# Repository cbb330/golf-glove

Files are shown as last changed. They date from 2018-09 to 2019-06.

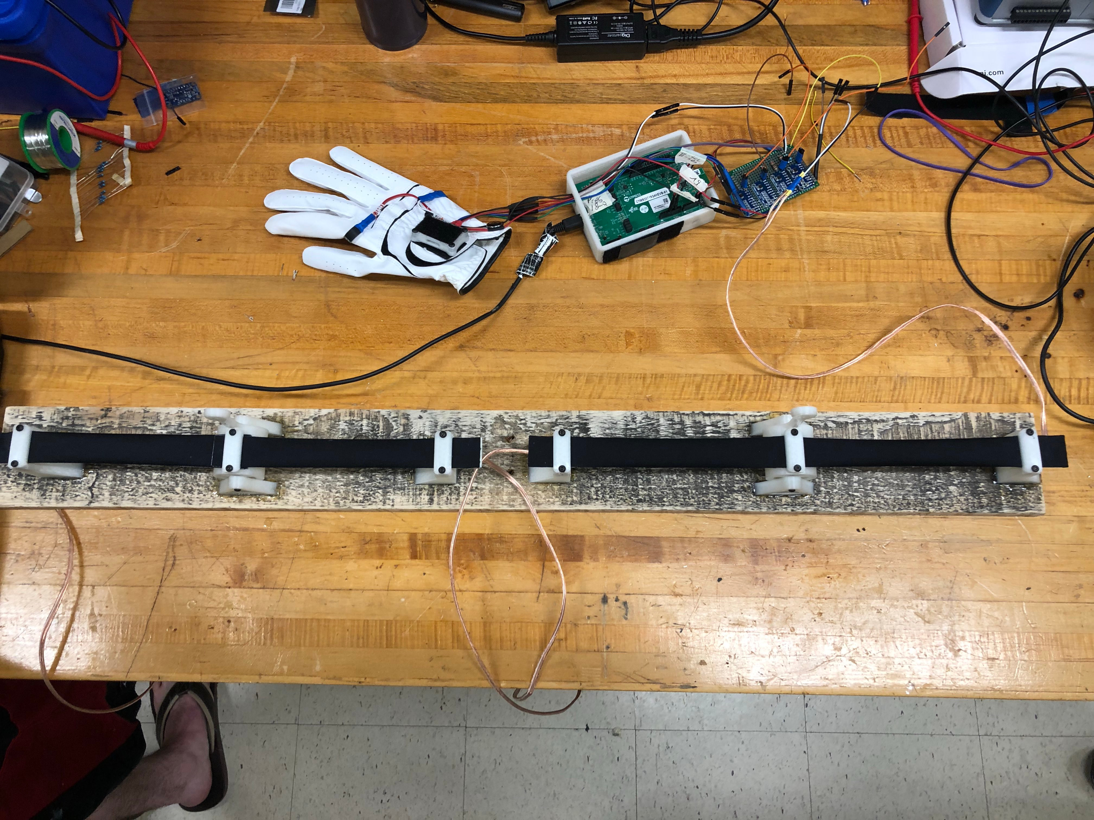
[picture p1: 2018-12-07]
website/images/hardware_demo1.jpg

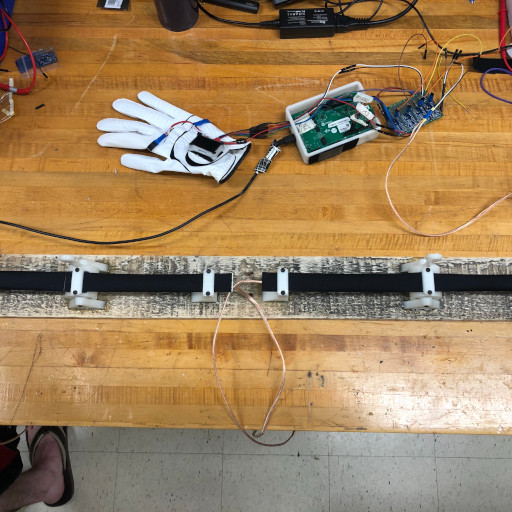
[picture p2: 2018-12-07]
website/images/hardware_demo1_reduced.jpg

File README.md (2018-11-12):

# Golf Glove
Senior Design Repository

## Firmware Quick-Reference
The Golf Glove device uses Bluetooth Low Energy (minimum BT v4.0) using the [Generic ATTribute](https://en.wikipedia.org/wiki/Bluetooth_Low_Energy#GATT_operations) (GATT) profile, an application layer protocol.

* [Golf Glove GATT Service Reference](firmware/GATT.md)

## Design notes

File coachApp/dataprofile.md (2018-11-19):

# Golf Glove Frontend Data Reference

## test route
```javascript
{
  timestamp: number,
  pressure1: number,
  pressure2: number,
  deflection: number,
  extension: number,
  radialDeviation: number,
  ulnarDeviation: number,
  imu1: {
    accelX: number,
    accelY: number,
    accelZ: number,
    magX: number,
    magY: number,
    magZ: number,
    gyroX: number,
    gyroY: number,
    gyroZ: number
  },
  imu2: {
    accelX: number,
    accelY: number,
    accelZ: number,
    magX: number,
    magY: number,
    magZ: number,
    gyroX: number,
    gyroY: number,
    gyroZ: number
  },
  swingSync: ['0', '1', '2'],
  dataAvailable: boolean
}
```

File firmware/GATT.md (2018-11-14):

# Golf Glove GATT Service Reference #

## `golf-glove` Service ###
| Property | Value |
| --- | --- |
| Name | `golf-glove` |
| UUID | `3a c5 98 d6 1b 7e 42 2e b5 f1 34 fe 48 89 83 7c` (MSB -> LSB) |
| Description | Vendor Specific Service: golf_glove |

### `next_frame` Characteristic ###
| Property | Value |
| --- | --- |
| Name | `next_frame` |
| UUID | `5a 41 42 57 d5 13 4c 6f b8 ab 53 43 8a 86 35 6c` (MSB -> LSB) |
| Actions | Read, Notify, Indicate |
| Description | Returns the data frame from the front of the data buffer, if no frame is present, an empty frame will be sent. |

The data returned by reading this characteristic is a **54-byte** value with the following format:

| Bytes | Name | Encoding |
| --- | --- | --- |
| 0-3 | Timestamp | Unsigned 32-bit counter that increments by 1 for each frame. Can be converted to a time offset for frames by multiplying the difference in two frames' timestamps by 1 / Sensor Refresh Rate. |
| 4-5 | Pressure Sensor 1 | Unsigned 16-bit integer indicating the pressure applied to Pressure Sensor 1. |
| 6-7 | Pressure Sensor 2 | [See above] |
| 8-9 | Wrist Deflection | Unsigned 16-bit integer representing the angle of wrist deflection as indicated by the upper soft robotic sensor. |
| 10-11 | Wrist Extension | Unsigned 16-bit integer representing the angle of wrist extension as indicated by the lower soft robotic sensor. |
| 12-13 | Radial Deviation | Unsigned 16-bit integer representing the angle of radial deviation (turning of the right hand to the left, or vice versa) as indicated by the outside soft robotic sensor. |
| 14-15 | Ulnar Deviation | Unsigned 16-bit integer representing the angle of ulnar deviation (turning of the right hand to the right, or vice versa) as indicated by the inside soft robotic sensor. |
| 16-33 | Wrist IMU | Inertial data as indicated by wrist-mounted IMU [See table below for details] |
| 34-51 | Hand IMU | Inertial data as indicated by hand-mounted IMU [See table below for details] |
| 52-53 | Swing Sync | 0 = middle of swing or real-time mode data point, 1 = beginning of swing, 2 = end of swing |
| 54-55 | Data Available | 0 = no more frames to fetch in frame buffer, 1 = more frames to fetch in frame buffer |

IMU Data Format:

| Bytes | Name | Encoding |
| --- | --- | --- |
| 0-1 | Acceleration X | Signed 16-bit integer indicating acceleration on the X axis -32768 to 32767 scales to +/- 2g. |
| 2-3 | Acceleration Y | Signed 16-bit integer indicating acceleration on the Y axis -32768 to 32767 scales to +/- 2g. |
| 4-5 | Acceleration Z | Signed 16-bit integer indicating acceleration on the Z axis -32768 to 32767 scales to +/- 2g. |
| 6-7 | Magnetic Field X | Signed 16-bit integer indicating magnetic field on the X axis -32768 to 32767 scales to +/- 4 gauss. |
| 8-9 | Magnetic Field Y | Signed 16-bit integer indicating magnetic field on the Y axis -32768 to 32767 scales to +/- 4 gauss. |
| 10-11 | Magnetic Field Z | Signed 16-bit integer indicating magnetic field on the Z axis -32768 to 32767 scales to +/- 4 gauss. |
| 12-13 | Rotation X | Signed 16-bit integer indicating rotation on the X axis -32768 to 32767 scales to +/- 2000 dps. |
| 14-15 | Rotation Y | Signed 16-bit integer indicating rotation on the Y axis -32768 to 32767 scales to +/- 2000 dps. |
| 16-17 | Rotation Z | Signed 16-bit integer indicating rotation on the Z axis -32768 to 32767 scales to +/- 2000 dps. |

### `realtime_enabled` Characteristic ###
| Property | Value |
| --- | --- |
| Name | `realtime_enabled` |
| UUID | `59 92 53 7e 1b 6d 41 78 ba 27 22 fa b3 8c e4 72` (MSB -> LSB) |
| Actions | Read, **TODO: WRITE**, Notify, Indicate |
| Description | Sets whether the swing detection algorithm will be used or if data will be continuously streamed to the device. |

### `data_available` Characteristic ###
| Property | Value |
| --- | --- |
| Name | `data_available` |
| UUID | `90 93 34 aa c6 ce 4b d0 95 ab 73 98 33 ae f7 bd` (MSB -> LSB) |
| Actions | Read, Notify, Indicate |
| Description | Returns a boolean value indicating whether data is available to be read from the frame buffer. |

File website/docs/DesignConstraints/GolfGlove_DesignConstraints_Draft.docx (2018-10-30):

# 2. Design Requirements/Constraints

The golf glove will use an unobtrusive design consisting of stretch and orientation sensors to accurately measure the movement of the hand and display this information to the golfer. The glove will consist of two systems: the garment with integrated peripherals, and a wrist-mounted controller. The controller will gather the information gained from the integrated sensors, and broadcast it to a desktop application that will receive and process this information. This data will then be displayed to the user and allow the user to gain valuable insight into his/her swing. In order to make this product functional, as well as acceptable to the consumer, there are technical and practical design constraints.

## 2.1. Technical Design Constraints

Table 2.1. Technical Design Constraints

Name | Description
Hand Orientation and Position | The glove must accurately determine wrist flexion and extension, wrist deviation, wrist acceleration, hand orientation, and hand acceleration.
Wireless Communication | The wrist-mounted controller must communicate wirelessly with a minimum range of 20 feet.
Data Display | The system will communicate its measurements to a desktop in real-time where an application will display them through a simple interface in a web browser.
Comfortable | The user must not feel obstructed while gripping the club with the glove on.
Portability | The wrist-mounted microcontroller must be battery powered and not require recalibration on startup.

### 2.1.1 Hand Orientation

The golf glove must measure forearm, wrist, and hand orientation to within a 5° margin of error and the hand position within a 5cm margin of error. The position measurement will be used to calculate velocity and acceleration of the hands. These margins of error will allow the glove to fulfill its purpose of tracking the wrist’s biomechanics to such a degree that meaningful feedback can be given to the user.

### 2.1.2 Wireless Communication

The golf glove must be able to reliably maintain a connection with the data display over a maximum distance of 20 feet. This enables the user to use the product without keeping the mobile device on their person. Users must be able to store mobile devices nearby, as in a golf cart or bag, while still connected so that recorded golf swings can be easily viewed after performing one or more hits. In the event of a lost wireless connection, the golf glove must be able to store several golf swings on-board until the connection is reestablished.

### 2.1.3 Data Display

The golf glove will transmit data to a computer where an application will display the measured data. A display is necessary to show the gathered data to the user in addition to providing feedback, an essential component of the system. The application will be web-based to allow similar interaction on a mobile device in the future.

### 2.1.4 Comfortable

The target audience for this product is a golfer that is trying to improve. Therefore, the golf glove will aim to be as unobtrusive to the golfer’s performance as possible. The hand will be covered with intricately placed sensors that will not require a readjustment in grip and will not induce friction to the user. Also, the wrist housing will not prevent proper flexion and extension throughout the swing.

### 2.1.5 Portability

The device must be small enough to fit comfortably on the user’s wrist without hindering or hampering their normal golf technique. A system that negatively affects the user’s swing defeats the device’s purpose given the device must accurately be able to track the user’s swing. The device must also utilize a battery system to avoid any lengthy wires that may hinder user performance. The device must not require any additional calibration steps from the user. By removing the need to calibrate before every use, the user is required to complete less work to get the device up and running, allowing for quick and easy use of the device. The entire system must be able to fit in a pocket of the user’s golf bag either , allowing the user to easily bring the device onto the golf course without any separate carrying case or bag.

## 2.2. Practical Design Constraints

The table below details the practical design constraints to be considered while designing the glove.

Table 2.2 Practical Design Constraints

Type | Name | Description
Economic | Cost | The golf glove must cost less than $200.
Environmental | Weather-Resistant | The glove must be IP54 water and dust resistant.
Health and Safety | Swing Form | The glove encourages proper swing form which helps prevent unnecessary stress and injury.
Manufacturability | Modular/Replaceable Parts | The glove unit will need to be modular to accommodate different glove sizes and handedness.
Sustainability | Battery Life, Safety, and Rechargeability | The glove must have a battery life of at least 5 hours for an 18-hole round of golf.

### 2.2.1 Economic

The total cost of the sensor glove and controller must be under $200 in order to make the golf glove competitive to other products on the market. Though some other golf tracking products are in this price range, the additional functionality available with the golf glove through flexion and extension sensors justifies the price. The golf glove must be replaceable separately from the controller in order to further improve affordability for the user.

### 2.2.2 Environmental

Due to sustained use in potentially wet and/or dusty environments, the product design must conform to the Ingress Protection (IP) standard. Specifically, our product needs to pass the IP54 standard described in the EN 60529 standard document [1]. The product’s main enclosure and sensors will be shielded from dust accumulation and water sprays.

### 2.2.3 Health and Safety

Since the product is designed to be used as a training aid it must not harm the user during normal operation. One of the objectives to the golf glove is to promote good swing technique and indicate to the user about behavior that is hazardous to health, such as gripping too hard in the top half of the hand during swinging. The glove will be made out of materials appropriate to remain comfortable for the product’s sustained use. Also, the golf glove must remain operational

### 2.2.4 Manufacturability

The design much make efficient use of current off-the-shelf systems wherever possible. Creating a “System of Systems” removes potential issues caused by working with new or unfamiliar technologies. Therefore, it will be important to utilize systems that have large amounts of community and/or manufacturer support. The system must be swappable between different glove sizes and shapes, allowing users of different hand sizes to use the system effectively. In the event of a depleted battery, the system must account for user/technician replacement to reduce waste and allow for prolonged system use. Components and housing must be designed to decrease the complexity of manufacturing allowing for an efficient creation on a production line.

### 2.2.5 Sustainability

The design must contain a battery/power-system that is sufficient to power the device for a minimum of 5 hours. This will allow the user to effectively use the device throughout an average 18-hole round of golf. The power-system must contain a protection circuit to prevent over-discharge, overcharge, and short circuit situations. Over-discharge can occur when the user forgets to turn the device off, and will permanently damage the battery. Overcharge can occur in the event of a charger malfunction and can cause rapid discharge of the battery. Lastly, short circuits can occur in events of corrosion, and internal shorts in the circuit. A protection circuit is necessary to protect the user from these potential, scenarios. The glove must be able to charge in under 2.5 hours using either an on-board charging circuit or an external charger. By keeping the charge time below 2.5 hours, the user can theoretically charge between holes or “hot swap” between multiple wrist units. Ideally the charging time should be less than or equal to half of the operating time of the device.

# References

[1] Secure Systems and Technologies. (2018). Ingress Protection. [online] Available at: http://sst.ws/downloads/Ingress-Protection-iss-4.pdf [Accessed 19 Sep. 2018].

Golf Glove 2018

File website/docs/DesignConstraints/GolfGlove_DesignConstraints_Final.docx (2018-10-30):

# 2. DESIGN REQUIREMENTS/CONSTRAINTS

The Golf Glove must have an unobtrusive design that incorporates stretch and orientation sensors. These sensors are crucial to the product’s goal of accurately measuring hand movement that will be displayed to the user. The design must consist of three systems: the garment with integrated peripherals, the wrist-mounted controller, and the coaching software. The garment must measure the user’s hand orientation, hand velocity, and wrist motion via its integrated sensors and pass these metrics to the controller. The controller must then broadcast the swing data to a desktop coaching application. This application must display the data giving the user valuable insight into their swing. To achieve the expected functionality and appeal to the user, the design must conform to the following technical and practical design constraints.

## 2.1. Technical Design Constraints

The Golf Glove must collect data, incorporate a real-time display, and be convenient to the user. Table 2.1 identifies five constraints to the technical performance of the system that will be further detailed in their respective subsections. The device must meet these constraints to ensure accurate and reliable function.

Table 2.1. Technical Design Constraints

Name | Description
Hand Orientation | The glove must determine the angles of wrist flexion, extension, and deviation within a 3° margin of error. Also, the glove must measure wrist acceleration, hand orientation, and hand acceleration within a 5% margin of error.
Wireless Communication | The wrist-mounted controller must communicate wirelessly with a range that will span the average width of a tee box: 30 feet.
Data Display | The system must communicate its measurements to a visual application that will display these metrics through a simple interface. The data can be analyzed after recording a swing, or real-time with both modes supporting a data rate of 100 hertz.
Unobtrusive | The user must not be obstructed while gripping the club with the glove on. The wrist-mounted computer must have a footprint smaller than the average sweat-band size of 3 inches. The sensor wires in the glove must not interfere with swing motion.
Portability | The wrist-mounted controller must be battery powered and not require manual calibration on start-up. The minimum battery life of the system must exceed 5 hours of use.

### 2.1.1. Hand Orientation

The Golf Glove must measure forearm, wrist, and hand orientation to within a 3° margin of error and the hand velocity within a 5% margin of error. The standard shaft length for a driver golf club is 1.1 m [1]. Using this measurement, a 3° rotation of the wrist amounts to a 5.8 cm movement of the club head, which allows the club head location to be estimated to within one-half of its length [2]. The average golfer’s swing speed is about 32 m/s, meaning a 5% margin of error in hand velocity will measure the swing speed to within 1.2 m/s [3].

### 2.1.2. Wireless Communication

The Golf Glove must maintain a connection with the data display up to a maximum distance of 30 feet. According to Jeff Brauer, a columnist for Golf Course Industry, tee box dimensions vary due to number of expected players. He states that the white tee box, the most common tee box to start from, is normally the only one that may exceed 30 feet in width [4]. Conforming to this constraint enables the product to be fully operational without making the user keep a computer device on their person. Users can store mobile devices nearby, as in the user’s pocket or in a golf cart, while still connected. In the event of a dropped wireless connection, the Golf Glove must be able to store several golf swings in memory until the connection is reestablished.

### 2.1.3. Data Display

The Golf Glove must transmit data to a computer application that will display the measured data. A display application is necessary to show the gathered data to the user in addition to providing feedback, an essential component of the system. The display must incorporate graphs to show hand pressure, hand acceleration, hand rotation, wrist flexion, and wrist extension over time. The device must be capable of collecting data in two modes. In Swing Detection Mode, data must be recorded upon swing detection and sent to the display application upon swing conclusion. The application can then analyze the swing data as one complete motion. A second mode, Real-Time Mode, must collect the sensor data and transmit it to the display application as it is collected. Real-time data display allows the user to practice certain key postures during the swing and ensure that their wrist angles and positions are correct.

### 2.1.4. Unobtrusive

Since the target audience for this product is a golfer who is trying to improve, the Golf Glove must be as unobtrusive to the golfer’s swing performance as possible. On average, male’s hands are larger than female hands. In order to fit most of our users, we need a circuit board footprint that can be small enough to fit on both genders. The average width of a female’s hand is 7.52 cm [5]. Therefore, the device’s footprint must be less than 4 cm in length and width to fit comfortably on the back of the hand.

Also, the wrist housing must not impede proper flexion and extension so the user can maintain a full range of motion. The two main factors for the size of the wrist controller are band width and circumference. The band’s width must be larger than 3 in, the width of a common sweat band. The circumference must be adjustable from 5.5 in to 9 in to accommodate a normal range of wrist sizes [6].

### 2.1.5. Portability

To avoid lengthy wires that may hinder user performance, the device must incorporate a battery system. Additionally, the Golf Glove must not require any additional calibration steps from the user. By removing the need to calibrate, the user avoids an unnecessarily delay in their swing preparation. The garment and controller system must fit in a user’s golf bag pocket, allowing the user to easily bring the device onto the golf course without a separate carrying case or bag.

## 2.2. Practical Design Constraints

Table 2.2 details the practical design constraints for the glove design. Five practical design constraints were selected: economic, environmental, health and safety, manufacturability, and sustainability. Adhering to these constraints will create a low-cost solution that is suited to a golf environment and ultimately values user ease-of-use.

Table 2.2. Practical Design Constraints

Type | Name | Description
Economic | Cost | The Golf Glove must cost less than $200.
Environmental | Weather-Resistant | The glove must be IP54 water and dust resistant.
Health and Safety | Swing Form | The glove must encourage proper swing form which helps prevent unnecessary stress and injury.
Manufacturability | Modular/Replaceable Parts | The garment and controller must be modular and allow swapping if a subsystem fails.
Sustainability | Battery Life, Safety, and Rechargeability | The glove must have adequate battery life of at least 5 hours.

### 2.2.1. Economic

The total cost of the sensor glove and controller must be under $200 to make the Golf Glove competitive to other products on the market. Although other golf tracking products are around this price, the Golf Glove’s additional functionality that specifically tracks and analyzes wrist movement through flexion and extension sensors justifies the price. Additionally, the glove component must be separate from the controller to make either part replaceable for a lower cost than replacing the entire device.

### 2.2.2. Environmental

Due to the need for sustained use in potentially wet or dusty environments, the Golf Glove’s design must conform to the Ingress Protection (IP) standard. The product’s main enclosure and sensors must be unaffected by dust accumulation and water sprays.

### 2.2.3. Health and Safety

Since the Golf Glove is designed to be a consumer training aid, it must not harm the user during normal operation. The main objective for the device is to promote proper swing technique; this includes indicating and correcting improper and harmful form. For example, gripping the golf club too hard in the top half of the hand during a swing can result in elbow injuries [7]. The glove will measure pressure on the top and bottom halves of the palm so that the user can be notified when they are putting too much pressure on the club with the wrong fingers. The coaching application must compare the users swing to one with proper form to identify deviations from proper technique. Promoting proper technique will result in fewer unnecessary injuries. Following, the device must inherently promote the user’s health.

### 2.2.4. Manufacturability

The design must efficiently use of modern, easily-sourced components wherever possible. Therefore, Golf Glove must use components that have large amounts of community and manufacturer support. The garment and wrist controller must be modular to allow the user to replace either piece without having to replace the other. In the event of a depleted battery, the system must account for replacement to reduce waste and allow for prolonged system use. The components and housing must allow for efficient creation on a production line.

### 2.2.5. Sustainability

The design must contain a battery system of sufficient capacity to power the device for a minimum of 5 hours. This time constraint will ensure the device is operation throughout an average 18-hole round of golf [8]. The power system must contain a protection circuit to prevent overcharge, overdischarge, and short circuit situations. Overdischarge occurs when the user forgets to turn the device off and results in a permanently damaged battery. Overcharge occurs in the event of a charger malfunction and can cause rapid discharge of the battery into unwanted places. Overcharge and overdischarge are characterized by the battery reaching a voltage over 4.2 V or under 3.0 V respectively [9]. Lastly, short circuits occur in events of corrosion and cause may damage to the circuit itself. The battery must charge in under 2.5 hours so that the user could theoretically charge it between their free time between golf holes.

## 2.3. Appropriate Engineering Standards

The engineering standards identified in Table 2.3 target the environmental and health and safety constraints for the device.

Table 2.3. Appropriate Engineering Standards

Specific Standard | Standard Document | Specification/Application
IP54 | EN 60529 | Rule 5 for dust protection states that the dust quantity allowed to enter or deposit on the system does not impact the system’s functionality. Rule 4 for water protection states that water sprayed from any direction against the machine must not cause damage [10].
Restriction of Hazardous Substances Compliance | RoHS-1 | The device must not contain substances banned under RoHS [11].
ICNIRP High Frequency EMR Guidelines | ICNIRP | Whole body and local body Specific Absorption Rate due to human exposure to RF fields from wireless devices must not exceed certain levels [12].

### 2.3.1. Environmental

The device must adhere to the IP54 standard. Defined in Table 2.3, the IP54 standard qualifies the dust and water ingress to the device. IP54 provides a sufficient level of protection from both dust and water, which are two environmental factors that golfers often face. The standard states that while water and dust may interact with the device, the device operation must not be harmed [10].

### 2.3.2. Environmental Materials

The device must be RoHS compliant. RoHS details several hazardous materials that should not be used in consumer products. To achieve compliance, the design must not contain any of the materials listed so that the device will not result in excess pollution when discarded or cause harm to the user. RoHS is defined in depth throughout Directive 2002/95/EC of The European Parliament [13].

### 2.3.3. Health and Safety

The device must conform to the International Commission on Non-Ionizing Radiation Protection (ICNIRP) standards for limiting exposure to electromagnetic radiation (EMR) fields. To achieve this, the device radiation will be measured with International Electrotechnical Commission (IEC) 62209 which defines standards surrounding the Specific Absorption Rate (SAR) due to human interaction with Radiofrequency (RF) EMR [14]. Following the ICNIRP threshold of General Public Exposure for mobile devices, the device’s whole-body SAR rating must not exceed 0.8 Watts per Kilogram (W/kg) and local-body SAR rating must not be above 4 W/kg [14].

# References

[1] “Standard Lengths,” GolfWorks. [Online]. Available: https://www.golfworks.com/images/art/StdLengths.pdf. [Accessed: 23-Sep-2018].

[2] “Driver-Head-Shapes and dimensions,” Cast irons and Forged Irons, Manufacturing and Materials. [Online]. Available: http://www.golfclub-technology.com/driver-head-shapes.html. [Accessed: 23-Sep-2018].

[3] “Average Golf Swing Speed Chart,” Swing Man Golf – Blog, 22-May-2018. [Online]. Available: http://www.swingmangolf.com/average-golf-swing-speed-chart-2/. [Accessed: 23-Sep-2018].

[4] J. Brauer, “Practical Tee Design,” Golf Course Industry, 08-Aug-2006. [Online]. Available: http://www.golfcourseindustry.com/article/practical-tee-design--design-column-/. [Accessed: 05-Oct-2018].

[5] C. Wang, “Hand tool handle design based on hand measurements,” MATEC Web Conf. [Online]. Available: https://www.matec-conferences.org/articles/matecconf/pdf/2017/33/matecconf_imeti2017_01044.pdf [Accessed: 24-Sep-2018].

[6] L. Vorvick, “Calculating body frame size: MedlinePlus Medical Encyclopedia Image,” MedlinePlus, 13-Jul-2016. [Online]. Available: https://medlineplus.gov/ency/imagepages/17182.htm. [Accessed: 24-Sep-2018].

[7] Cole, M. H., & Grimshaw, P. N. (2016). The biomechanics of the modern golf swing: implications for lower back injuries. Sports Medicine, 46(3), 339-351.

[8] B. Kelley, “How Long Does It Take to Play a Round of Golf?,” ThoughtCo. [Online]. Available: https://www.thoughtco.com/time-it-takes-to-play-a-round-1560498. [Accessed: 24-Sep-2018].

[9] “Lithium Polymer Charging/Discharging & Safety Information,” MaxAmps.com. [Online]. Available: https://www.maxamps.com/lipo-care.php. [Accessed: 24-Sep-2018].

[10] Secure Systems and Technologies. (2018). Ingress Protection. [Online] Available at: http://sst.ws/downloads/Ingress-Protection-iss-4.pdf [Accessed 19 Sep. 2018].

[11] RoHSguide.com, RoHS Guide. http://www.rohsguide.com/rohs-faq.htm. [Accessed: 27-Sep-2018]

[12] Standard, I. E. C. 62209-2: Human Exposure to Radio Frequency Fields from Hand-Held and Body-Mounted Wireless Communication Devices Human Models. Instrumentation, and Procedures—Part, 1. [Accessed: 25-Sep-2018].

[13] Directive, R. (2003). Directive 2002/95/EC of the European Parliament and of the Council of 27 January 2003 on the restriction of the use of certain hazardous substances in electrical and electronic equipment. Official Journal of the European Union, 13, L37.

[14] Ahlbom, A., Bergqvist, U., Bernhardt, J. H., Cesarini, J. P., Grandolfo, M., Hietanen, M., & Swicord, M. L. (1998). Guidelines for limiting exposure to time-varying electric, magnetic, and electromagnetic fields (up to 300 GHz). Health physics, 74(4), 494-521.

ECE 4532: Design I October 4, 2018

Golf Glove 1

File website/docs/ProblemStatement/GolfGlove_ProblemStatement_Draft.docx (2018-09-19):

1. Problem Statement

1.1 Historical Introduction

The game of golf can be traced back to the middle ages. It began with simple wooden clubs and leather balls in Scotland, and spread internationally through Great Britain’s colonial conquests. The game was traditionally played by royals, but was further popularized by the railroad industry in the 1800’s to allow tourists to participate in the countryside where golf courses were located. The industrial revolution further propelled the game, allowing iron molding of clubs and mass production of equipment.

Throughout the 1900’s, golf became a household sport and created several superstars wielding increasingly advanced equipment. Not only has the sport been around for almost one thousand years, but it is obvious that players will use engineering to gain an advantage in their performance.

Modern data analytics and smartphone technology has revolutionized golf. Today’s golfers can receive personalized on-course training through smartphone apps. Bluetooth sensors measure acceleration and position data during a swing, relaying the position data of a swing wirelessly to the app. The golf glove aims to increase the accuracy of recorded swing data by including additional sensors to measure hand movement, providing an even higher resolution dataset to provide feedback on.

1.2 Market and Competitive Product Analysis

The golf glove is marketed towards tech-savvy golfers that may not always have enough money to afford a coach and is designed to be a cost effective alternative to gathering information on one’s golf technique. On average, golfers spend $2,776 annually on golfing related expenses [2]. The golf glove is specifically marketed at enthusiasts that want to improve their swing. Comparatively, driving ranges such as Top Golf service millions of new members every year and have become of the largest driving range chains in the country. With an average customer spending rate of $35/visit the golf glove could be integrated with a system such as Top Golf’s to give visitors “on-the-fly” tips and techniques on their swing [3]. Patrons could rent the glove for a small fee and use it during their visit.

There exists on the market several other systems that can track a player’s hand and club movement, but none that track wrist movement and grip pressure. The Garmin TruSwing and Skypro both cost $150, clip onto a golfer’s club and track club movement through the use of accelerometers and gyroscopes. Other systems involve screwing in sensors to the top of a golfer’s club, and cost around 16$ per sensor [4]. The golf glove is designed to offer a wider variety of data at or below the price point of these inferior systems on the market. Rather than tracking a golfer’s swing solely on gyroscope and accelerometer data, the golf glove integrates flexible sensors that can track wrist inflection, rotation, and grip pressure. This sensor array will offer a much higher resolution of a golfer’s swing and technique.

1.3 Concise Problem Statement

The golf glove is designed to provide an affordable and lasting alternative to a coach. This product stands out from other products as it provides a system for measuring wrist flexion and extension, a combination of sensors that do not require recalibration by the user, and a physical package that is reusable and can last throughout many training sessions. Golf glove is a wireless system that can be paired to any smart device using a downloaded application. The system utilizes an accelerometer, a gyroscope, a pressure sensor, and resistive stretch fabric to gather real-time information of a player’s swing.

1.4 Implications of Success

The golf glove provides golfers with a training tool to track and analyze their swing at an affordable price. Following, the golf glove unlocks the benefits of data-driven training for a significant population. The data captured and analyzed by the device provides feedback to the user, helping them to understand the flaws in their swing. Correcting these flaws will improve the user’s golf swing and bring consistency to their overall golf game.

Additionally, the golf glove has applications in the professional market where it can assist swing coaches in their craft. Specifically, the golf glove makes benchmarking and tracking player improvement a breeze by attaching raw data to a swing. The precision of the device will also help swing coaches locate small inconsistencies in a player’s swing that otherwise might be overlooked.

The functionality that the golf glove provides has the ability to revolutionize golf swing training. If a golfer is able to consistently strike the ball with proper mechanics, they will also be able to consistently record respectable, and thus enjoyable, rounds of golf. More enjoyable golf rounds results in both more golf being played and a greater chance that the player introduces the sport or our product to a non golfer. As a result, the sport and market will grow.

References

[1] A. Clark, "Millennials are breathing new life into stodgy golf: Here's how the industry is responding", CNBC, 2018. [Online]. Available: https://www.cnbc.com/2017/08/12/millennials-breathing-new-life-into-golf-and-heres-how-the-industry-is-responding.html. [Accessed: 03-Sep-2018].

[2] A. Josephson, "The Economics of Golf", SmartAsset, 2018. [Online]. Available: https://smartasset.com/retirement/the-economics-of-golf [Accessed: 03-Sep-2018].

[3] “Pricing | Topgolf Allen,” Topgolf. [Online]. Available: https://topgolf.com/us/allen/pricing/. [Accessed: 04-Sep-2018].

[4] D. Johnson, “Best golf swing analyzers and shot trackers,” Gadgets & Wearables, 22-Apr-2018. [Online]. Available: https://gadgetsandwearables.com/2018/04/22/golf-swing-analyzer/. [Accessed: 04-Sep-2018]

ECE 4512: Design I September 6, 2018

Golf Glove 2018 2

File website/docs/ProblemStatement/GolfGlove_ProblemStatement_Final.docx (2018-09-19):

1. Problem Statement

1.1 Historical Introduction

The game of golf can be traced back to the middle ages. It began with simple wooden clubs and leather balls in Scotland, and spread internationally through Great Britain’s colonial conquests [5]. Through the 1900s, golf became a household sport and its players began wielding advanced equipment because of the increasing interest and subsequent innovation. In addition, the thirst for improvement was pervasive, evidenced by some of the earliest film showcasing golf experts and their swings. Clearly, players have an innate drive to improve their performance and are even willing to invest money for an advantage on the course.

Analysis of the golf swing has improved dramatically over the past few decades. As early as 1985, kinesiologists were able to analyze their subjects’ swings using a combination of phase-locked cameras and digital algorithms to determine the torque on the golfer’s joints [1]. Much more recently, the explosion of small, inexpensive, solid-state electronics has brought swing analysis technology out of the research lab and into the average user’s hands.

Modern data analytics and smartphone technology continue to revolutionize golf. Today’s golfers can receive personalized on-course training and information through smartphone apps. Bluetooth sensors measure acceleration and position data during a swing, relaying the position data of a swing wirelessly to the app. The golf glove aims to increase the accuracy of recorded swing data by including additional sensors to measure hand movement, providing an even higher resolution dataset to provide feedback on.

1.2 Market and Competitive Product Analysis

The golf glove is marketed towards tech-savvy golfers that may not always have enough money to afford a coach and is designed to be a cost effective alternative to gathering information on one’s golf technique. On average, golfers spend $2,776 annually on golfing related expenses [2]. The golf glove is specifically marketed at enthusiasts that want to improve their swing. Comparatively, driving ranges such as Top Golf service millions of new members every year and have become of the largest driving range chains in the country. With an average customer spending rate of $35 per visit, the golf glove could be integrated with a system such as Top Golf’s to give visitors “on-the-fly” tips and techniques on their swing [3]. Patrons could rent the glove for a small fee and use it during their visit.

There exists on the market several other systems that can track a player’s hand and club movement, but none that track wrist movement and grip pressure. The Garmin TruSwing and Skypro both cost $150, clip onto a golfer’s club and track club movement through the use of accelerometers and gyroscopes. Other systems involve screwing in sensors to the top of a golfer’s club, and cost around $16 per sensor [4]. These systems only focus on a golfer’s club movement using a club-mounted gyroscope and accelerometer; they ignore important biomechanical data. The golf glove is designed to offer more useful data at or below the price point of these inferior systems on the market. Rather than solely tracking the golf club, the golf glove integrates flexible sensors that track biomechanical data of wrist inflection, rotation, and grip pressure. Additionally, the golf glove is designed to reduce the risk of wrist and elbow injuries by encouraging proper swing technique through data feedback.

1.3 Concise Problem Statement

The golf swing training tools that are currently on the market are either prohibitively expensive or only focus on club movement. Meanwhile, a professional coaching session may look at club movement, but these sessions are similarly expensive and also temporary.

The golf glove is designed to be an affordable and lasting solution to these issues. Utilizing an array of sensors including an accelerometer, a gyroscope, a pressure sensor, and resistive stretch fabrics, the glove will track the hand and arm biomechanics that control the golf swing. The data that these sensors collect will be analyzed and used to give training feedback to the user. Essentially, instead of showing the user their symptom that is poor club movement, our product will show the user the root cause of their swing problems: poor biomechanics. The golf glove is a wireless system that can be paired to any smart device or computer using a downloadable application.

1.4 Implications of Success

The golf glove provides golfers with a training tool to track and analyze their swing at an affordable price. It unlocks the benefits of data-driven training for a significant population. The data captured and analyzed by the device provides feedback to the user, helping them to understand the flaws in their swing. Correcting these flaws will improve the user’s golf swing and bring consistency to their overall golf game.

Additionally, the golf glove has applications in the professional market where it can assist swing coaches in their craft. Specifically, the golf glove makes benchmarking and tracking player improvement a breeze by attaching raw data to a swing. The precision of the device will also help swing coaches locate small inconsistencies in a player’s swing that otherwise might be overlooked.

The functionality that the golf glove provides has the ability to revolutionize golf swing training. By collecting swing data and evaluating it for form correctness, the golf glove can suggest improvements to the golfer. Taking this training feedback into account, a golfer is able to take steps to improve their swing mechanics. By consistently strike the ball with proper mechanics, they will also be able to consistently record respectable, and thus enjoyable, rounds of golf. More enjoyable golf rounds results in both more golf being played and a greater chance that the player introduces the sport or our product to a non-golfer. As a result, the sport and market will grow.

References

[1] R. Neal, “3D Kinematics and Kinetics of the Golf Swing,” International Journal of Sport Biomechanics, 1985. [Online]. Available: https://journals.humankinetics.com/doi/abs/10.1123/ijsb.1.3.221. [Accessed: 12-Sep-2018]

[2] A. Josephson, “The Economics of Golf,” SmartAsset, 2018. [Online]. Available: https://smartasset.com/retirement/the-economics-of-golf. [Accessed: 03-Sep-2018].

[3] “Pricing | Topgolf Allen,” Topgolf. [Online]. Available: https://topgolf.com/us/allen/pricing/. [Accessed: 04-Sep-2018].

[4] D. Johnson, “Best golf swing analyzers and shot trackers,” Gadgets & Wearables, 22-Apr-2018. [Online]. Available: https://gadgetsandwearables.com/2018/04/22/golf-swing-analyzer. [Accessed: 04-Sep-2018].

[5] “History of Golf,” International Golf Federation. [Online]. Available: https://www.igfgolf.org/about-golf/history. [Accessed: 13-Sep-2018].

ECE 4512: Design I September 6, 2018

Golf Glove 2018

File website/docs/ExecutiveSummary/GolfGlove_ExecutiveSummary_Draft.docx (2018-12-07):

Executive Summary

When on the golf course, golfers have no accurate way of recording their swing and technique. While golfing innovation has improved over the years, the most common systems are bulky and unappealing to consumers. In order to help the golfer accurately record their swing for personal analysis, the Golf Glove was created. The Golf Glove is a system that consists of multiple inertial, pressure and flex measurement units that can accurately track and record a golfer’s swing in real time. The system is broken down into three subsystems which are the glove garment, the wrist mounted controller, and the coaching application as described in figure 1.

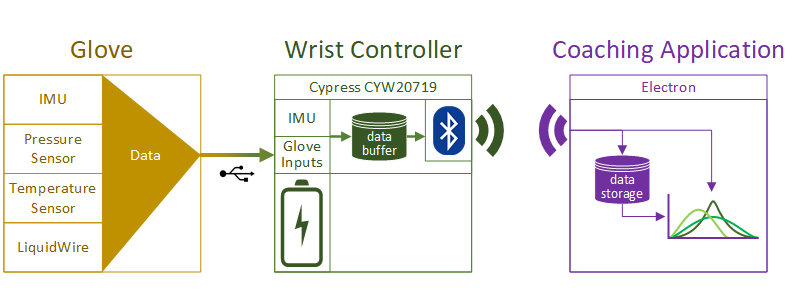
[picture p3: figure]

Figure 1: Golf Glove System Architecture

Some main constraints of the overall Golf Glove design will be the wireless transmission speed and the resolution of the various measurement sensors. The entire system must be able to fit onto a standard golf glove as well as a wrist mounted unit that is no wider than a standard sweatband (3”). The Golf Glove must also be able to be recharged to allow for multiple golfing sessions. Seeing as the Golf Glove will be used outside, the system must be able to handle harsh environments with features such as splash resistance, and resistance to freezing and hot temperatures. Finally, the system talks wirelessly to the application and therefore must be able to transmit across the length of an average golf tee box.

Each Golf Glove system is comprised of a Microcontroller, two IMU’s, two pressure sensors, 4 LiquidWire stretch sensors, and a battery all located in both a back hand and wrist mounted unit. Two IMU’s were chosen to increase the tracking accuracy of the system. A large battery will be installed to continuously power the unit for 5 hours. The system uses LiquidWire stretch sensors to track the inflection and deviation of the wrist and were chosen due to their ability to be sewn into the glove itself with minimal obstruction to the user. The Golf Glove communicates to the mobile application through use of Bluetooth LE and will send packets containing the user’s golf swing data. Lastly, palm mounted pressure sensors will allow the system to detect the users grip force and were chosen due to their flexible and overall unobtrusive nature.

The Golf Glove improves on existing systems by shrinking the size of the control units, while adding the additional capability of tracking wrist movement through the use of flexible sensors. Possible improvements on the system include a 3D rendering of your golf swing, data tracking and intelligent feedback based on gathered data. Adoption of the Golf Glove system would increase the overall performance of participating customers, while also reducing the number of injuries associated with poor golf swing form.

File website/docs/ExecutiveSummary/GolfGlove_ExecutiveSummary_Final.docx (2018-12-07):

EXECUTIVE SUMMARY

Golf Glove offers golfers a revolutionary way of tracking one’s golf swing. In contrast to other systems, the Golf Glove is low-profile and convenient. When on the course, golfers have no accurate way of recording swing technique on their own. The Golf Glove is a system that consists of multiple inertial, pressure, and flex sensors that can accurately track and record a golfer’s swing in real time. This gathered data is used to provide real time coaching feedback to the golfer. The system, depicted in Figure 1, is comprised of three subsystems: the glove garment, the wrist-mounted controller, and the coaching application.

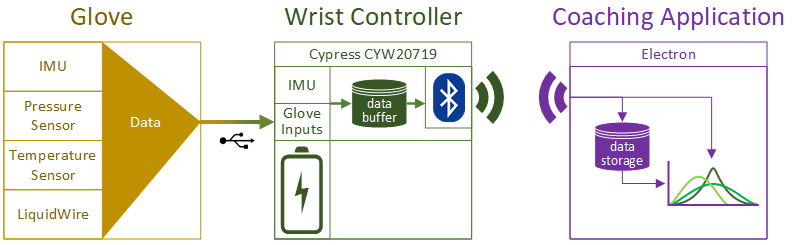
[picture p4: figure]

Figure 1. Golf Glove System Architecture

The main constraints of the Golf Glove design include the wireless transmission speed and the resolution of the various measurement sensors. Additionally, the entire system must be able to fit onto a standard golf glove and connect to a wrist-mounted controller that is no wider than a standard sweatband (3”). The Golf Glove will typically be used in outdoor environments; therefore, the system must be able to handle realistic environments with protections against water and dust ingression as well as moderate temperature conditions. Finally, the wrist-mounted controller must be battery powered and communicate wirelessly to the coaching application across 10 meters, the length of an average golf tee box.

The Golf Glove system contains a controller to record sensor data. Its array of sensors includes two accelerometers to track swing movement, two pressure sensors to read grip pressure, and four LiquidWire stretch sensors to measure wrist angle. Finally, a battery will be integrated to continuously power the device for at least 5 hours. The system uses a novel stretch sensor technology developed by LiquidWire to track the flexion and deviation of the wrist. LiquidWire sensors were chosen due to their ability to be sewn into the glove itself while being able to stretch without inhibiting function. The Golf Glove communicates via Bluetooth Low Energy to send packets containing the user’s swing data to the coaching application.

Golf Glove improves on existing systems by shrinking the system size and by adding the capability to track wrist movement via flexible sensors. Future improvements to the system may include 3D rendering of the user’s swing and generating intelligent feedback based on gathered data. Golf Glove provides an affordable and comprehensive solution by combining stretch sensors with the motion and pressure sensing capabilities of products currently on the market.

ECE 4512: Design I November 28, 2018

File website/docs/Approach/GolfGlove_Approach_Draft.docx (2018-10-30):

# 3. APPROACH

This document details the team’s approach to the design. The design will consist of the golf glove and wrist-mounted microcontroller subsystems. The glove subsystem will include linear stretch sensors and an accelerometer. Another accelerometer will be mounted on the controller. The controller will also contain a rechargeable battery. An electrical connector will pair the two subsystems. A desktop application will receive sensor data from the controller over Bluetooth and provide feedback to the user.

## 3.1. Hardware

The Golf Glove is composed of several subsystems outlined in the Design Constraints section of this document. In this section, critical components of each subsystem are compared and selected.

    3.1.1. Glove

The glove subsystem consists of the garment itself, linear stretch sensors, flexible pressure sensors and electrical connector components. The garment will provide mounting for the sensors. The sensors will receive power and transfer data to the controller through the electrical connector mounted on the glove.

3.1.1.1. Glove Garment

The glove garment is the mounting point for all of the linear stretch sensors, an accelerometer, and pressure sensors. A connector will also be mounted on the glove to connect to the controller, making the glove and controller exchangeable. For the initial prototype, two sizes of gloves will be created to fit different golfer’s hand sizes comfortably. The material used will be standard leather.

3.1.1.2. Linear Stretch Sensors

Crucial to the design of the Golf Glove is the choice of a linear stretch sensor. These sensors vary linearly in resistance or capacitance as the sensor stretches. They typically consist of some elastic material fused with a flexible resistive material or capacitive shape. The conductive material is applied to the elastic material such that the electrical characteristic varies linearly with lateral extension.

Two classes of linear stretch sensors were considered: LiquidWire and StretchSense. The team chose to use the LiquidWire class of sensors because of their resistive variability, low cost, and the existing relationship between the team and the manufacturer. StretchSense sensors vary linearly in capacitance as the sensor is stretched, while LiquidWire sensors vary in resistance, which requires a simpler circuit to measure with a microcontroller.

3.1.1.3. Flexible Pressure Sensors

The force between the user’s hands and the gold glove must be recorded accurately. Therefore, the team has decided the employ the use of flexible sensors to detect the force exerted by the golfer’s hand on the golf club. In Table 3.1 you will see the comparisons between different flexible.

Table 3.1 Flexible Pressure Sensor Comparison

Name | Diameter (mm) | Price (USD) | Resistance Range (Ohms) | Interface/Communication
Interlink 402 | 15 | 7 | Infinite-250 | Analog
Velostat Conductive Sheet | Custom | 3.95 | Variable | Analog

The team decided on selecting the interlink 402 resistive touch sensor because of its ability to be quickly and easily integrated into the system. This flexible sensor can be bent in a multitude of different shapes and is made with tinned probes that allow for easy and seamless connection to the main system. At 15mm in diameter, the sensor can be easily wrapped around the thumb pad of the glove and be measured through a simple resistor divider circuit. In comparison the the velostat conductive sheet, the interlink 402 sensor does not need to be cut or measured for each glove and its resistance value can be programmed into the firmware as a constant. While this sensor may be more expensive than the other option, it requires little work to integrate and is why the team selected it as our sensor.

3.1.1.4. Electrical Connector

The electrical connection between the glove mounted sensors and the wrist mounted unit must be both robust, and a standard that allows for multiple data inputs and outputs. Rather than create a new proprietary connector, the team has decided to use available standards because of their ease of use and overall support. In Table 3.2 you see the comparisons of different possible standards of connectors.

Table 3.2. Standard Connection Comparison

Standard | Number of Connections | Reversible | Max Power (A)
USB-C | 12 | Yes | 5
USB-Micro | 5 | No | 5
Cat-5 | 8 | No | .63

The team has decided to utilize a standard USB-C connection between the glove mounted sensors and the wrist mounted unit. By utilizing USB-C the glove will have more than enough power throughput and enough pins to transfer data into the wrist mounted microcontroller. The reversibility was the deciding factor in the team’s choice because a reversible connector removes possible confusion and frustration that a user may experience with other standards of connectors.

    3.1.2. Wrist-Mounted Controller

The wrist mounted controller contains several components critical to collecting and transmitting data to the user’s mobile device. This section compares options the team considered for each of these components.

3.1.2.1. Inertial Measurement Unit

The Golf Glove requires two inertial measurement units (IMUs)—one in the wrist-mounted controller and one on the back of the hand itself. These IMUs will measure acceleration of the hand and the rotation of the wrist. The LSM9DS1 IMU by STMicroelectronics was chosen by the team. The details that drove this decision are described in Table 3.3 and in the following paragraph below.

Table 3.3. Inertial Measurement Unit Feature Comparison

IMU | Cost (USD) | Power Draw (mA) | Accelerometer/Gyroscope | Magnetometer | Interface
STM LSM9DS1 | $ 6.14 | 4.6 | ±16g linear acceleration, ±2000dps angular rate | ±16 gauss | I²C / SPI
Bosch BMX055 | $ 7.02 | 0.13 mA | ±16g linear acceleration, ±2000dps angular rate | ±2500 uT | I²C / SPI

The team chose to use the LSM9DS1 because of its availability with North American electronic components vendors and its use on the Cypress development board for the CYW20719. This IMU is also sold through the electronics hobby site Adafruit, thus C libraries for the device are already widely tested and available.

3.1.2.2. Microprocessor

This section compares several microprocessors considered for the Golf Glove wrist-mounted controller. The Cypress CYW20719 was selected due to its integrated Bluetooth Low Energy capabilities and mature development community. Table 3.4 overviews the devices considered for use in the Golf Glove.

Table 3.4. Microprocessor Feature Comparison

Microprocessor | Cost (USD) | Wireless Connectivity | Power Draw (mA) | Flash Memory (kB) | ADC
Cypress CYW20719 | $ 9.63 | BR/EDR/BLE Bluetooth 5.0 @ 2 Mbps | 10 mA | 1024 | 1 x28-channel, 10-bit, 3.6 ksps
Microchip IS1871 | $ 2.98 | BLE Bluetooth 5.0 | 8 mA | 256 | 1 x6-channel

The Cypress CYW20719 was chosen for the Golf Glove wrist-mounted controller because it contains a Bluetooth Low Energy-capable radio and an adequate number of ADCs on-chip. The Microchip processor is not available in North America during the time of this project and does not have a readily available development environment. Cypress provides WICED, a featured, free integrated development environment (IDE), for use with the microprocessor. The CYW20719 comes with a complete Bluetooth stack/driver on-board and Cypress has released several development and Bluetooth debugging tools specifically for use with this line of products. The team decided that the ease of use of the Cypress development environment best fit the development timeline of this project.

3.1.2.3. Radio

The Golf Glove will utilize the built-in Bluetooth 5.0 radio from the chosen microcontroller. The reasoning behind the team’s choice is grounded in ease of use. By using the build in radio system, the device will no longer need to interface with another, possibly inefficient, radio system. Another reason behind the choice is the size of the system, utilizing a built in radio decreases the overall device size and makes economic sense removing the need to buy and integrate another external radio system.

It was important to the team that the internal radio system utilized a low power system with moderate to high data output. The integrated 5.0 Bluetooth system includes many benefits over other systems. Bluetooth version 5.0 came alone with updates to data throughput and range. Compared to Bluetooth 4.2, version 5.0 doubled the data transfer from 1 Mbps to 2 Mbps, and quadrupled the maximum range from 200 feet to 800 feet, all while maintaining low energy usage.

3.1.2.4. Temperature Sensor

The Golf Glove will utilize a contact sensor embedded in the fabric of the glove. Table 3.5 shows the comparisons made when choosing a temperature sensor.

Table 3.5. Temperature Sensor Choices

Component | Price (USD) | Communication Interface | Sensor Type | Accuracy best/worst (℃) | Resolution (bits) | Max Voltage (V)
Microchip MCP9700-E | 0.28 | Serial | Contact | ±4/6 | 8 | 5.5
Microchip MCP9808 | 1.16 | I2C/SMBus | Contact | .5/1 | 12 | 5.5
Microchip MCP9805 | 0.88 | I2C/SMBus | Contact | ±1/±3 | 10 | 3.6

The temperature sensor will be used to calibrate the other sensors and adjust any values that are slightly temperature dependent. The Microchip MCP9700-E is our selected temperature sensor for the Golf Glove. The resolution and price of the sensor was one of the main deciding factors. It is unnecessary to select a temperature sensor with high resolution because of the application. The sensor must be able to detect the overall temperature of the glove and the MCP9700-E fits this purpose. The sensor can operate on a voltage as low as 2.3 V and an operating current of 0.006 mA. By running at such a low power level, the device can continue operating at a longer time. The team decided to focus on a low price sensor because the accuracy of the temperature readings is not mission-critical. †

† Temperatures around the glove may vary greatly due to friction, user heat, and other environmental variables. Temperature readings are used to provide a small amount of error correction that may be caused by temperature changes in the multiple sensors. Therefore, an expensive temperature sensor with high accuracy is unnecessary for the Golf Glove.

3.1.2.5. Power Requirements

The Golf Glove is a battery powered system that must remain operational for a minimum of 5 hours. The team calculated max power usages of each high power internal/external device to create an estimated minimum capacity required. The main devices the team considered are the I/O pins, the internal Bluetooth transmitter/receiver, and the dual IMUs that will be used to gather swing data. Each one of these devices’ max power draw must be taken into consideration when selecting battery capacity. The maximum power usage calculations over a 5 hour period are found in Table 3.6. By adding up the power usage of each device and adding another ~150 mAh as a buffer, we determined that a 500 mAh battery would be sufficient to consistently supply the Golf Glove with power for a 5 hour period. The most important considerations of battery selection for the Golf Glove are its ability to recharge and be a slim form factor.

Table 3.6. Power Usage Calculations

Device/Subsystem | Max Power (mAh) | Quantity Needed | Hours of Use | Power Usage (mAh)
I/O Pins | 16 | 4 | 5 | 320
Radio RX/TX | 11.5 | 1 | 5 | 57.5
IMU | 4.6 | 2 | 5 | 46
Temp. Sensor | 0.006 | 1 | 5 | .03

Total Power Usage: (I/O pins) + (Radio) + (IMUs) = 320mAh + 57.5mAh + 46mAh + .03mAh = 423.53mAh

Given the above requirements and allowing some margin for error, the battery should have a minimum capacity of 500 mAh. Table 3.7 compares a few options that meet this minimum capacity.

Table 3.7. Battery Choices

Component (Battery) | Price (USD) | Capacity (mAh) | Output Voltage (V) | Form Factor | Chemical Composition | Rechargeable
LP503035 | 1.00 | 500 | 3.7 | Pouch Cell | Li-Ion Polymer | Yes
UxCell AAA | 1.64 | 500 | 1.2 | AAA Cylinder | Ni-MH | Yes
Duracell AAA | 0.55 | 541 | 1.5 | AAA Cylinder | Alkaline | No
Panasonic CR3032 | 2.45 | 500 | 3.0 | Coin Cell | Lithium | No

The LP503035 was selected as the power source for the Golf Glove. The battery incorporates recharging capabilities and contains a capacity sufficient to run the Golf Glove for an extended period of time. This battery is sufficient to drive the internal circuitry with an average output voltage of 3.7 V at a cost-effective price. Another important feature of the LP503035 is its thin form factor allowing for sleek containment inside the main wrist housing.

## 3.2. Software

The microcontroller will collect each swing’s data from the four stretch sensors on the glove, the two IMUs, and the two pressure sensors. Following, the microcontroller packages this data and sends it over Bluetooth to a coaching application that can display it as either raw data or as a readable data graphic. The coaching application will store recorded swings in a local database, thereby allowing the user to review their previous swings at a later time.

    3.2.1. Microcontroller Firmware

Microcontroller firmware drives the sensor logic for the design, handling swing detection as well as sensor data acquisition. The main components of the firmware are described below. The firmware will poll over I2C for the IMUs and an ADC for linear stretch sensors. As for measurements, the two IMUs will each produce three gyrometer measurements and three accelerometer measurement; the two pairs of stretch sensors will measure two wrist angles; and the microcontroller will measure a single temperature reading. These sensor readings will have a resolution of 16 bits for each value.

The firmware will have two main modes of recording with the first mode detecting a swing using a set of threshold sensor values. The data will be recorded at a rate of 120 Hz to produce a high resolution reading of swing movement. A swing is completed once the accelerometer stops reading velocity changes and the hand pressure releases. While recording, data will be stored in the microcontroller flash memory. Once completed, a pointer to the swing memory will be added to a FIFO queue and then sent to the coaching application on the next event loop.

The second mode is real data transmission mode where sensor data is sent to the application as it is measured in real time. This mode will be useful for the user to see sensor data while practicing swing positioning, without the detection interfering with readings. The coaching software will receive a stream of sensor data as it is measured, and will be rate limited by having the microprocessor sleep for the duration required to achieve a target rate of 120hz.

3.2.1.1. Implementation

Microcontroller firmware will be developed in C. The software will consist of a main event loop that will sleep the microcontroller until the conditions for a swing are met. During mode one Swings will be identified by a sudden change in pressure as well as accompanying change in accelerometer velocity reading. Once a swing is detected, the microcontroller begins reading the sensor data into the device memory. While recording, the microcontroller is also checking for the swing end condition. Once the stop condition is met, the swing data will be sent to the coaching software.

In mode two, the swing detection logic will be disabled and data will be communicated to the coaching software immediately while the controller is in the “Detect a Swing” state. The controller software will poll for received Bluetooth data and check for a flag from the controller software. The flag will either disable or enable real-time reading, which will change the state logic for “Detect a Swing”.

3.2.1.2. Software Flow Diagram

The state flow diagram in Figure 3.1 models the three states of our microcontroller.

Figure 3.1. Firmware Stateflow Diagram

3.2.1.3. Interfacing

The controller will interface with the coaching software over Bluetooth. Once the controller receives power, it will begin broadcasting for a Bluetooth connection. Next, the coaching software will initiate a paired Bluetooth connection to the controller so that data transfer can begin. The connection status will be displayed on the coaching software to the user.

    3.2.2. Coaching Software

This section details the software approach for the visualization and coaching software application. The visualization software is responsible for receiving, storing, and processing the sensor measurements from the wrist-mounted microcontroller for display to the user. The application stores the swing data in a local database and queries the database to display the requested swing. Figure 3.2 provides an overview of this backend system.

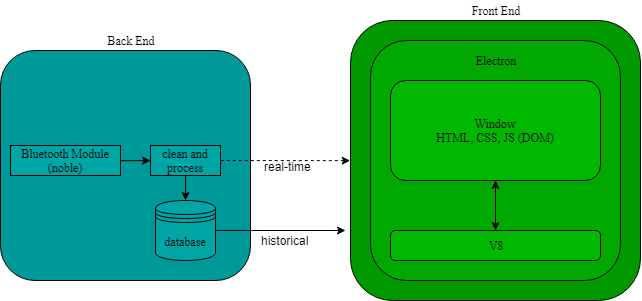
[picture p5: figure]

Figure 3.2. Computer Application Overview

3.2.2.1. Implementation

The coaching software will receive data from the microcontroller over BLE communication. The interfacing will rely on Node.js’s BLE library, noble [1]. Noble will handle all radio transmission overhead such as message length, error checking, and acknowledgements. Data will be received as a stream into a buffer. Once a new timestamp is read from the buffer, the buffer will be saved into a SQLite database as a frame and sent to the display. The display will be powered by Electron, an open-source, cross-platform, desktop application framework [2] that combines the Chromium browser rendering engine and Node.js. Using the React framework [3] inside Electron for front end rendering, the application will respond to both real-time display frames and whole swing display frames. Real-time display frames will be instant measurements containing one data point, while whole swing display frames will be a coagulation of measurements containing a snapshot of the users swing.

#### 3.2.2.2. Software Flow Diagram

Figure 3.3 shows how the desktop application will function.

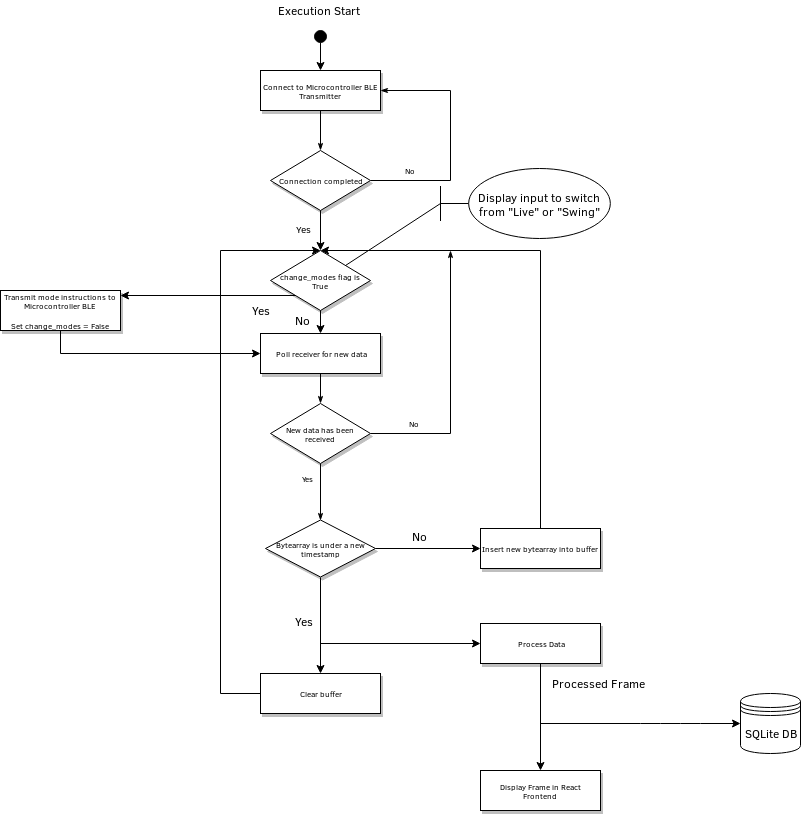
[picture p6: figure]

Figure 3.3. Desktop Application Data Flow

3.2.2.3. Interfacing

Node.js on the desktop will utilize the noble BLE library for interfacing to the microcontroller. It will first pair with the client, then always listen for incoming data. If the display mode is changed from “Live” to “Swing” or vice-versa, the Node.js application will transmit a message to the microcontroller before listening for new messages.

Assuming there are 20 bytes in a Bluetooth payload, the first byte will be the timestamp followed by 19 bytes of sensor data.

### 3.2.3. Use Cases

Figures 3.4 and 3.5 describe the sunny and rainy day use cases for Golf Glove, respectively.

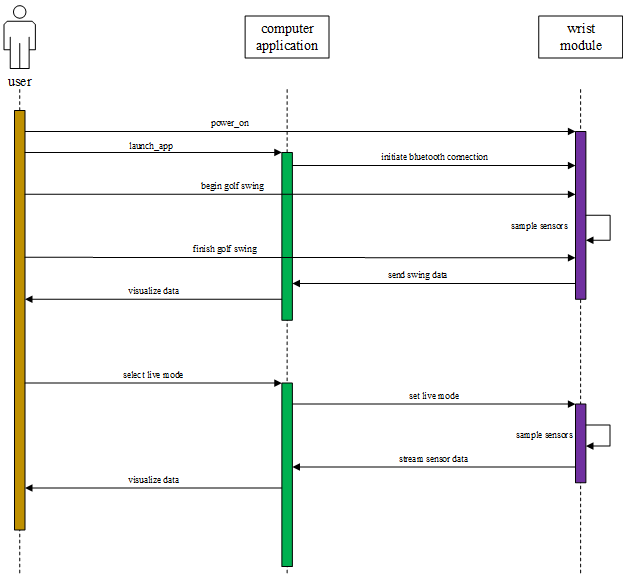
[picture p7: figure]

Figure 3.4. Sunny Day Use Case

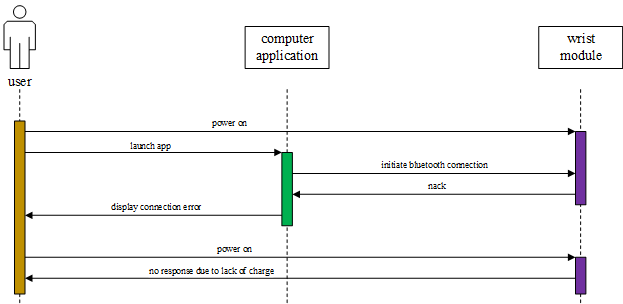
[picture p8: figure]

Figure 3.5. Rainy Day Use Case

## 3.3 References

[1] “noble/noble,” GitHub, 08-Jun-2018. [Online]. Available: https://github.com/noble/noble. [Accessed: 26-Sep-2018].

[2] “Electron,” Electron. [Online]. Available: https://electronjs.org/. [Accessed: 26-Sep-2018].

[3] “React – A JavaScript library for building user interfaces,” React. [Online]. Available: https://reactjs.org/. [Accessed: 26-Sep-2018].

ECE 4532: Design I September 26, 2018

Golf Glove 4

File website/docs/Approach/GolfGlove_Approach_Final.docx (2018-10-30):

# 3. APPROACH

This document details the approach to the technical and practical constraints required for successful implementation. Three distinct subsystems comprise the design: a glove garment, a wrist-mounted microcontroller, and a coaching software application. The glove subsystem will include temperature, stretch, pressure sensors, and inertial measurement units (IMU). This coagulation of inputs will be physically connected to a battery-powered microcontroller that will sample the sensor inputs with high resolution. After data is sampled, it will be broadcast to an application, stored in a persistent database, analyzed, and finally displayed to provide golf swing feedback to the user.

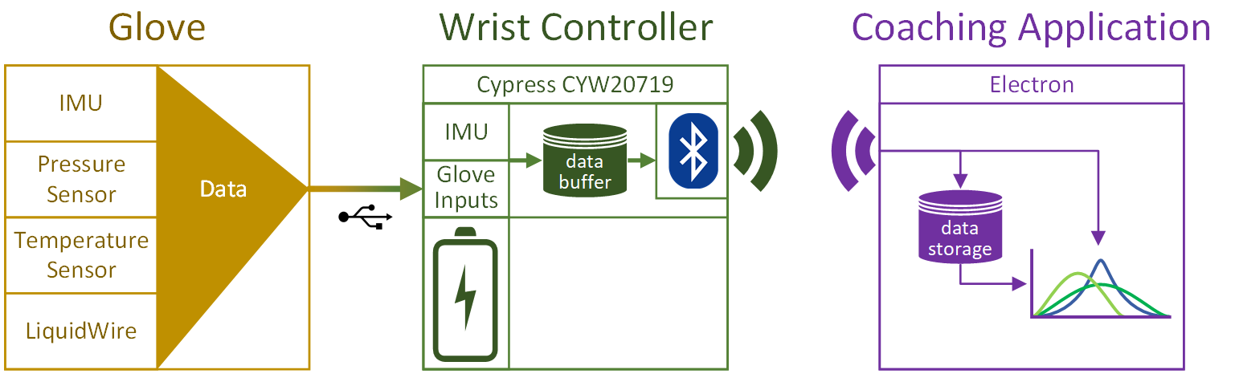
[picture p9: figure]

Figure 3.1. System Overview

## 3.1. Hardware

The Golf Glove is composed of the subsystems outlined in the Design Constraints section of this document. In this section, critical hardware components are compared and optimal candidates are selected.

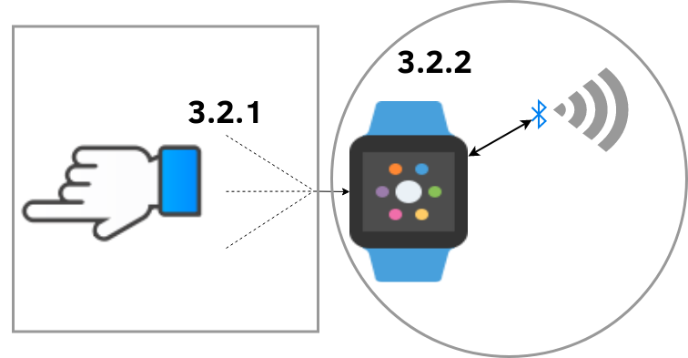
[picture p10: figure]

Figure 3.2. Hardware Subsystems

### 3.1.1. Glove

The glove subsystem consists of the garment itself, linear stretch sensors, flexible pressure sensors, an IMU, and electrical connector components. The garment will provide mounting for the sensors. The sensors will receive power and transfer data to the controller through the electrical connector mounted on the glove.

#### 3.1.1.1. Glove Garment

The glove garment is the mounting point for the linear stretch sensors, an IMU, and pressure sensors. A connector will also be mounted on the glove to connect to the controller, making the glove and controller exchangeable. For the initial prototype, two sizes of gloves will be created to fit different golfer’s hand sizes comfortably. The glove will be constructed out of leather, the standard material for golf gloves.

#### 3.1.1.2. Linear Stretch Sensors

The linear stretch sensors are crucial to the Golf Glove design to measure wrist angles. These sensors vary linearly in either resistance or capacitance as the sensor stretches and typically consists of an elastic material fused with a flexible resistive material or capacitive shape.

Two brands of linear stretch sensors were considered: LiquidWire and StretchSense. LiquidWire was ultimately chosen because of its resistive variability and low cost. Additionally, detecting a change in resistance with a microcontroller requires a simpler circuit than detecting a change in capacitance.

Because LiquidWire sensors are available in custom lengths, the design will use a length of 11.5 cm for development. Upon examining the natural bend of the hand, the maximum required stretch length of a sensor is approximately 2.5 cm. LiquidWire rates their sensors as stretchable up to 125% of their resting length without damaging the sensor; thus, a resting length of 11.5 cm was selected [1]. The resting resistance of each sensor will be approximately 50 Ω; however, due to the manufacturing process of LiquidWire, the resistive value will vary slightly. As a result, a calibration procedure will be required for each sensor. A test of the sensors shows a typical resistive increase of 15 Ω at full stretch.

#### 3.1.1.3. Flexible Pressure Sensors

The Golf Glove must record the force of the user’s hand on the golf club accurately in an unobtrusive manner. Therefore, the design will use two flexible pressure sensors to detect the force in two locations on the palm of the hand. Having two measurement locations allows the device to analyze the user’s distribution of force on the golf club. Per the design constraints, these measurements will be used to discourage improper swing form that increases injuries such as tennis elbow.

A study found that maximum human grip strength reaches a value of around 55 kgf. A reasonable golf club grip will certainly not encroach into this maximum range as it peaks at a high-end value of 10 kgf [2, 3]. Thus, a sensor with a maximum pressure sensing ability of 25 kgf is appropriate. Table 3.1 shows possible pressure sensors that satisfy this 25 kgf requirement.

Table 3.1. Flexible Pressure Sensor Comparison

Name | Diameter (mm) | Price (USD) | Resistance Range (Ω) | Interface/Communication
Interlink 400 Series [4] | <15 | 7.00 | Infinite-250 | Analog
Velostat Conductive Sheet [5] | Custom Sheet | 3.95 | Variable | Analog

The Interlink 400 series of resistive pressure sensors was chosen due to the simplicity of their integration into the garment. These flexible sensors can be reasonably bent without damage and are manufactured with tinned probes that allow for a direct connection to the glove connector. While the Velostat conductive sheet would need to be manually crafted to specification, the Interlink 400 series sensors are manufactured to a specification; meaning, there is no need to cut or measure for each glove and the resistance value can be coded into the device firmware as a constant value. Additionally, while the price of materials per sensor is higher for Interlink sensors, using them drastically improves the manufacturability of the Golf Glove because the sensors to not need to be manually crafted.

#### 3.1.1.4. Electrical Connector

The electrical connection between the glove’s sensors and the wrist-mounted controller should be robust and capable of handling multiple data inputs and outputs. Counting the amount of sensor channels and voltage inputs/outputs, it was determined that a minimum of eight conductors would be needed. These conductors include the outputs of the stretch sensors, pressure sensors, and IMU. Rather than create a new proprietary connector, thereby compromising the manufacturability design constraint, the design will use a standardized connector. In Table 3.2 shows a comparison of potential connector standards.

Table 3.2. Standard Connection Comparison

Standard | Number of Connections | Reversible | Max Power (A)
USB-C | 12 | Yes | 5
USB-Micro | 5 | No | 5
Cat-5 | 8 | No | 0.63

The design will utilize a standard USB-C connection to connect the glove sensors and the wrist-mounted controller. USB-C provides more than enough power throughput to the sensors and an adequate number of pins to transfer data to the wrist-mounted microcontroller. The reversibility is an added bonus; removing the possible confusion and frustration of irreversible connector standards certainly enhances the user’s overall experience.

### 3.1.2. Wrist-Mounted Controller

The wrist-mounted controller contains an IMU, the microcontroller, the radio, and the battery. Other than the IMU, these components are responsible for collecting and transmitting data to the coaching application. This section compares the design options considered for these components.

#### 3.1.2.1. Inertial Measurement Unit

The Golf Glove requires two IMUs—one in the wrist-mounted controller and one on the back of the hand—to accurately measure movement according to design constraint of wrist acceleration, hand orientation, and hand acceleration within a 5% margin of error. These IMUs will measure acceleration of the hand and the rotation of the wrist. A typical golf swing involves linear acceleration of up to 1.5 g and rotational speeds of up to 1000 degrees per second at the wrist [6, 7]. Table 3.3 provides a comparison of the considered IMUs.

Table 3.3. Inertial Measurement Unit Comparison

IMU | Cost (USD) | Power Draw (mA) | Accelerometer (g-force) | Gyroscope (degrees per sec) | Output Resolution/Rate
STM LSM9DS1 [8] | $ 6.14 | 1.9–3.6 | ±2/±4/±8/±16 | ±245/±500/±2000 | 16-bit @ 1 kHz
Bosch BMX055 [9] | $ 7.02 | 2.4–3.6 | ±2/±4/±8/±16 | ±125 to ±2000 | 16-bit @ 1 kHz
mCube MC6470 [10] | $ 3.01 | 0.07–1.0 | ±2/±4/±8/±16 | 500 (Interpolated) | 14-bit @ 0.1 kHz

The design constraints specify a minimum sampling rate for sensor data of 120 Hz; this immediately eliminates the mCube IMU device since it has maximum sampling rate is 100 Hz. The Bosch and STMicro devices have comparable inertial measurement capabilities with selectable 2 g, 4 g, 8 g, or 16 g acceleration scales and similarly selectable ranges of rotational speed scales. The selectable modes define the minimum and maximum range of values expected; a lower acceleration or rotational speed setting allows the device to measure with more precision. The least precise mode supports measurement accuracy to 0.0006 g and 0.004 degrees per second, well within the design constraint of 1.2 m/s. Because both the devices offer nearly identical measurement and output modes, the STM LSM9DS1 was selected due to its lower price and smaller power draw during sleep-mode. Additionally, the LSM9DS1 device is widely used in many hobbyist and professional projects and comes with a well-tested set of open source libraries for interfacing.

#### 3.1.2.2. Microcontroller

The design requires a low-power microcontroller because of its constraints for wireless communication, portability, and sustainability. Table 3.4 compares the microcontrollers considered for the Golf Glove design.

Table 3.4. Microcontroller Comparison

Microcontroller | Cost (USD) | Wireless Connectivity | Power Draw (mA) | Flash Memory (kB) | ADC
Cypress CYW20719 [11] | $ 9.63 | BR/EDR/BLE Bluetooth 5.0 @ 2 Mbps | 10 mA | 1024 | 1 x28-channel, 10-bit, 3.6 ksps
Microchip IS1871 [12] | $ 2.98 | BLE Bluetooth 5.0 | 8 mA | 256 | 1 x6-channel

The Cypress CYW20719 was selected because it contains a BLE-capable radio and an adequate number of built-in ADCs. The Microchip controller is not available in North America during the time of this project and does not have a readily available development environment. Cypress provides WICED: a featured, free, and integrated development environment for use with the microcontroller. The CYW20719 comes with a complete Bluetooth stack on-board and Cypress has released several development and Bluetooth debugging tools specifically for the CYW line of products. Based off these factors, the Cypress chip and development environment best fit the design.

#### 3.1.2.3. Radio

The Golf Glove will use the CYW20719’s built-in Bluetooth 5.0 radio for wireless communication. By using the built-in radio system, the controller will not need to interface with an external communication system. This decision is also driven by the concern for the overall size of the system. By utilizing a built-in radio, the device size and cost are minimized.

The design specifications require an internal radio system with a minimal power draw with moderate to high data throughput. The integrated BLE 5.0 stack offers a host of benefits over other systems such as infrared transmission or WiFi. While infrared systems consume a small amount of power, the connection itself is intermittent. WiFi faces the opposite problem; while transmission distance and reliability are excellent, power draw is comparatively large. The chosen protocols, BLE paired with the Generic Attribute (GATT) application layer, satisfies both the power and data throughput constraints.

#### 3.1.2.4. Power Requirements

The Golf Glove requires a battery powered system that must remain operational for a minimum of five hours according to the design constraints. Calculations below include max power usages of each high power internal/external device to describe an estimated minimum capacity required. The power consuming components the design considered are the I/O pins, the internal Bluetooth module, and the dual IMUs. The battery capacity depends on these devices’ max power draw. The maximum power usage calculations over a five hour period are listed in Table 3.5. By summing the power usage of each device and adding another ~150 mAh as a buffer, it was determined that a 500 mAh battery would be sufficient for the design. Additional considerations for the battery selection are rechargeability and form factor.

Table 3.5. Power Usage Calculations

Device/Subsystem | Max Power (mAh) | Quantity Needed | Hours of Use | Power Usage (mAh)
I/O Pins | 16 | 4 | 5 | 320
Radio RX/TX | 11.5 | 1 | 5 | 57.5
IMU | 4.6 | 2 | 5 | 46

Total Power Usage: (I/O pins) + (Radio) + (IMUs) = 320 mAh + 57.5 mAh + 46 mAh = 423.5 mAh

Note, total power usage does not consider the sleep time. The calculation is a worst-case scenario to determine the minimum battery specifications. Given the above calculation, the battery should contain a minimum capacity of 500 mAh. Table 3.6 compares the battery options for the design.

Table 3.6. Battery Choices

Component (Battery) | Price (USD) | Capacity (mAh) | Output Voltage (V) | Form Factor | Chemical Composition | Rechargeable
LP503035 [13] | 1.00 | 500 | 3.7 | Pouch Cell | Li-Ion Polymer | Yes
UxCell AAA [14] | 1.64 | 500 | 1.2 | AAA Cylinder | Ni-MH | Yes
Duracell AAA [15] | 0.55 | 541 | 1.5 | AAA Cylinder | Alkaline | No
Panasonic CR3032 [16] | 2.45 | 500 | 3.0 | Coin Cell | Lithium | No

The LP503035 was selected as the power source for the Golf Glove. The battery incorporates recharging capabilities and contains a capacity sufficient to run the Golf Glove for 5 hours. This battery is sufficient to drive the internal circuitry with an average output voltage of 3.7 V at a cost-effective price. The LP503035 contains an on-board over voltage protection circuit that will prevent the battery from discharging past 3.0 V, all contained inside of a thin form factor allowing for sleek containment inside the main wrist housing.

## 3.2. Software

The design will require two pieces of software: one for the wrist-mounted controller and one for the coaching application. The wrist-mounted controller will collect data from the glove’s various sensors and will then package and transmit that data via Bluetooth to the coaching application, which will process, store, and display the received data. Because the coaching application will fulfill both backend and frontend roles, the backend and frontend approaches will be discussed in separate sections.

### 3.2.1. Microcontroller Firmware

Microcontroller firmware drives the sensor logic for the design, handling swing detection as well as sensor data acquisition. The main components of the firmware are described below. The firmware will poll over I2C for the IMUs and on-board ADCs for the linear stretch sensors and pressure sensors. As for measurements, the two IMUs will each produce three gyrometer, accelerometer, and magnetometer measurements. The two pairs of stretch sensors will measure two wrist angles and the microcontroller will measure a single temperature reading. One sensor will go slack in each direction while the opposite sensor is reading correct stretch resistance. Sensor readings will have a resolution of 16 bits for each value.

The firmware will have two main modes of recording. The first mode detecting a swing using a set threshold for sensor values. The data will be recorded at a rate of 120 Hz to produce a high-resolution reading of swing movement. A swing is completed once the IMU stops reading acceleration changes and the hand pressure releases. While recording, data will be stored in the microcontroller flash memory. Once completed, a pointer to the swing memory will be added to a FIFO queue and then pushed to the coaching application on the next event loop.

The second mode is real data transmission mode where sensor data is sent to the application as it is measured in real time. This mode will be useful for the user to see sensor data while practicing swing positioning, without the detection interfering with readings. The coaching software will receive a stream of sensor data as it is measured and will be rate limited by having the microcontroller sleep for the duration required to achieve a target rate of 120 Hz.

#### 3.2.1.1. Implementation

Microcontroller firmware will be developed in C. The software will consist of a main event loop that will sleep while not polling the sensors. At a rate determined by testing, the microcontroller will interrupt sleep and read the sensor values to check if swing conditions are met. The rate will be determined by testing for power usage and swing detection accuracy. During mode one, swings will be identified by a sudden change in pressure as well as accompanying change in accelerometer velocity reading. Once a swing is detected, the microcontroller begins reading the sensor data into the device memory. While recording, the microcontroller is also checking for the swing end condition. Once the stop condition is met, the swing data will be sent to the coaching software.

In mode two, the swing detection logic will be disabled and the data will be communicated to the coaching software immediately while the controller is in the “Detect a Swing” state. The controller software will poll for received Bluetooth data and check for a flag from the controller software. The flag will either disable or enable real-time reading, which will change the state logic for the “Detect a Swing” state.

#### 3.2.1.2. Software Flow Diagram

The state flow diagram in Figure 3.3 models the three states of the microcontroller.

Figure 3.3. Firmware Stateflow Diagram

#### 3.2.1.3. Interfacing

The controller will interface with the coaching software over Bluetooth. Once the controller receives power, it will begin broadcasting for a Bluetooth connection. Next the coaching software will initiate a Bluetooth connection to the controller and pair the two so that data transfer can begin. The connection status will be displayed on the coaching software to the end-user.

### 3.2.2. Coaching Software Backend

To facilitate the flow of swing data for analysis, the coaching application will receive the data from the wrist-mounted controller and subsequently process, store, and display it. The application’s logic will be split between a backend, which is responsible for handling the Bluetooth connection as well as data processing and storage (Bluetooth receiver), and a frontend graphical user interface (GUI) that renders the visual components. This section exclusively details the software approach for the backend of the coaching application and Section 3.2.3 explains the frontend approach.

As outlined in the Firmware section, the device will have two operating modes: real-time and full-swing. The coaching application will have a user option to choose the mode of operation and will have different visuals accordingly. Figure 3.4 provides an overview of this subsystem with the chosen technologies.

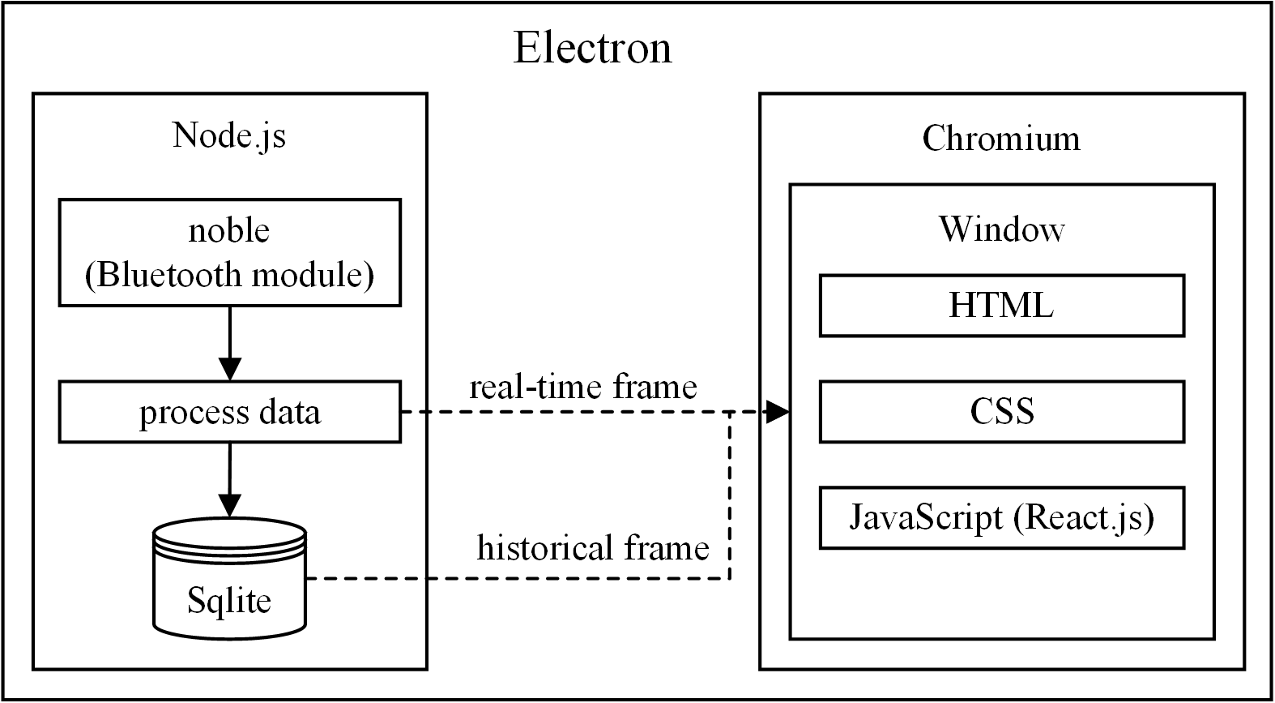
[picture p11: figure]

Figure 3.4. Bluetooth and Display Software Overview

#### 3.2.2.1. Implementation

The coaching software will receive data from the microcontroller via Bluetooth Low Energy (BLE) communication. For quick and efficient Bluetooth receiver development, the application will need to use a programming language with a library that has already implemented the Bluetooth protocol stack across the three major operating systems of Windows, OS X, and Linux. Taking into account the team’s prior experience, three programming languages—C++, Python, and Javascript—were considered, with each having a few different Bluetooth libraries ranging in maturity and support. Although it is the most efficient of the three considerations, C++ was not chosen due to its slow development cycle and a lack of portability to the major operating systems, which would conflict with the design’s manufacturability constraint. Comparatively, Python development is quick and it has frameworks for Windows, OS X, and Linux; however, the frameworks analyzed were neither mature nor supported by a substantial community. Fortunately, Javascript met the search criteria of development speed, had documented Bluetooth platform compatibility, and had a very mature and actively maintained framework.

Node.js, the runtime environment for Javascript, will be used as the basis of the coaching application backend, hosting the backend processes. The Bluetooth interfacing process, which will use the BLE framework noble [17]. Noble will handle all radio transmission overhead such as message length, error checking, and acknowledgements.

For both real-time and full-swing modes, data will be received as a stream into a buffer. A new timestamp in the buffer will delimit a new frame. Once this new frame is identified, it will be processed for storage and display. In full-swing mode, the frame will be deserialized as an array of a single swing’s data points; however, in real-time mode, a frame will be deserialized as a single data point. Deserializing all data members includes parsing the timestamp and the timestamp offset as well as converting the sensor data payload to decimal values. The coaching software will deduce and filter the frames that contain noise by measuring if their payload is outside an expected range. The expected range of values will be tweaked through testing once the prototype is complete.

Following the data frame parsing, the data will be stored in a SQLite database, which will be more than adequate for the application’s storage needs and Javascript has SQLite bindings in its standard library. If the device is operating in real-time mode, the application will also pass the parsed frame’s data directly to the display.

#### 3.2.2.2. Interfacing

Node.js on the desktop will utilize the noble BLE library for interfacing to the microcontroller. It will first pair with the client, then always listen for incoming data. If the device is operating in real-time mode, the backend will receive frames containing single data points; in live-swing operating mode, it will instead receive a frame containing an array of the entire swing’s data points. If the user changes the display mode, the backend application will transmit a message to the microcontroller indicating this change. Once acknowledged, the application will begin listening for new frames. Communication will occur using the GATT application layer protocol, which assigns metadata to each attribute that is used to describe the source of each sensor.

### 3.2.3. Coaching Software Frontend (Display)

According to the constraints, the display must be simple and provide the user with the insight to improve golf swing technique. To accomplish this, each sensor’s signal will be overlaid on a graph over time. The user can toggle these graphs on or off to focus wrist movement, hand orientation, or hand velocity. The user will also have the option to zoom in on specific points in the swing. The display must also show real time and full swing graphing modes. For full-swing mode, the user will be able to choose between their most recent swing, or historical swings that are either show instantly or replayed. The Bluetooth pairing process will be exposed to the user through a settings view. The settings will also allow the user to show and manage memory filled with historical swings. Below in Figure 3.5 is a sketch of display.

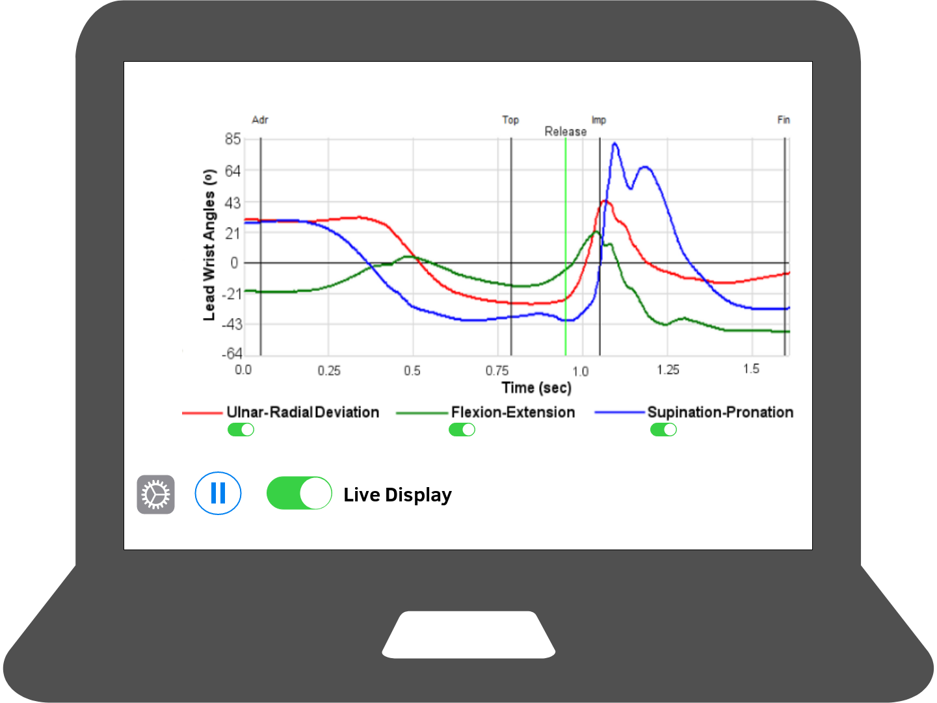
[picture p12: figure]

Figure 3.5. Mockup of Coaching Application Display

#### 3.2.3.1. Implementation

For the GUI, there are three common options: a display in the web browser with AJAX, a display using Electron, or a GUI made in Python using the QT framework. A web browser has the advantage of being portable, as well as powered with Javascript; however, it would require client/server communication overhead and extra development. A GUI in Python would also be portable and powerful, but the QT framework is proprietary and thus does not fulfill the open-source requirement of the manufacturability design constraint. On top of that, it would also require communication overhead between itself and the chosen noble library. The software will use an Electron application as it had all of the perks of the web page but did not require client/server communication overhead and delay.

Electron is an open-source, cross-platform, desktop application framework that combines the Chromium browser rendering engine and Node.js [18]. Using the React framework inside Electron, the application will respond to both real-time display frames and full-swing display frames [19]. Real-time display frames will be instant measurements containing one data point, while full-swing display frames will be a combination of measurements contained in an array that represents a snapshot of the user’s whole swing. To accomplish the design constraint for display, these measurements will be displayed in graphs to the user to show hand pressure, hand acceleration, hand rotation, wrist flexion, and wrist extension over time. Figure 3.6 is a sketch of the display.

#### 3.2.3.2. Interfacing

The display will receive sensor frames from the backend application using inter-process communication and the SQLite database. The display can query the database for historical swing values as well as receive updates from the backend server. Having both persistent storage and event-driven updates allows the user to examine swing data live or at a later time.

### 3.2.4. Software State Diagram

Figure 3.6 shows how the software application will function and conditions relevant to state changes.

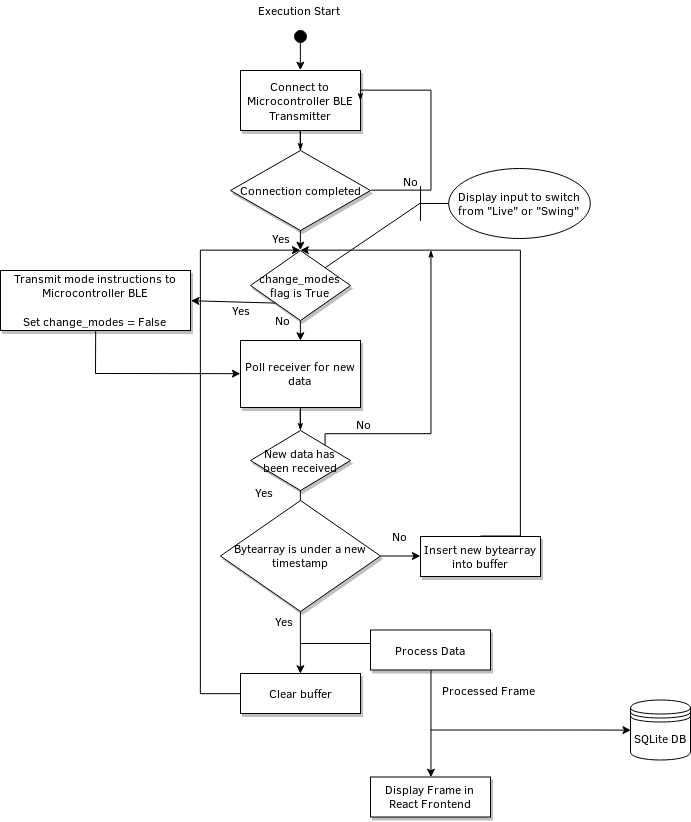
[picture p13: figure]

Figure 3.6. Software State Diagram

### 3.2.5. Use Cases

Figures 3.7 and 3.8 describe the sunny and rainy day use cases for Golf Glove, respectively. Sunny day operation occurs when the wrist-mounted controller and the computer application connect properly.


Figure 3.7. Sunny Day Use Case

Rainy day operation occurs when the wrist-mounted controller does not have adequate charge to power on or the Bluetooth connection between the wrist-mounted controller and coaching application cannot be established.


Figure 3.8 Rainy Day Use Case

## 3.3. References

[1] “Liquid Wire Technology,” Liquid Wire. [Online]. Available: https://liquidwire.io/technology. [Accessed: 26-Oct-2018].

[2] “Hand Grip Strength: age and gender stratified normative data in a population-based study,” BMC Res Notes, Apr. 2011.

[3] E. Komi, J. Roberts, and S. Rothberg, “Measurement and analysis of grip force during a golf shot,” Proceedings of the Institution of Mechanical Engineers Part P Journal of Sports Engineering and Technology, Jun. 2008.

[4] “FS R ® 400 Series Data Sheet,” 2017. [Online]. Available: https://cdn2.hubspot.net/hubfs/3899023/Interlinkelectronics November2017/Docs/Datasheet_FSR.pdf. [Accessed: 25-Oct-2018].

[5] Adafruit Industries, “Pressure-Sensitive Conductive Sheet (Velostat/Linqstat),” adafruit industries blog RSS. [Online]. Available: https://www.adafruit.com/product/1361. [Accessed: 26-Oct-2018].

[6] “Acceleration,” Quintic Sports. [Online]. Available: https://www.quinticsports.com/wp-content/uploads/2016/06/Case-Study-12-Acceleration.pdf. [Accessed: 25-Oct-2018].

[7] Loopy, “Golf Swing Sequence and Timing – The Downswing,” Golf Loopy - Play Your Golf Like a Champion, 14-Oct-2015. [Online]. Available: http://www.golfloopy.com/golf-swing-sequence-and-timing-downswing/. [Accessed: 25-Oct-2018].

[8] “LSM9DS1 Datasheet.” [Online]. Available: https://www.st.com/resource/en/datasheet/lsm9ds1.pdf. [Accessed: 25-Oct-2018].

[9] “Bosch Sensortec BMX055 Datasheet.” [Online]. Available: https://ae-bst.resource.bosch.com/media/_tech/media/datasheets/BST-BMX055-DS000-02.pdf. [Accessed: 25-Oct-2018].

[10] “mCube MC6479 Preliminary Datasheet.” [Online]. Available: https://www.mouser.com/datasheet/2/693/MC6470-Preliminary-Datasheet-APS-048-0033v1.6--1489118.pdf. [Accessed: 25-Oct-2018].

[11] “Enhanced Low Power, BR/EDR/BLE Bluetooth 5.0 SOC Datasheet,” 12-Jul-2018. [Online]. Available: http://www.cypress.com/file/414181/download. [Accessed: 25-Oct-2018].

[12] “Bluetooth® Low Energy (BLE) SoC.” [Online]. Available: http://ww1.microchip.com/downloads/en/DeviceDoc/IS1870_71-Bluetooth-Low-Energy-BLE-SoC-DS60001371E.pdf. [Accessed: 25-Oct-2018].

[13] “Li-Polymer Battery Technology Specification,” Adafruit Industries. [Online]. Available: https://cdn-shop.adafruit.com/product-files/1578/C1854 PKCell Datasheet Li-Polymer 503035 500mAh 3.7V with PCM.pdf. [Accessed: 25-Oct-2018].

[14] “Robot?,” Newegg- Computer Parts, Laptops, Electronics, HDTVs, Digital Cameras and More![Online]. Available: https://www.newegg.com/Product/Product.aspx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 - Batteries & Accessories - Replacement-_-9SIA4SR6YH7231&gclid=Cj0KCQjw08XeBRC0ARIsAP_gaQBDs4SNdrioxPFeVZ5y1T08FjWVodO-wwc_uowzROIrS8EiuxSbWOAaAlTUEALw_wcB&gclsrc=aw.ds. [Accessed: 26-Oct-2018].

[15] “MX2400 Alkaline-Manganese Dioxide Battery Datasheet.” [Online]. Available: http://professional.duracell.com/downloads/datasheets/product/Ultra Power/Ultra-Power_AAA_MX2400.pdf. [Accessed: 25-Oct-2018].

[16] “Manganese Dioxide Lithium Coin Batteries: Individual Specifications.” [Online]. Available: https://www.alliedelec.com/m/d/6ec5c9a8833414eb34f877f612fc890f.pdf. [Accessed: 25-Oct-2018].

[17] “noble/noble,” GitHub, 08-Jun-2018. [Online]. Available: https://github.com/noble/noble. [Accessed: 26-Sep-2018].

[18] “Electron,” Electron. [Online]. Available: https://electronjs.org/. [Accessed: 26-Sep-2018].

[19] “React – A JavaScript library for building user interfaces,” React. [Online]. Available: https://reactjs.org/. [Accessed: 26-Sep-2018].

ECE 4532: Design I October 25, 2018

Golf Glove 1

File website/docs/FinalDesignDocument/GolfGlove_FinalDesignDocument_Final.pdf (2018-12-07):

Golf Glove Design Document | 1

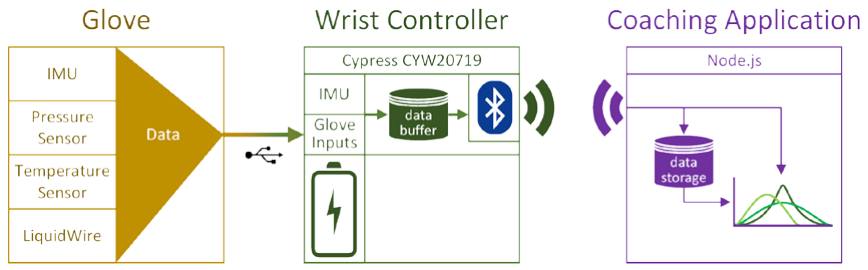
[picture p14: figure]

ECE 4532: Design I | December 5, 2018

design document for

## Golf Glove

submitted to:
Dr. Bryan Jones
ECE 4532: Senior Design I
Department of Electrical and Computer Engineering 413 Hardy Road, Box 9571
Mississippi State University Mississippi State, Mississippi 39762

November 28, 2017
Prepared by:
C. Bush, S. Callicott, W. Carroll, L. Casey, J. Fletcher Faculty Advisor: Professor John Ball Department of Electrical and Computer Engineering Mississippi State University 413 Hardy Road, Box 9571
Mississippi State, Mississippi 39762 email: {cbb330, sc2257, woc17, lec426, jdf469}@msstate.edu

DEPARTMENT OF ELECTRICAL AND COMPUTER ENGINEERING

LIST OF ABBREVIATIONS
ADC - Analog Digital Converter BLE - Bluetooth Low Energy EMR - Electromagnetic Radiation GATT - Generic Attribute
GUI - Graphical User Interface
I2C - Inter-Integrated Circuit
ICNIRP - International Commission on Non-Ionizing Radiation IDE - Integrated Development Environment
IEC - International Electrotechnical Commission
IMU - Inertial Measurement Unit
IP - Ingress Protection
RF - Radio Frequency
RoHS - Reduction of Hazardous Substances RSSI - Received Signal Strength Indication SAR - Specific Absorption Rate

EXECUTIVE SUMMARY
Golf Glove offers golfers a revolutionary way of tracking one’s golf swing. In contrast to other systems, the Golf Glove is low-profile and convenient. When on the course, golfers have no accurate way of recording swing technique on their own. The Golf Glove is a system that consists of multiple inertial, pressure, and flex sensors that can accurately track and record a golfer’s swing in real time. This gathered data is used to provide real time coaching feedback to the golfer. The system, depicted in Figure 1, is comprised of three subsystems: the glove garment, the wrist-mounted controller, and the coaching application.

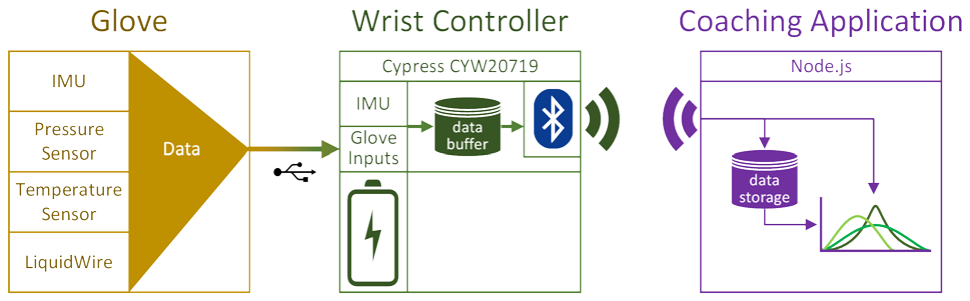
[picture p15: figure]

Figure 1. Golf Glove System Architecture The main constraints of the Golf Glove design include the wireless transmission speed and the resolution of the various measurement sensors. Additionally, the entire system must be able to fit onto a standard golf glove and connect to a wrist-mounted controller that is no wider than a standard sweatband (3”). The Golf Glove will typically be used in outdoor environments; therefore, the system must be able to handle realistic environments with protections against water and dust ingression as well as moderate temperature conditions. Finally, the wrist-mounted controller must be battery powered and communicate wirelessly to the coaching application across 10 meters, the length of an average golf tee box.
The Golf Glove system contains a controller to record sensor data. Its array of sensors includes two accelerometers to track swing movement, two pressure sensors to read grip pressure, and four LiquidWire stretch sensors to measure wrist angle. Finally, a battery will be integrated to continuously power the device for at least 5 hours. The system uses a novel stretch sensor technology developed by LiquidWire to track the flexion and deviation of the wrist. LiquidWire sensors were chosen due to their ability to be sewn into the glove itself while being able to stretch without inhibiting function. The Golf Glove communicates via Bluetooth Low Energy to send packets containing the user’s swing data to the coaching application.
Golf Glove improves on existing systems by shrinking the system size and by adding the capability to track wrist movement via flexible sensors. Future improvements to the system may include 3D rendering of the user’s swing and generating intelligent feedback based on gathered data. Golf Glove provides an affordable and comprehensive solution by combining stretch sensors with the motion and pressure sensing capabilities of products currently on the market.

TABLE OF CONTENTS
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

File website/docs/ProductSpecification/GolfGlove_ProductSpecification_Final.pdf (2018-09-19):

# Golf Glove

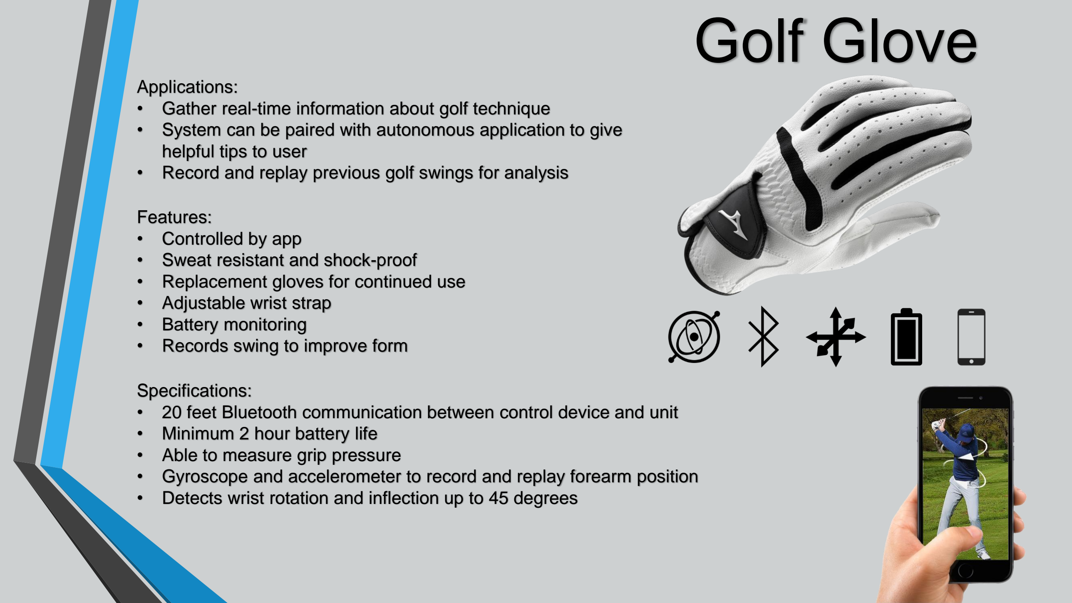
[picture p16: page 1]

Applications:
- Gather real-time information about golf technique
- System can be paired with autonomous application to give helpful tips to user
- Record and replay previous golf swings for analysis

Features:
- Controlled by app
- Sweat resistant and shock-proof
- Replacement gloves for continued use
- Adjustable wrist strap
- Battery monitoring
- Records swing to improve form

Specifications:
- 20 feet Bluetooth communication between control device and unit
- Minimum 2 hour battery life
- Able to measure grip pressure
- Gyroscope and accelerometer to record and replay forearm position
- Detects wrist rotation and inflection up to 45 degrees

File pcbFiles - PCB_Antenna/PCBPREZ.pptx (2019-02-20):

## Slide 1

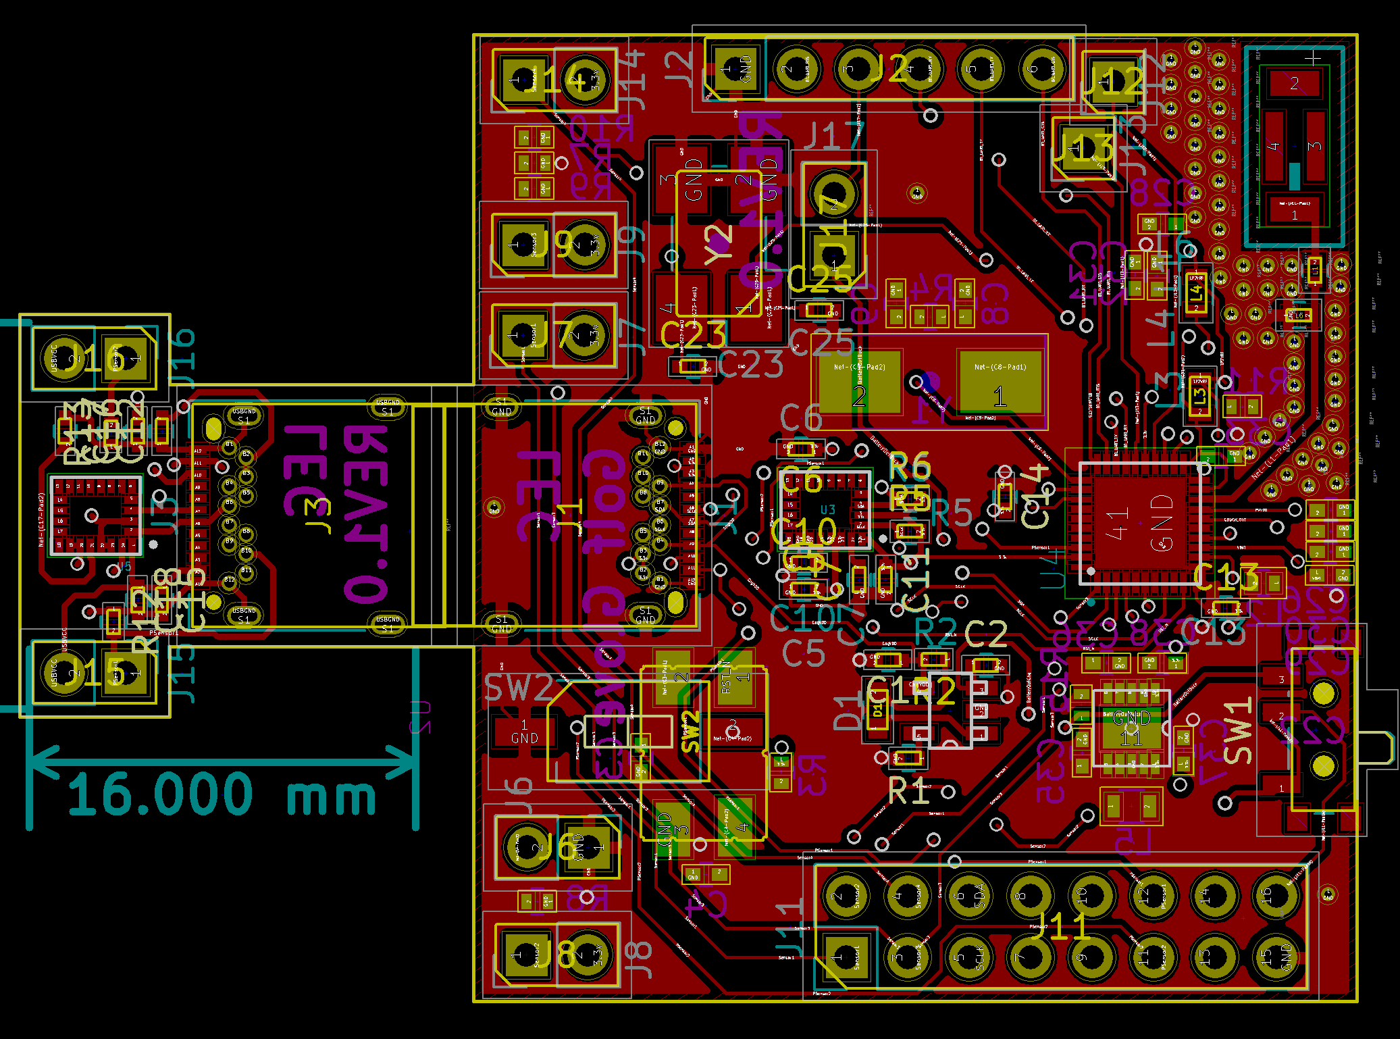
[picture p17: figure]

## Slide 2

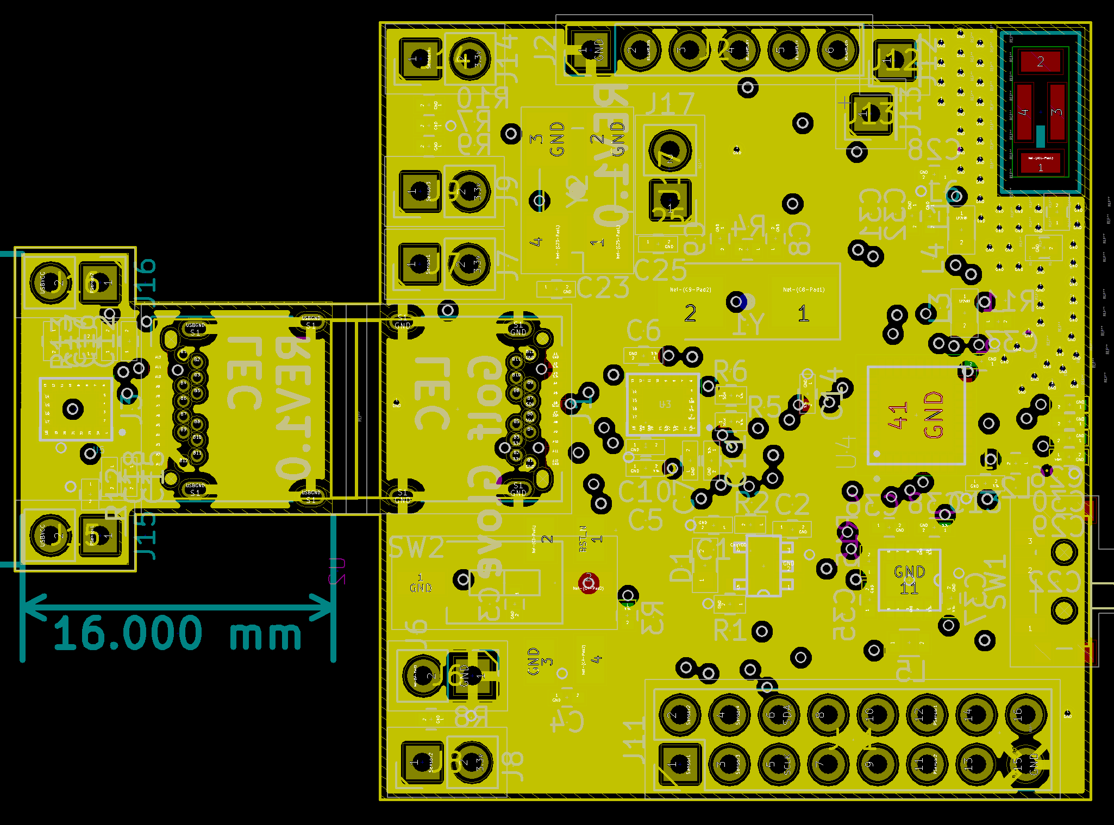
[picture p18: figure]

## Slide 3

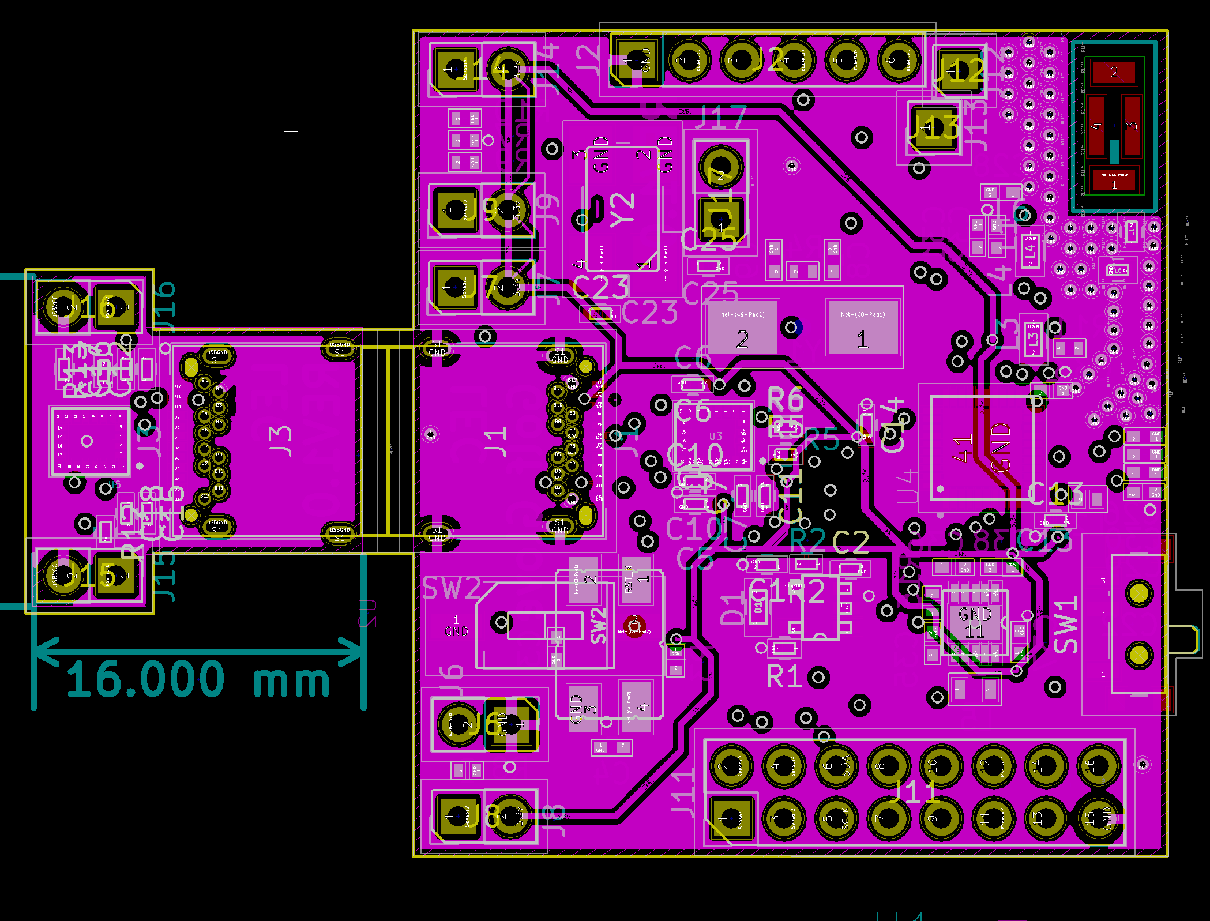
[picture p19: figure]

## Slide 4

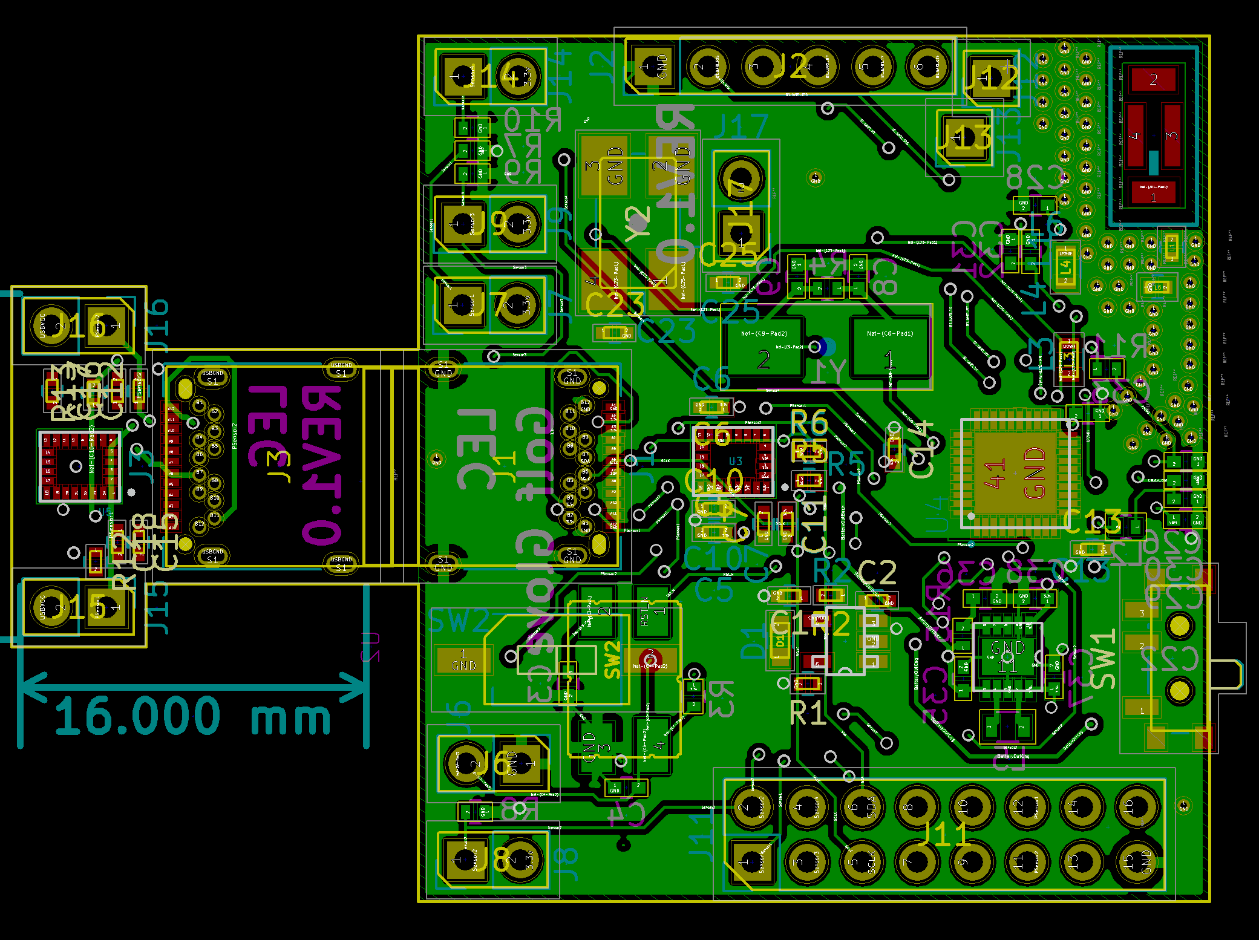
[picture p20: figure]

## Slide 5

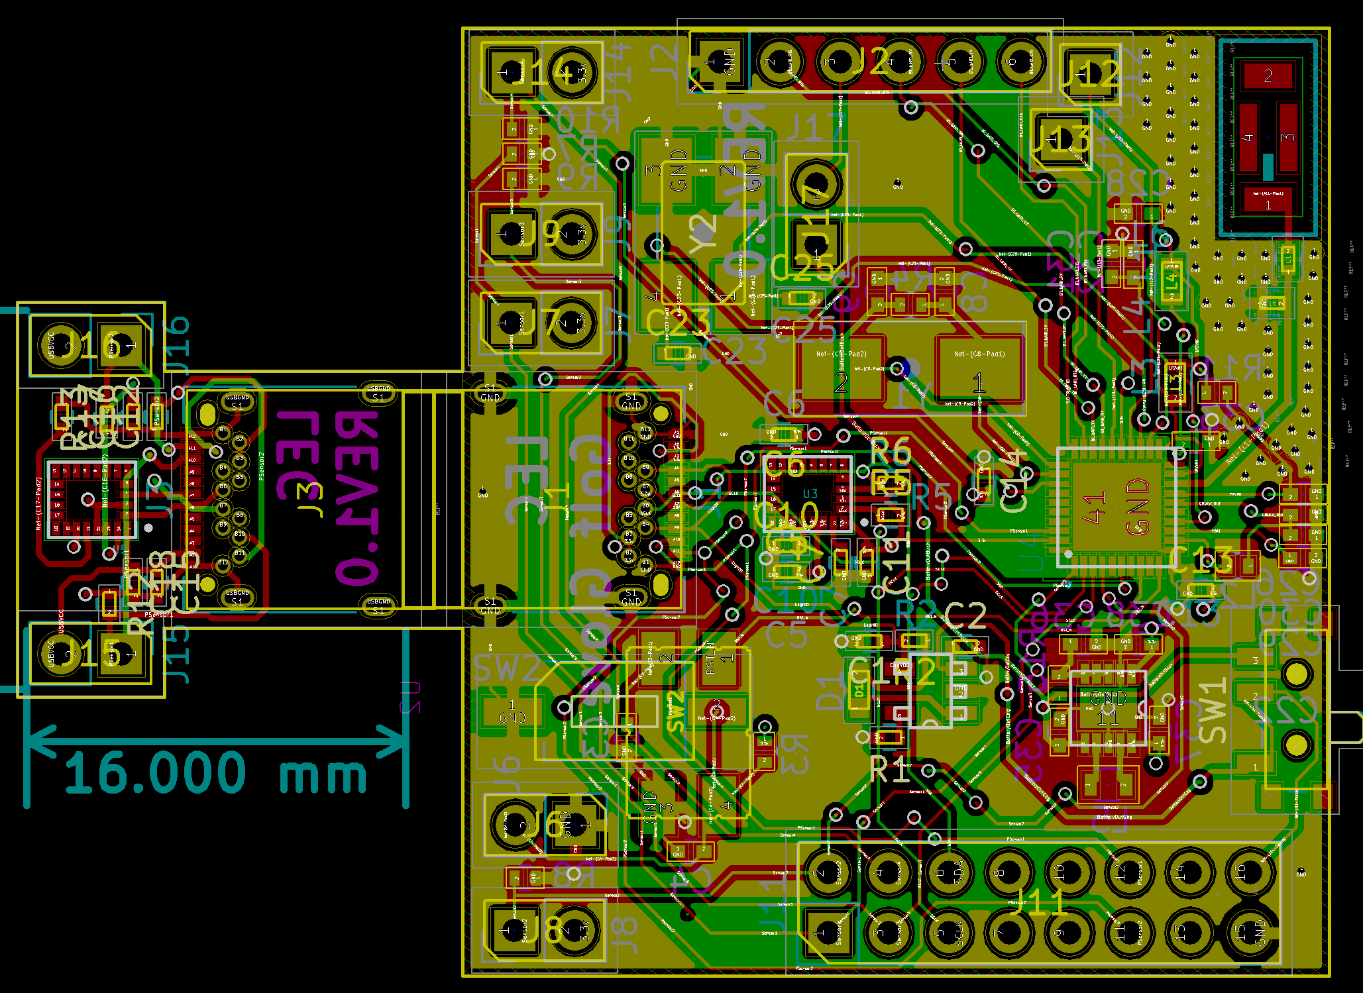
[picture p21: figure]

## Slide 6

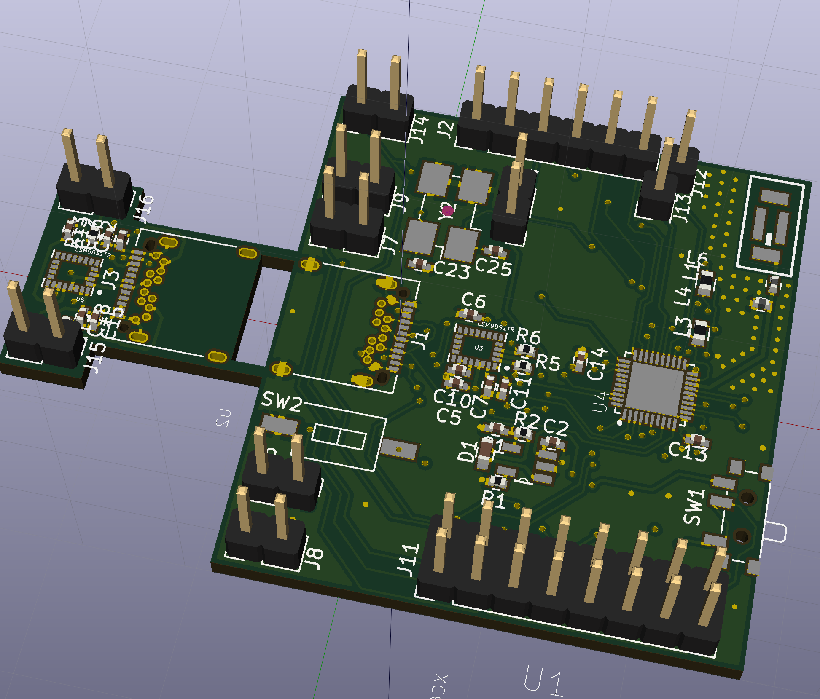
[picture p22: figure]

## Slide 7

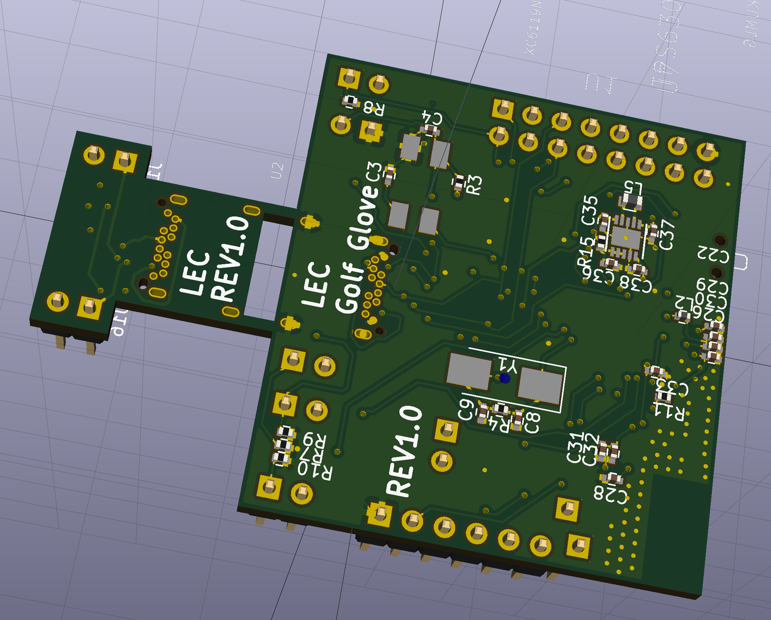
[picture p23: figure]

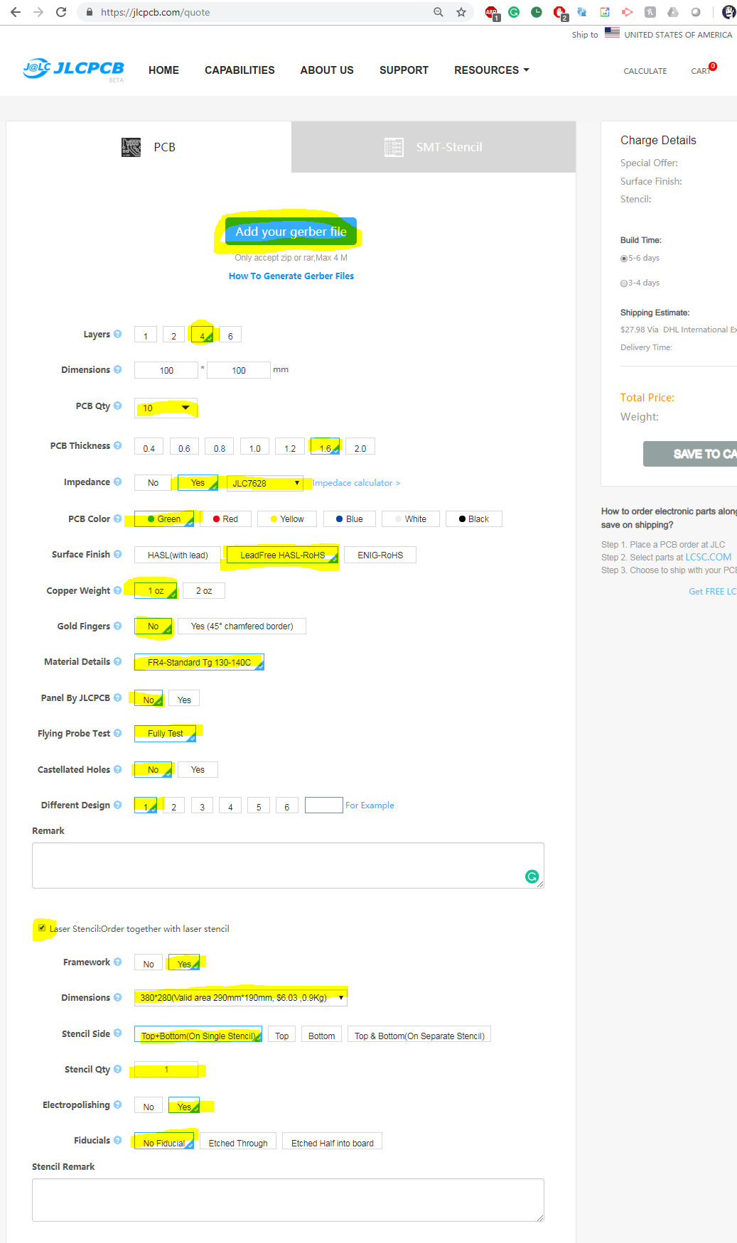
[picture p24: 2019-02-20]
pcbFiles - PCB_Antenna/OrderFolderGolfGlove/JLCPCB_GOLF_GLOVE_SPECS.PNG

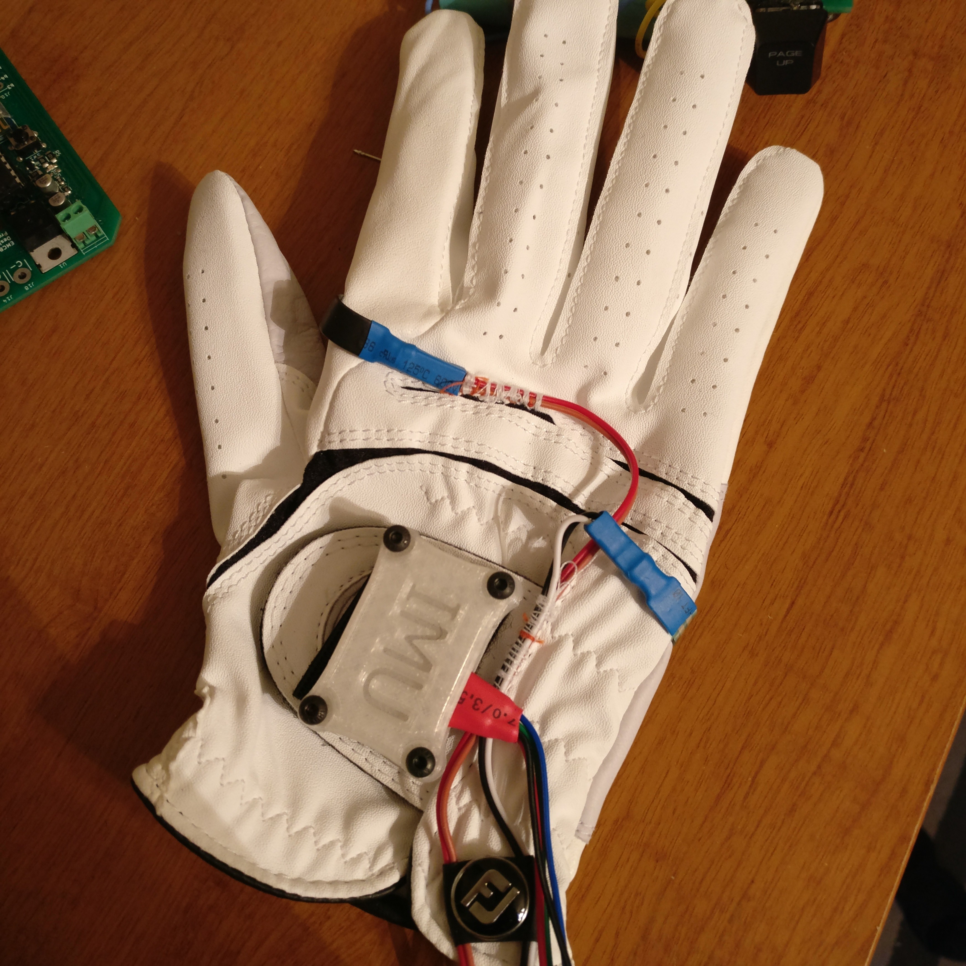
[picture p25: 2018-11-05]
website/images/glove_prototype1.jpg

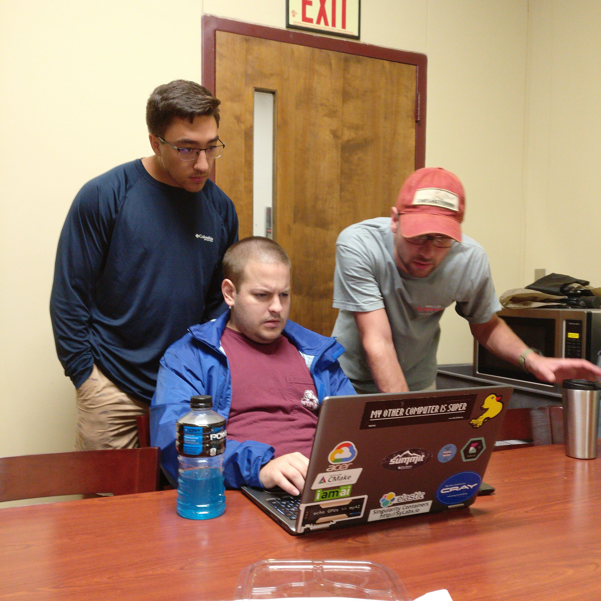
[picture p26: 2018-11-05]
website/images/collaboration1.jpg

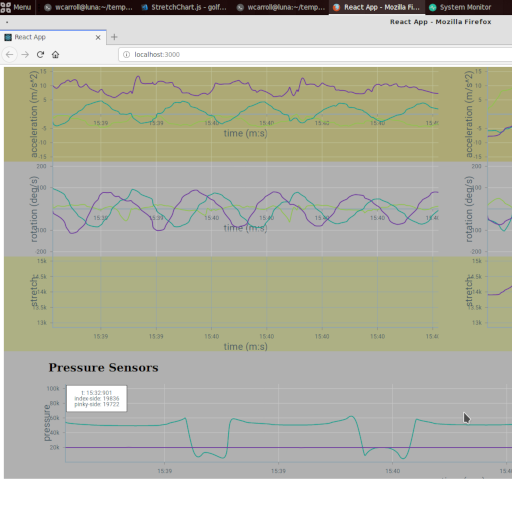
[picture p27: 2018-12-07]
website/images/screenshot_charts1_reduced.png

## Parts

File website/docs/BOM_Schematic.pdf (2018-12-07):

Golf Glove BOM

Circuit Schematic

Name | Part Number | Value | Quantity | Price
Microcontroller | CYW920719Q40EVB1 | N/A | 1 | $45.94
A to D converter | ADS1115 | 12-bit | 4 | $38.60
1s Lipo Battery | 503035 | 500mAh | 1 | $7.99
1s LiPo Charger | TP4056 | 1A Charge Rate | 1 | $1.00
2 Pos Switch | CKN5001-ND | ON-ON | 1 | $3.63
Stretch Sensors | | Resistance | 4 | TBD
Pressure Sensors | FSR 0.5 inch | Resistance | 2 | $14.00
IMU | LSM9DS1 | 9 Axis | 2 | $12.66
Stretch Resistor | CF14JT220R | 220 ohm | 4 | $0.40
Pressure Resistor | CF14JT4K70 | 4.7k ohm | 2 | $0.20
Total:
$124.42

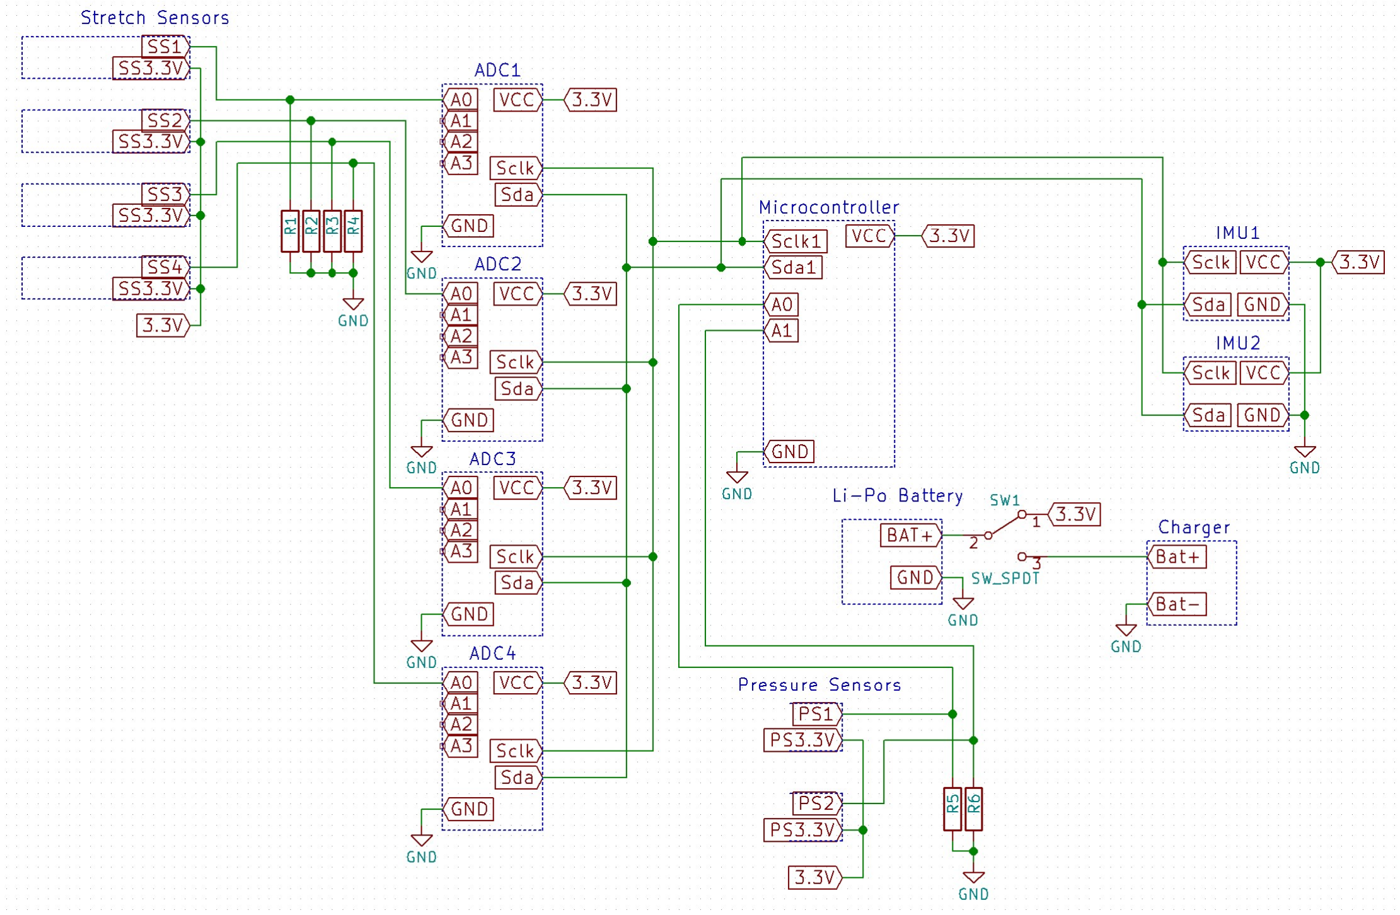
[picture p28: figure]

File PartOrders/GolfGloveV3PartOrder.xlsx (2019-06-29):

GolfGloveUnitV3 Part Order
Links | Quantity | Description
https://www.digikey.com/short/p4095b | 1 | Components
https://www.amazon.com/gp/product/B07BTRKM19/ref=ox_sc_act_title_1?smid=A132D7PL1YID8X&psc=1 | 2 | Battery
https://www.amazon.com/gp/product/B07BTT5VN3/ref=ox_sc_act_title_2?smid=A132D7PL1YID8X&psc=1 | 2 | Battery
https://www.amazon.com/gp/product/B07BTSHFHX/ref=ox_sc_act_title_3?smid=A132D7PL1YID8X&psc=1 | 2 | Battery
https://www.amazon.com/gp/product/B07BTRTR9G/ref=ox_sc_act_title_4?smid=A132D7PL1YID8X&psc=1 | 2 | Battery
https://www.amazon.com/50PCS-Electronic-Component-Laboratory-Storage/dp/B01N2L099B?s=gateway | 1 | Organization Box For Parts
https://www.amazon.com/uxcell-Jumper-1-27mm-Ribbon-Breadboard/dp/B07FMGXFZY?s=gateway | 1 | Ribbon Cable

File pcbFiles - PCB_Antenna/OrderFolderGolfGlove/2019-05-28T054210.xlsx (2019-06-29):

Index | Quantity | Part Number | Manufacturer Part Number | Description | Customer Reference | Available | Backorder | Unit Price | Extended Price USD
1 | 5 | SER4103CT-ND | FC-135 32.7680KA-A5 | CRYSTAL 32.7680 KHZ 12.5PF SMD |  | 5 | 0 | 0.41 | 2.05
2 | 5 | 490-5575-1-ND | XRCGB24M000F0L00R0 | CRYSTAL 24.0000MHZ 6PF SMD |  | 5 | 0 | 0.35 | 1.75
3 | 10 | 587-4150-1-ND | MBKK1608T2R2M | FIXED IND 2.2UH 750MA 345 MOHM |  | 10 | 0 | 0.204 | 2.04
4 | 100 | A129648CT-ND | CRGCQ0402F56K | CRGCQ 0402 56K 1% |  | 100 | 0 | 0.009 | 0.90
5 | 10 | 399-8964-1-ND | C0402C333J4RACTU | CAP CER 0.033UF 16V X7R 0402 |  | 10 | 0 | 0.386 | 3.86
6 | 500 | 1276-1004-1-ND | CL05F104ZO5NNNC | CAP CER 0.1UF 16V Y5V 0402 |  | 500 | 0 | 0.00606 | 3.03
7 | 100 | 490-10693-1-ND | GRM155R60G106ME44D | CAP CER 10UF 4V X5R 0402 |  | 100 | 0 | 0.073 | 7.30
8 | 500 | 490-5921-1-ND | GRM1555C1H100JA01D | CAP CER 10PF 50V C0G/NP0 0402 |  | 500 | 0 | 0.01128 | 5.64
9 | 100 | 1276-1178-1-ND | CL05C120JB5NNNC | CAP CER 12PF 50V C0G/NP0 0402 |  | 100 | 0 | 0.0141 | 1.41
10 | 100 | 1276-1235-1-ND | CL05A105MQ5NNNC | CAP CER 1UF 6.3V X5R 0402 |  | 100 | 0 | 0.0127 | 1.27
11 | 20 | 490-12532-1-ND | GRM155R60J225KE95D | CAP CER 2.2UF 6.3V X5R 0402 |  | 20 | 0 | 0.086 | 1.72
12 | 100 | 311-3723-1-ND | CC0402DRNPO9BN6R0 | CAP CER 6PF 50V NPO 0402 |  | 100 | 0 | 0.0133 | 1.33
13 | 10 | 754-1804-1-ND | APTD1608VBC/D | LED BLUE CLEAR CHIP SMD |  | 10 | 0 | 0.502 | 5.02
14 | 10 | 445-6381-1-ND | MLZ1005M2R2WT000 | FIXED IND 2.2UH 350MA 550 MOHM |  | 10 | 0 | 0.258 | 2.58
15 | 20 | 732-1593-1-ND | 742792651 | FERRITE BEAD 600 OHM 0603 1LN |  | 20 | 0 | 0.17 | 3.40
16 | 250 | RMCF0402ZT0R00CT-ND | RMCF0402ZT0R00 | RES 0 OHM JUMPER 1/16W 0402 |  | 250 | 0 | 0.0038 | 0.95
17 | 10 | P100DECT-ND | ERA-2AED101X | RES SMD 100 OHM 0.5% 1/16W 0402 |  | 10 | 0 | 0.188 | 1.88
18 | 10 | P470DCCT-ND | ERA-2AEB471X | RES SMD 470 OHM 0.1% 1/16W 0402 |  | 10 | 0 | 0.321 | 3.21
19 | 100 | RR05P10.0KDCT-ND | RR0510P-103-D | RES SMD 10K OHM 0.5% 1/16W 0402 |  | 100 | 0 | 0.0285 | 2.85
20 | 100 | A130072CT-ND | CRGCQ0402J10M | CRGCQ 0402 10M 5% |  | 100 | 0 | 0.0068 | 0.68
21 | 20 | 541-4463-1-ND | TNPW040213K5BEED | RES 13.5K OHM 0.1% 1/10W 0402 |  | 20 | 0 | 0.462 | 9.24
22 | 20 | YAG2303CT-ND | RT0402BRD072KL | RES SMD 2K OHM 0.1% 1/16W 0402 |  | 20 | 0 | 0.29 | 5.80
23 | 20 | P5.6KDCCT-ND | ERA-2AEB562X | RES SMD 5.6K OHM 0.1% 1/16W 0402 |  | 20 | 0 | 0.321 | 6.42
24 | 5 | 401-2016-1-ND | PCM12SMTR | SWITCH SLIDE SPDT 300MA 6V |  | 5 | 0 | 0.91 | 4.55
25 | 10 | 497-14946-1-ND | LSM9DS1TR | IMU ACCEL/GYRO/MAG I2C/SPI 24LGA |  | 10 | 0 | 5.716 | 57.16
26 | 5 | 428-4498-ND | CYW20719B1KUMLG | IC RF TXRX+MCU BLUETOOTH 40UFQFN |  | 5 | 0 | 9.24 | 46.20
27 | 10 | 296-32517-1-ND | TPS63001DRCT | IC REG BCK BST 3.3V 1.6A 10VSON |  | 10 | 0 | 2.35 | 23.50
28 | 10 | MCP73831T-2ACI/OTCT-ND | MCP73831T-2ACI/OT | IC CONTROLLR LI-ION 4.2V SOT23-5 |  | 10 | 0 | 0.58 | 5.80
 |  | https://www.digikey.com/short/p4095b

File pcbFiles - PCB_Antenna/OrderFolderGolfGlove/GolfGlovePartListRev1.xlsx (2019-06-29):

PartName | Value | Form Factor | Part Number | Brand | Price | Type | Link
C3 | .033uF | 402 |  |  |  | CAP | https://www.digikey.com/product-detail/en/kemet/C0402C333J4RACTU/399-8964-1-ND/3522481
C13 | .1uF | 402 |  |  |  | CAP | https://www.digikey.com/product-detail/en/samsung-electro-mechanics/CL05F104ZO5NNNC/1276-1004-1-ND/3889090
C14 | .1uF | 402 |  |  |  | CAP | https://www.digikey.com/product-detail/en/samsung-electro-mechanics/CL05F104ZO5NNNC/1276-1004-1-ND/3889090
C31 | .1uF | 402 |  |  |  | CAP | https://www.digikey.com/product-detail/en/samsung-electro-mechanics/CL05F104ZO5NNNC/1276-1004-1-ND/3889090
C32 | .1uF | 402 |  |  |  | CAP | https://www.digikey.com/product-detail/en/samsung-electro-mechanics/CL05F104ZO5NNNC/1276-1004-1-ND/3889090
C4 | .1uF | 402 |  |  |  | CAP | https://www.digikey.com/product-detail/en/samsung-electro-mechanics/CL05F104ZO5NNNC/1276-1004-1-ND/3889090
C36 | .1uF | 402 |  |  |  | CAP | https://www.digikey.com/product-detail/en/samsung-electro-mechanics/CL05F104ZO5NNNC/1276-1004-1-ND/3889090
C12 | 100nF | 402 |  |  |  | CAP | https://www.digikey.com/product-detail/en/samsung-electro-mechanics/CL05F104ZO5NNNC/1276-1004-1-ND/3889090
C15 | 100nF | 402 |  |  |  | CAP | https://www.digikey.com/product-detail/en/samsung-electro-mechanics/CL05F104ZO5NNNC/1276-1004-1-ND/3889090
C16 | 100nF | 402 |  |  |  | CAP | https://www.digikey.com/product-detail/en/samsung-electro-mechanics/CL05F104ZO5NNNC/1276-1004-1-ND/3889090
C5 | 100nF | 402 |  |  |  | CAP | https://www.digikey.com/product-detail/en/samsung-electro-mechanics/CL05F104ZO5NNNC/1276-1004-1-ND/3889090
C6 | 100nF | 402 |  |  |  | CAP | https://www.digikey.com/product-detail/en/samsung-electro-mechanics/CL05F104ZO5NNNC/1276-1004-1-ND/3889090
C7 | 100nF | 402 |  |  |  | CAP | https://www.digikey.com/product-detail/en/samsung-electro-mechanics/CL05F104ZO5NNNC/1276-1004-1-ND/3889090
C10 | 10nF (16V) | 402 |  |  |  | CAP | https://www.digikey.com/product-detail/en/murata-electronics-north-america/GRM155R60G106ME44D/490-10693-1-ND/5251412
C17 | 10nF (16V) | 402 |  |  |  | CAP | https://www.digikey.com/product-detail/en/murata-electronics-north-america/GRM155R60G106ME44D/490-10693-1-ND/5251412
C33 | 10pF | 402 |  |  |  | CAP | https://www.digikey.com/product-detail/en/murata-electronics-north-america/GRM1555C1H100JA01D/490-5921-1-ND/3721278
C1 | 10uF | 402 |  |  |  | CAP | https://www.digikey.com/product-detail/en/murata-electronics-north-america/GRM155R60G106ME44D/490-10693-1-ND/5251412
C11 | 10uF | 402 |  |  |  | CAP | https://www.digikey.com/product-detail/en/murata-electronics-north-america/GRM155R60G106ME44D/490-10693-1-ND/5251412
C18 | 10uF | 402 |  |  |  | CAP | https://www.digikey.com/product-detail/en/murata-electronics-north-america/GRM155R60G106ME44D/490-10693-1-ND/5251412
C2 | 10uF | 402 |  |  |  | CAP | https://www.digikey.com/product-detail/en/murata-electronics-north-america/GRM155R60G106ME44D/490-10693-1-ND/5251412
C22 | 10uF | 402 |  |  |  | CAP | https://www.digikey.com/product-detail/en/murata-electronics-north-america/GRM155R60G106ME44D/490-10693-1-ND/5251412
C35 | 10uF | 402 |  |  |  | CAP | https://www.digikey.com/product-detail/en/murata-electronics-north-america/GRM155R60G106ME44D/490-10693-1-ND/5251412
C37 | 10uF | 402 |  |  |  | CAP | https://www.digikey.com/product-detail/en/murata-electronics-north-america/GRM155R60G106ME44D/490-10693-1-ND/5251412
C38 | 10uF | 402 |  |  |  | CAP | https://www.digikey.com/product-detail/en/murata-electronics-north-america/GRM155R60G106ME44D/490-10693-1-ND/5251412
C23 | 12pF | 402 |  |  |  | CAP | https://www.digikey.com/product-detail/en/samsung-electro-mechanics/CL05C120JB5NNNC/1276-1178-1-ND/3889264
C25 | 12pF | 402 |  |  |  | CAP | https://www.digikey.com/product-detail/en/samsung-electro-mechanics/CL05C120JB5NNNC/1276-1178-1-ND/3889264
C26 | 1uF | 402 |  |  |  | CAP | https://www.digikey.com/product-detail/en/samsung-electro-mechanics/CL05A105MQ5NNNC/1276-1235-1-ND/3889321
C29 | 1uF | 402 |  |  |  | CAP | https://www.digikey.com/product-detail/en/samsung-electro-mechanics/CL05A105MQ5NNNC/1276-1235-1-ND/3889321
C30 | 1uF | 402 |  |  |  | CAP | https://www.digikey.com/product-detail/en/samsung-electro-mechanics/CL05A105MQ5NNNC/1276-1235-1-ND/3889321
C28 | 2.2uF | 402 |  |  |  | CAP | https://www.digikey.com/product-detail/en/murata-electronics-north-america/GRM155R60J225KE95D/490-12532-1-ND/5797522
C8 | 6pF | 402 |  |  |  | CAP | https://www.digikey.com/product-detail/en/yageo/CC0402DRNPO9BN6R0/311-3723-1-ND/8024812
C9 | 6pF | 402 |  |  |  | CAP | https://www.digikey.com/product-detail/en/yageo/CC0402DRNPO9BN6R0/311-3723-1-ND/8024812
D1 | blue LED | 603 |  | Kingbright |  | LED | https://www.digikey.com/product-detail/en/kingbright/APTD1608VBC-D/754-1804-1-ND/4753651
J1 | USB-C | USB-C |  |  |  | CONNECTOR | https://www.ttiinc.com/content/ttiinc/en/apps/part-detail.html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
J11 | N/A |  |  |  |  | HEADER | N/A
J12 | N/A |  |  |  |  | HEADER | N/A
J13 | N/A |  |  |  |  | HEADER | N/A
J14 | N/A |  |  |  |  | HEADER | N/A
J15 | N/A |  |  |  |  | HEADER | N/A
J16 | N/A |  |  |  |  | HEADER | N/A
J17 | N/A |  |  |  |  | HEADER | N/A
J2 | N/A |  |  |  |  | HEADER | N/A
J3 | USB-C | USB-C |  |  |  | CONNECTOR | https://www.ttiinc.com/content/ttiinc/en/apps/part-detail.html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
J6 | N/A |  |  |  |  | HEADER | N/A
J7 | N/A |  |  |  |  | HEADER | N/A
J8 | N/A |  |  |  |  | HEADER | N/A
J9 | N/A |  |  |  |  | HEADER | N/A
L1 |  | 402 |  |  |  | INDUCTOR
L2 | 2.2uH | 402 |  |  |  | INDUCTOR | https://www.digikey.com/product-detail/en/tdk-corporation/MLZ1005M2R2WT000/445-6381-1-ND/2465708
L3 | 600@100MHz | 603 |  |  |  | FERRITE BEAD | https://www.digikey.com/product-detail/en/wurth-electronics-inc/742792651/732-1593-1-ND/1639537
L4 | 600@100MHz | 603 |  |  |  | FERRITE BEAD | https://www.digikey.com/product-detail/en/wurth-electronics-inc/742792651/732-1593-1-ND/1639537
L5 | 2.2uH | 603 |  |  |  | INDUCTOR | https://www.digikey.com/product-detail/en/tdk-corporation/MLZ1005M2R2WT000/445-6381-1-ND/2465708
L6 |  | 402 |  |  |  | INDUCTOR
R11 | 0 | 402 |  |  |  | RESISTOR | https://www.digikey.com/product-detail/en/stackpole-electronics-inc/RMCF0402ZT0R00/RMCF0402ZT0R00CT-ND/1942941
R15 | 100 | 402 |  |  |  | RESISTOR | https://www.digikey.com/product-detail/en/panasonic-electronic-components/ERA-2AED101X/P100DECT-ND/1706256
R2 | 470 | 402 |  |  |  | RESISTOR | https://www.digikey.com/product-detail/en/panasonic-electronic-components/ERA-2AEB471X/P470DCCT-ND/1706175
R5 | 10K | 402 |  |  |  | RESISTOR | https://www.digikey.com/product-detail/en/susumu/RR0510P-103-D/RR05P10.0KDCT-ND/432960
R6 | 10K | 402 |  |  |  | RESISTOR | https://www.digikey.com/product-detail/en/susumu/RR0510P-103-D/RR05P10.0KDCT-ND/432960
R4 | 10M | 402 |  |  |  | RESISTOR | https://www.digikey.com/product-detail/en/te-connectivity-passive-product/CRGCQ0402J10M/A130072CT-ND/8577904
R10 | 13.5K | 402 |  |  |  | RESISTOR | https://www.digikey.com/product-detail/en/vishay-dale/TNPW040213K5BEED/541-4463-1-ND/9448467
R12 | 13.5K | 402 |  |  |  | RESISTOR | https://www.digikey.com/product-detail/en/vishay-dale/TNPW040213K5BEED/541-4463-1-ND/9448467
R13 | 13.5K | 402 |  |  |  | RESISTOR | https://www.digikey.com/product-detail/en/vishay-dale/TNPW040213K5BEED/541-4463-1-ND/9448467
R7 | 13.5K | 402 |  |  |  | RESISTOR | https://www.digikey.com/product-detail/en/vishay-dale/TNPW040213K5BEED/541-4463-1-ND/9448467
R8 | 13.5K | 402 |  |  |  | RESISTOR | https://www.digikey.com/product-detail/en/vishay-dale/TNPW040213K5BEED/541-4463-1-ND/9448467
R9 | 13.5K | 402 |  |  |  | RESISTOR | https://www.digikey.com/product-detail/en/vishay-dale/TNPW040213K5BEED/541-4463-1-ND/9448467
R1 | 2k | 402 |  |  |  | RESISTOR | https://www.digikey.com/product-detail/en/yageo/RT0402BRD072KL/YAG2303CT-ND/5252417
R3 | 5.6k | 402 |  |  |  | RESISTOR | https://www.digikey.com/product-detail/en/panasonic-electronic-components/ERA-2AEB562X/P5.6KDCCT-ND/1706201
SW1 | SPDT PCM12 | N/A |  |  |  | SWITCH | https://www.digikey.com/product-detail/en/c-k/PCM12SMTR/401-2016-1-ND/1640125
SW2 | SW_DIP_x1_W8.61mm_Slide_LowProfile | N/A |  |  |  | SWITCH | https://www.digikey.com/product-detail/en/nidec-copal-electronics/CHS-01TB/563-1004-1-ND/948403
U1 | N/A | N/A | MCP73831T | Microchip |  | CHARGER | https://www.digikey.com/product-detail/en/microchip-technology/MCP73831T-2ACI-OT/MCP73831T-2ACI-OTCT-ND/1979802
U2 | N/A | N/A | XC6119N16A7R-G | Torex |  |  | https://www.digikey.com/product-detail/en/torex-semiconductor-ltd/XC6119N16A7R-G/XC6119N16A7R-G-ND/4369463
U3 | N/A | N/A | LSM9DS1TR | STMicroelectronics |  | ACCELEROMETER | https://www.digikey.com/product-detail/en/stmicroelectronics/LSM9DS1TR/497-14946-1-ND/4988079
U4 | N/A | N/A | CYW20719B1KUMLG | Cypress |  | MICROCONTROLLER | https://www.digikey.com/products/en?keywords=CYW20719B1KUMLG
U5 | N/A | N/A | LSM9DS1TR | STMicroelectronics |  | ACCELEROMETER | https://www.digikey.com/product-detail/en/stmicroelectronics/LSM9DS1TR/497-14946-1-ND/4988079
U7 | N/A | N/A | TPS63001DRCT | TexasInstruments |  | BUCK/BOOST | https://www.digikey.com/product-detail/en/texas-instruments/TPS63001DRCT/296-32517-1-ND/3505619
Y1 | 32.768Khz | 0603 2pin |  |  |  | CRYSTAL | https://www.digikey.com/product-detail/en/epson/FC-135-32.7680KA-A5/SER4103CT-ND/6188447
Y2 | 24.000Mhz | 0603 3pin |  |  |  | CRYSTAL | https://www.digikey.com/product-detail/en/murata-electronics-north-america/XRCGB24M000F0L00R0/490-5575-1-ND/2368389

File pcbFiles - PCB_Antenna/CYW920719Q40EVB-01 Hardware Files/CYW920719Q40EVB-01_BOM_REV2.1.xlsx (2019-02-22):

 | Assembly Number: | CY920719Q40EVB-01
 | Description: | BT KIT CYW9BTWCDEVAL1+CYW920719WCD1
 | Revision: | 2.0
Level | PN | QTY | Ref Des | Description | Critical | Manufacturer | Manufacturer Part Number | Cypress/EMI | Potential FOC
0 | CYW920719Q40EVB-01 |  |  | BT KIT CYW9BTWCDEVAL1+CYW920719WCD1
1 | CYW9BTWCDEVAL1 | 1 |  | ASSY,CYW9BTWCDEVAL1,PRINTED CIRCUIT ASSEMBLY
2 | 600-90523-01 | 1 | * | PCB, CYW9BTWCDEVAL1 |  | * | 600-90523-01 | EMI
2 | 899-90012-01 | 1 |  | IoT Kit Top Assy Label Spec
2 | 899-90220-01 | 1 |  | IoT Kit Top Assy PCA Label and Barcode Spec
2 | 899-90223-01 | 1 |  | GPIO Mapping Label Spec
2 | 610-90523-01 |  |  | DRAWING PCB FABRICATION, CYW9BTWCDEVAL1
2 | 620-90523-01 |  |  | DRAWING, ASSEMBLY, CYW9BTWCDEVAL1
2 | 750-90043-01 | 1 | CBL1 | CBL, USB-A/MICROUSB-B, M/M, 2FT. 4/5P, DATA CABLE |  | Cypress | 750-90043-01
 |  |  |  |  |  | DONG GUAN YILIAN INDUSTRIAL CO.,LTD | 18-94U1NW-001
 |  |  |  |  |  | Monoprice | 4867
 |  |  |  |  |  | Monoprice | 5457
 |  |  |  |  |  | YUHUA | 99-110080-0001
 |  |  |  |  |  | YUHUA | 99-110088-0000
2 | 510-90881-01 | 6 | C1,C2,C3,C7,C11,C48 | CAP,CER,0402,0.1uF,80/20% |  | MURATA | GRM155F51C104ZA01D
 |  |  |  |  |  | Walsin | 0402F104Z160CT
 |  |  |  |  |  | DARFON | C1005Y5V104ZETS
 |  |  |  |  |  | Murata | GRM155F51C104ZA01D
2 | 510-90772-01 | 1 | C4 | CAP,CER,0603,10uF,20% |  | MURATA | GRM188R61A106ME69D
 |  |  |  |  |  | Walsin | 0603X106M100CT
 |  |  |  |  |  | DARFON | C1608X5R106MDTS
 |  |  |  |  |  | Murata | GRM188B31A106ME69D
 |  |  |  |  |  | Murata | GRM188R61A106ME69D
2 | 510-90752-01 | 2 | C5,C39 | CAP,CER,0603,4.7uF,20% |  | Walsin | 0603X475M6R3CT
 |  |  |  |  |  | DARFON | C1608X5R475MCTS
 |  |  |  |  |  | Murata | GRM188R60J475ME84D
2 | 510-90749-01 | 19 | C6,C8,C10,C21,C22,C23,C24,C25,C29,C30,C31,C32,C34,C36,C38,C41,C42,C43,C46 | CAP,CER,0402,0.1uF,10% |  | DARFON | C1005X7R104KETS
 |  |  |  |  |  | Walsin | 0402B104K160CT
 |  |  |  |  |  | DARFON | C1005X7R104KETA
 |  |  |  |  |  | DARFON | C1005X7R104KETS
 |  |  |  |  |  | Murata Electronics North America | GRM155R71C104KA88D
2 | 510-90884-01 | 1 | C9 | CAP,CER,0402,10uF,20% |  | MURATA | GRM155R61A106ME11D
 |  |  |  |  |  | Walsin | 0402X106M100CT
 |  |  |  |  |  | DARFON | C1005X5R106MDTS
 |  |  |  |  |  | Murata Electronics North America | GRM155R61A106ME11D
2 | 510-90736-01 | 1 | C12 | CAP,CER,0402,0.01uF,10% |  | TDK | C1005X7R1C103KT
 |  |  |  |  |  | Walsin | 0402B103K160CT
 |  |  |  |  |  | DARFON | C1005X7R103KETS
 |  |  |  |  |  | TDK Corporation | C1005X7R1C103KT
 |  |  |  |  |  | Samsung | CL05B103KO5NNNC
 |  |  |  |  |  | Taiyo Yuden | EMK105BJ103KV-F
 |  |  |  |  |  | Murata | GRM155R71C103KA01D
 |  |  |  |  |  | Murata Electronics North America | GRM155R71C103KA01E
 |  |  |  |  |  | Murata | GRM155R71E103KA01D
 |  |  |  |  |  | Murata | GRM155R71E103KA01J
 |  |  |  |  |  | Taiyo Yuden | UMK105BJ103KV-F
2 | 510-90893-01 | 1 | C13 | CAP,CER,0603,4.7uF,10% |  | Walsin | 0603X475K6R3CT
 |  |  |  |  |  | DARFON | C1608X5R475KCTS
 |  |  |  |  |  | Murata Electronics North America | GRM188R60J475KE19D
2 | 510-90946-01 | 1 | C15 | CAP,CER,0402,0.33uF,10% |  | TDK | C1005X5R1H331
 |  |  |  |  |  | TDK | C1005X5R1H331K050BA
 |  |  |  |  |  | Murata | GRM15XR11H331KA86D
2 | 510-90716-01 | 2 | C16,C17 | CAP,CER,0603,10uF,20% |  | Walsin | 0603X106M6R3CT
 |  |  |  |  |  | TDK Corporation | C1608X5R0J106M080AB
 |  |  |  |  |  | TDK Corporation | C1608X5R0J106MTJ00N
 |  |  |  |  |  | DARFON | C1608X5R106MCTS
 |  |  |  |  |  | Murata | GRM188R60J106ME47D
 |  |  |  |  |  | Taiyo Yuden | JMK107BJ106MA-T
2 | 510-90732-01 | 1 | C18 | CAP,CER,0402,1uF,10% |  | MURATA | GRM155R61A105KE15D
 |  |  |  |  |  | Walsin | 0402X105K100CT
 |  |  |  |  |  | DARFON | C1005X5R105KDT
 |  |  |  |  |  | Murata | GRM155R61A105KE15D
2 | 510-90884-01 | 2 | C19,C20 | CAP,CER,0402,10uF,20% |  | MURATA | GRM155R61A106M
 |  |  |  |  |  | Walsin | 0402X106M100CT
 |  |  |  |  |  | DARFON | C1005X5R106MDTS
 |  |  |  |  |  | Murata Electronics North America | GRM155R61A106ME11D
2 | 510-90743-01 | 1 | C28 | CAP,CER,0402,0.1uF,10% |  | TDK | C1005X5R1A104KT
 |  |  |  | 510-90743-01 |  | Walsin | 0402X104K100CT
 |  |  |  |  |  | DARFON | C1005X5R104KDTS
 |  |  |  |  |  | Murata | GRM155R61A104KA01D
2 | 510-90894-01 | 3 | C33,C35,C37 | CAP,CER,0402,4.7uF,20% |  | MURATA | GRM155R60J475ME87D
 |  |  |  |  |  | Walsin | 0402X475M6R3CT
 |  |  |  |  |  | DARFON | C1005X5R475MCTS
 |  |  |  |  |  | Murata | GRM155R60J475ME47D
 |  |  |  |  |  | Murata | GRM155R60J475ME87D
2 | 510-90747-01 | 1 | C40 | CAP,CER,0402,3.3uF,20% |  | TDK | C1005X5R0J335M050BC
 |  |  |  |  |  | TDK Corporation | C1005X5R0J335M050BC
2 | 510-90746-01 | 2 | C44,C45 | CAP,CER,0402,9pF,0.25pF |  | MURATA | GRM1555C1H9R0CA01D
 |  |  |  |  |  | Walsin | 0402N9R0C500LT
 |  |  |  |  |  | Murata | GJM1555C1H9R0CB01J
 |  |  |  |  |  | Murata Electronics North America | GRM1555C1H9R0CA01D
2 | 534-90114-01 | 2 | D1,D6 | DIO,LED,SMT,1.9V,5mA |  | KINGBRIGHT | APT1608SGD3
 |  |  |  |  |  | Kingbright | APT1608SGD3
 |  |  |  |  |  | Broadcom | QSMG-C19W
2 | 534-90115-01 | 1 | D2 | DIO,LED,0603,1.8/2.4V,40mA |  | LITEON | LTST-C190CKT
 |  |  |  |  |  | Lite-On Trading USA, Inc. | LTST-C190CKT
 |  |  |  |  |  | Avago Technologies | QSMH-C19H
2 | 530-90181-01 | 2 | D3,D5 | DIO,SHK,SOD128,30V,2A |  | Nexperia USA Inc | PMEG3020BEP
 |  |  |  |  |  | Nexperia USA Inc | PMEG3020BEP
2 | 530-90162-01 | 2 | D7,D11 | DIO,LED,SMT,1.95/2.1V,20mA,1.6x1.5x0.7mm |  | KINGBRIGHT | APTB1615SURKCGKC-F01
 |  |  |  |  |  | Kingbright | APTB1615SURKCGKC-F01
 |  |  |  |  |  | EVERLIGHT | EAST1615RGA0
 |  |  |  |  |  | Broadcom | QSMF-C184
2 | 530-90163-01 | 3 | D8,D9,D10 | VAR,CER,0402,10V,0.5pF |  | AMOTECH | ADUC10S020R5
 |  |  |  |  |  | AMOTECH | ADUC10S020R5
2 | 520-90177-01 | 3 | FB1,FB2,FB3 | IND,FB,0402,600,25% |  | MURATA | BLM15AG601SN1D
 |  |  |  |  |  | Taiyo Yuden | BK1005HW601-T
 |  |  |  |  |  | Murata Electronics North America | BLM15AG601SN1D
2 | 542-90083-01 | 1 | G1 | XTL,OSC,SMT,32.768KHz,5/23PPM |  | EPSON TOYOCOM | SG-3030LC_32.7680K_B0:ROHS
 |  |  |  |  |  | EPSON TOYOCOM | SG-3030LC 32.7680KB3 PURE SN
 |  |  |  |  |  | EPSON TOYOCOM | SG-3030LC 32.7680K B0:ROHS
 |  |  |  |  |  | EPSON TOYOCOM | SG-3030LC 32.7680K B3:ROHS
2 | 720-90460-01 | 2 | J1,J2 | CON,HDR,T/H,M,STR,1X10P |  | SULLINS | PBC10SAAN
 |  |  |  |  |  | Sullins Connector Solutions | PBC10SAAN
2 | 720-90445-01 | 1 | J3 | CON,RCPT,T/H,F,STR,1x10P,25.9x2.54x8.50mm |  | SULLINS | NPPC101LFBN-RC
 |  |  |  |  |  | Centronic Precision Electronic Co | 200-10
 |  |  |  |  |  | Sullins Connector Solutions | NPPC101LFBN-RC
 |  |  |  |  |  | Sullins Connector Solutions | PPPC101LFBN-RC
2 | 720-90453-01 | 2 | J4,J11 | CON,RCPT,T/H,F,STR,1x8P,20.82x2.54x8.50mm |  | SULLINS | NPPC081LFBN-RC
 |  |  |  |  |  | Centronic Precision Electronic Co | 200-08
 |  |  |  |  |  | Sullins Connector Solutions | NPPC081LFBN-RC
 |  |  |  |  |  | Sullins Connector Solutions | PPPC081LFBN-RC
2 | 710-90087-01 | 2 | J5,J10 | CON,HDR,T/H,M,STR,2X4P |  | SULLINS | PBC04DAAN
 |  |  |  |  |  | Sullins Connector Solutions | PBC04DAAN
2 | 720-90480-01 | 1 | J6 | CON,MICROUSB,SMT,F,R/A,5P,7.89x2.89x5.58mm |  | TE Connectivity | 2013499-1
 |  |  |  |  |  | TE Connectivity | 2013499-1
 |  |  |  |  |  | SHENZHEN MUP INDUSTRIAL | MUP-U521
2 | 720-90530-01 | 2 | J7,J8 | CON,HDR,T/H,M,STR,2X3P |  | SULLINS | PBC03DAAN
 |  |  |  |  |  | Sullins Connector Solutions | PBC03DAAN
2 | 720-90446-01 | 1 | J12 | CON,RCPT,T/H,F,STR,1x6P,15.74x2.54x8.50mm |  | SULLINS | NPPC061LFBN-RC
 |  |  |  |  |  | Centronic Precision Electronic Co | 200-06
 |  |  |  |  |  | Sullins Connector Solutions | NPPC061LFBN-RC
 |  |  |  |  |  | Sullins Connector Solutions | PPPC061LFBN-RC
2 | 720-90531-01 | 1 | J13 | CON,HDR,T/H,M,STR,2X5P |  | CNC TECH | 3220-10-0100-00
 |  |  |  |  |  | CNC Tech | 3220-10-0100-00
2 | 720-90456-01 | 2 | J14,J15 | CON,HDR,T/H,M,STR,1x2P |  | SULLINS | PBC02SAAN
 |  |  |  |  |  | Molex | 22-28-4020
 |  |  |  |  |  | TE Connectivity | 4-103327-4
 |  |  |  |  |  | Sullins Connector Solutions | PBC02SAAN
2 | 520-90224-01 | 1 | L4 | IND,FXD,2520,1uH,20% |  | CHILISIN | BDCDBM2520101R0MS1
 |  |  |  |  |  | CHILISIN | BDCDBM2520101R0MS1
2 | 700-90145-01 | 4 | MT1,MT2,MT3,MT4 | BUMPER CYLIN 0.375 DIA BLK |  | 3M | SJ61A4
 |  |  |  |  |  | 3M | SJ61A4
2 | 500-90842-01 | 15 | R4,R5,R6,R12,R13,R15,R17,R19,R20,R28,R29,R100,R101,R102,R103 | RES,THK,0402,0,5% |  | YAGEO | RC0402JR-070RL
 |  |  |  |  |  | VIKING TECH | CR-02JL6----0R
 |  |  |  |  |  | Panasonic-ECG | ERJ-2GE0R00X
 |  |  |  |  |  | CYNTEC | PFR05X-000-XNH
 |  |  |  |  |  | Yageo America | RC0402JR-070RL
 |  |  |  |  |  | KOA Speer Electronics | RK73Z1ETQTP
 |  |  |  |  |  | Walsin | WR04X000PTL
2 | 500-90865-01 | 1 | R10 | RES,THK,0402,100,5% |  | CYNTEC | RR0510-101-JNH
 |  |  |  |  |  | VIKING TECH | CR-02JL6--100R
 |  |  |  |  |  | CYNTEC | RR0510-101-JNH
 |  |  |  |  |  | RALEC | RTT02101JTH
 |  |  |  |  |  | Walsin | WR04X101JTL
2 | 500-90842-01 | 2 | R11,R72 | RES,THK,0402,0,5% |  | YAGEO | RC0402JR-070RL
 |  |  |  |  |  | VIKING TECH | CR-02JL6----0R
 |  |  |  |  |  | Panasonic-ECG | ERJ-2GE0R00X
 |  |  |  |  |  | CYNTEC | PFR05X-000-XNH
 |  |  |  |  |  | Yageo America | RC0402JR-070RL
 |  |  |  |  |  | KOA Speer Electronics | RK73Z1ETQTP
 |  |  |  |  |  | Walsin | WR04X000PTL
2 | 500-90864-01 | 6 | R16,R18,R42,R43,R46,R47 | RES,THK,0402,200,5% |  | KOA | RK73B1ETTP201J
 |  |  |  |  |  | VIKING TECH | CR-02JL6--200R
 |  |  |  |  |  | CYNTEC | PFR05S-201-JNH
 |  |  |  |  |  | Yageo America | RC0402JR-07200RL
 |  |  |  |  |  | KOA Speer Electronics | RK73B1ETTP201J
 |  |  |  |  |  | RALEC | RTT02201JTH
 |  |  |  |  |  | Walsin | WR04X201JTL
2 | 500-90843-01 | 4 | R21,R25,R53,R54 | RES,THK,0402,4.7K,5% |  | CYNTEC | PFR05S-472-JNH
 |  |  |  |  |  | VIKING TECH | CR-02JL6---4K7
 |  |  |  |  |  | Panasonic-ECG | ERJ-2GEJ472X
 |  |  |  |  |  | Panasonic-ECG | ERJ-2RKF4701X
 |  |  |  |  |  | CYNTEC | PFR05S-472-JNH
 |  |  |  |  |  | KOA Speer Electronics | RK73B1ETQTP472J
 |  |  |  |  |  | TA-I/TYEE | RM04JTN472
 |  |  |  |  |  | RALEC | RTT02472JTH
 |  |  |  |  |  | Walsin | WR04X472JTL
2 | 500-90845-01 | 8 | R22,R26,R41,R48,R49,R50,R51,R97 | RES,THK,0402,10K,5% |  | CYNTEC | PFR05S-103-JNH
 |  |  |  |  |  | VIKING TECH | CR-02JL6---10K
 |  |  |  |  |  | Panasonic-ECG | ERJ-2GEJ103X
 |  |  |  |  |  | Panasonic-ECG | ERJ2GEJ103X
 |  |  |  |  |  | CYNTEC | PFR05S-103-JNH
 |  |  |  |  |  | Yageo America | RC0402JR-0710KL
 |  |  |  |  |  | KOA Speer Electronics | RK73B1ETQTP103J
 |  |  |  |  |  | TA-I/TYEE | RM04JTN103
 |  |  |  |  |  | RALEC | RTT02103JTH
 |  |  |  |  |  | Walsin | WR04X103JTL
2 | 500-90854-01 | 2 | R23,R24 | RES,THK,0402,10K,1% |  | KOA | RK73H1ETTP1002F
 |  |  |  |  |  | VIKING TECH | CR-02FL6---10K
 |  |  |  |  |  | Panasonic-ECG | ERJ-2RKF1002X
 |  |  |  |  |  | CYNTEC | PFR05S-1002-FNH
 |  |  |  |  |  | KOA Speer Electronics | RK73H1ETTP1002F
 |  |  |  |  |  | RALEC | RTT021002FTH
 |  |  |  |  |  | Walsin | WR04X1002FTL
2 | 500-90994-01 | 2 | R27,R32 | RES,THK,0402,100K,1% |  | CYNTEC | PFR05S-104-FNH
 |  |  |  |  |  | VIKING TECH | CR-02FL6--100K
 |  |  |  |  |  | Panasonic-ECG | ERJ-2RKF1003X
 |  |  |  |  |  | CYNTEC | PFR05S-104-FNH
 |  |  |  |  |  | Yageo America | RC0402FR-07100KL
 |  |  |  |  |  | Yageo America | RC0402FR-13100KL
 |  |  |  |  |  | KOA Speer Electronics | RK73H1ETQTP1003F
 |  |  |  |  |  | TA-I/TYEE | RM04FTN1003
 |  |  |  |  |  | RALEC | RTT021003FTE
 |  |  |  |  |  | RALEC | RTT021003FTH
 |  |  |  |  |  | RALEC | RTT021003FTP
 |  |  |  |  |  | Walsin | WR04X1003FGL
 |  |  |  |  |  | Walsin | WR04X1003FQL
 |  |  |  |  |  | Walsin | WR04X1003FTL
2 | 500-91060-01 | 1 | R30 | NTC THERMISTOR 100K OHM 1% 0402 | Y | Murata | NCU15WF104F60RC
 |  |  |  |  |  | Murata | NCU15WF104F60RC
2 | 500-90870-01 | 1 | R34 | RES,THK,0402,470K,1% |  | VIKING TECH | CR-02FL6---470K
 |  |  |  |  |  | CYNTEC | PFR05S-4703-FNH
 |  |  |  |  |  | CHILISIN | RTT024703FTH
 |  |  |  |  |  | Walsin | WR04X4703FTL
2 | 500-91002-01 | 1 | R35 | RES,THK,0402,330,5% |  | KOA | RK73B1ETTP331J
 |  |  |  |  |  | VIKING TECH | CR-02JL6--330R
 |  |  |  |  |  | KOA Speer Electronics | RK73B1ETTP331J
2 | 500-90871-01 | 1 | R37 | RES,THK,0402,150K,1% |  | KOA SPEER ELECTRONICS | RK73H1ETQTP1503F
 |  |  |  |  |  | VIKING TECH | CR-02FL6--150K
 |  |  |  |  |  | CYNTEC | PFR05S-1503-FNH
 |  |  |  |  |  | KOA Speer Electronics | RK73H1ETQTP1503F
 |  |  |  |  |  | RALEC | RTT021503FTH
 |  |  |  |  |  | Walsin | WR04X1503FTL
2 | 500-91004-01 | 1 | R44 | RES,THK,0402,12K,1% |  | KOA | RK73H1ETTP1202F
 |  |  |  |  |  | KOA Speer Electronics | RK73H1ETTP1202F
2 | 500-91005-01 | 1 | R45 | RES,THK,0402,1K,1% |  | KOA | RK73H1ETTP1001F
 |  |  |  |  |  | KOA Speer Electronics | RK73H1ETTP1001F
2 | 500-91049-01 | 1 | R52 | RES,THK,0402,2.2K,5% |  | KOA | RK73B1ETTP222J
 |  |  |  |  |  | Panasonic-ECG | ERJ-2GEJ222X
 |  |  |  |  |  | KOA Speer Electronics | RK73B1ETTP222J
2 | 500-90842-01 | 2 | R98,R99 | RES,THK,0402,0,5% |  | YAGEO | RC0402JR-070RL
 |  |  |  |  |  | VIKING TECH | CR-02JL6----0R
 |  |  |  |  |  | Panasonic-ECG | ERJ-2GE0R00X
 |  |  |  |  |  | CYNTEC | PFR05X-000-XNH
 |  |  |  |  |  | Yageo America | RC0402JR-070RL
 |  |  |  |  |  | KOA Speer Electronics | RK73Z1ETQTP
 |  |  |  |  |  | Walsin | WR04X000PTL
2 | 770-90102-01 | 3 | SW1,SW2,SW3 | SWH,PSH,SMT,STR,SPST |  | OMRON | B3SN-3012
 |  |  |  |  |  | Omron | B3SN-3012
2 | 770-90105-01 | 1 | SW4 | SWH,DIP,SMT,STR,SPST,1.5x6.15x3.76mm |  | GRAYHILL | 97C02SRT
 |  |  |  |  |  | Grayhill Inc | 97C02SRT
 |  |  |  |  |  | Grayhill Inc | 97C02ST
 |  |  |  |  |  | DIPTRONICS MANUFACTURING INC. | DHN-02F-V
 |  |  |  |  |  | DIPTRONICS MANUFACTURING INC. | DHN-02F-V-T/R
2 | 760-90028-01 | 1 | TH1 | FUSE,RST,1210,13.2V,0.5A | Y | BOURNS | MF-MSMF050-2
 |  |  |  |  |  | BOURNS | MF-MSMF050-2
2 | 720-90454-01 | 4 | TP6,TP7,TP8,TP18 | CON,PIN,T/H,TEST,STR,1PIN |  | KOBI CONN | 151-103-RC
 |  |  |  |  |  | Kobiconn | 151-103-RC
 |  |  |  |  |  | Keystone Electronics | 5006
 |  |  |  |  |  | PINGOOD ENTERPRISE CO. | JT-1P-CIB
2 | 720-90455-01 | 4 | TP12,TP13,TP14,TP17 | CON,PIN,T/H,TEST,STR,1PIN |  | KOBI CONN | 151-107-RC
 |  |  |  |  |  | Kobiconn | 151-107-RC
 |  |  |  |  |  | Keystone Electronics | 5005
 |  |  |  |  |  | PINGOOD ENTERPRISE CO. | JT-1P-CIR
2 | CYW920719WCD1 | 1 | U1 | CYW20719 Carrier Module |  | Cypress | CYW920719WCD1
 |  |  |  |  |  | Cypress | CYW920719WCD1
2 | 450-90396-01 | 1 | U2 | IC,MEMS,LGA24,3D ACCELEROMETER/3D GYROSCOPE/3D MAGNETOMETER,1.9/3.6V | Y | ST MICRO | LSM9DS1
 |  |  |  |  |  | STMicroelectronics | LSM9DS1
2 | 450-90398-01 | 1 | U4 | IC DC/DC CONV 2.5A SD USP-9B01 | Y | TOREX | XCL212B082DR
 |  |  |  |  |  | Torex Semiconductor Ltd | XCL212B082DR
2 | 450-90397-01 | 1 | U5 | IC,REG,USP6EL,1.8V,1.5A,2.7/6.0VIN,INTEGRATED FET | Y | TOREX | XC9261B18DER-G
 |  |  |  |  |  | Torex Semiconductor Ltd | XC9261B18DER-G
2 | 450-90309-01 | 2 | U7,U9 | IC,XLATOR,TSSOP14,XCVR,8Mbps | Y | MAXIM | MAX3378EEUD+
 |  |  |  |  |  | Maxim Integrated Products | MAX3378EEUD+
 |  |  |  |  |  | Maxim Integrated Products | MAX3378EEUD+T
2 | 455-90025-01 | 1 | U8 | IC,USB,QFN64,UART/FIFO,12/480Mbps | Y | FUTURE TECH DEVICES | FT2232HQ-TRAY
 |  |  |  |  |  | Future Technology Devices International Ltd | FT2232HQ-REEL
 |  |  |  |  |  | Future Technology Devices International Ltd | FT2232HQ-TRAY
2 | 302-90014-01 | 1 | U10 | IC,EEPROM,TSSOP8,64x16(1K) |  | ATMEL | AT93C46D-TH-T
 |  |  |  |  |  | ATMEL | AT93C46D-TH-B
 |  |  |  |  |  | ATMEL | AT93C46D-TH-T
 |  |  |  |  |  | ATMEL | AT93C46E-TH-B
 |  |  |  |  |  | ATMEL | AT93C46E-TH-T
 |  |  |  |  |  | ST Microelectronics | M93C46-WDW6TP
2 | 542-90072-01 | 1 | Y1 | XTL,FXD,SMT,12.0000MHz,10PPM,3.2x2.5x0.7mm |  | EPSON TOYOCOM | FA-238V_12.0000MF10V-AC
 |  |  |  |  |  | TXC CORPORATION | 7M12070014
 |  |  |  |  |  | EPSON | FA-238V 12.0000MF10V-AC
 |  |  |  |  |  | EPSON | FA-238V 12.0000MF10V-AC3
2 | 781-90016-01 | 1 | ZB1 | BAT,HOLDER,SMT,20mmD,30.73x19.86x3.96mm |  | KEYSTONE | 3002TR
 |  |  |  |  |  | Keystone Electronics | 3002TR
2 | 720-90463-01 | 12 | ZJ14,ZJ15,ZJ5-1-2,ZJ5-3-4,ZJ5-5-6,ZJ5-7-8,ZJ7-2-4,ZJ8-2-4,ZJ10-1-2,ZJ10-3-4,ZJ10-5-6,ZJ10-7-8 | CON,SHUNT,PTP,F,STR,1x2P |  | SAMTEC | SNT-100-BK-G
 |  |  |  |  |  | TE Connectivity | 382811-6
 |  |  |  |  |  | 3M | 969102-0000-DA
 |  |  |  |  |  | Samtec | SNT-100-BK-G
 |  |  |  |  |  | Samtec Inc | SNT-100-BK-G-H
2 | 630-90523-01 | 0 |  | Schematic, CYW9BTWCDEVAL1 |  | * | 630-90523-01
2 | CYW920719WCD1 |  | U1 | ASSY,CYW920719WCD1,PRINTED CIRCUIT ASSEMBLY
3 | 610-90527-01 |  |  | DRAWING PCB FABRICATION, CYW920719WCD1
3 | 620-90527-01 |  |  | DRAWING, ASSEMBLY, CYW920719WCD1
3 | 600-90527-01 | 1 |  | PCB, CYW920719WCD1 |  |  | 600-90527-01 | EMI
3 | 510-90722-01 | 5 | C1,C8,C14,C18,C68 | CAP,CER,0201,0.1uF,10% |  | MURATA | GRM033R60J104KE19D
 |  |  |  |  |  | Walsin | 0201X104K6R3CT
 |  |  |  |  |  | TDK Corporation | C0603X5R0J104KB
 |  |  |  |  |  | TDK Corporation | C0603X5R0J104KT
 |  |  |  |  |  | DARFON | C0603X5R104KCTS
 |  |  |  |  |  | Taiyo Yuden | JMK063BJ104KP-F
3 | 510-90732-01 | 1 | C3 | CAP,CER,0402,1uF,10% |  | MURATA | GRM155R61A105KE15D
 |  |  |  |  |  | Walsin | 0402X105K100CT
 |  |  |  |  |  | DARFON | C1005X5R105KDT
 |  |  |  |  |  | TDK Corporation | C1005X5R1A105K
 |  |  |  |  |  | Murata | GRM155R61A105KE15J
 |  |  |  |  |  | Taiyo Yuden | LMK105BJ105KV-F
3 | 510-90758-01 | 1 | C4 | CAP,CER,0402,10uF,10% |  | MURATA | GRM155R60J106ME44D
 |  |  |  |  |  | Walsin | 0402X106M6R3CT
 |  |  |  |  |  | DARFON | C1005X5R106MCTS
3 | 510-90737-01 | 2 | C5,C6 | CAP,CER,0201,1uF,20% |  | MURATA | GRM033R60J105MEA2D
 |  |  |  |  |  | Walsin | 0201X105M6R3CT
 |  |  |  |  |  | DARFON | C0603X5R105MCTS
 |  |  |  |  |  | Murata | GRM033R60J105ME11D
3 | 510-90774-01 | 1 | C7 | CAP,CER,0201,2.2uF,20% |  | MURATA | GRM033R60J225ME15D
 |  |  |  |  |  | Walsin | 0201X225M6R3CT
 |  |  |  |  |  | DARFON | C0603X5R225MCTS
 |  |  |  |  |  | Murata | GRM033R60J225ME47
 |  |  |  |  |  | Murata | GRM033R60J225ME47D
3 | 510-90979-01 | 2 | C10,C11 | CAP,CER,0201,12pF,5% | Y | MURATA | GRM0335C1H120JA01D
3 | 510-90980-01 | 1 | C16 | CAP,CER,0201,10pF,5% |  | MURATA | GRM0335C1H100JA01D
 |  |  |  |  |  | Walsin | 0201N100J500CT
3 | 510-90908-01 | 2 | C19,C20 | CAP,CER,0201,6pF,0.1pF | Y | MURATA | GRM0335C1H6R0BA01D
3 | 510-90734-01 | 1 | C43 | CAP,CER,0201,8.2pF,0.5pF | Y | MURATA | GJM0336C1E8R2DB01D
3 | 510-90909-01 | 1 | C61 | CAP,CER,0201,0.033uF,10% |  | MURATA | GRM033R60J333KE01D
3 | 510-90983-01 | 1 | C67 | CAP,CER,0402,8.2pF,0.25pF | Y | MURATA | GJM1555C1H8R2CB01D
3 | 520-90193-01 | 2 | FB1,FB2 | IND,FB,0201,600,25% |  | MURATA | BLM03AX601SN1D
 |  |  |  |  |  | TDK Corporation | MMZ0603S601C
 |  |  |  |  |  | CHILISIN | SBY060303T-601Y-N
3 | 543-90039-01 | 1 | FL1 | FLT,BP,0603,2.45GHz,0.95/1.25dB | Y | MURATA | LFB182G45CL3D178
 |  |  |  |  |  | TDK Corporation | DEA162450BT-1288B1BR
3 | 720-90475-01 | 1 | J3 | CON,COAX,STR,SMT,MICRO,SNAP |  | AMPHENOL | A-1JB
 |  |  |  |  |  | I-PEX | 20431-001E-01
3 | 510-90984-01 | 1 | LC1 | CAP,CER,0402,5.6pF | Y | Murata | GJM1555C1H5R6CB01D
3 | 510-90985-01 | 1 | LC3 | CAP,CER,0402,1pF | Y | Murata | GJM1555C1H1R0BB01D
3 | 520-90283-01 | 1 | L1 | IND,PWR,0806,2.2uH,20% | Y | CHILISIN | BKPEBM2012102R2MA2
3 | 500-90837-01 | 2 | R1,R15 | RES,THK,0201,0,5% |  | KOA | RK73Z1HTQTB
 |  |  |  |  |  | VIKING TECH | CR-01JL6----0R
 |  |  |  |  |  | Panasonic-ECG | ERJ-1GE0R00C
 |  |  |  |  |  | Panasonic-ECG | ERJ1GE0R00C
 |  |  |  |  |  | Panasonic-ECG | ERJ1GN0R00C
 |  |  |  |  |  | Yageo America | RC0201JR-070RL
 |  |  |  |  |  | KOA Speer Electronics | RK73Z1HTQTC
 |  |  |  |  |  | CYNTEC | RR0306S-000-XNH
 |  |  |  |  |  | CHILISIN | RTT01000JTH
 |  |  |  |  |  | Walsin | WR02X000PAL
3 | 500-90855-01 | 1 | R16 | RES,THK,0201,10M,5% |  | Rohm | MCR006YRTJ106
 |  |  |  |  |  | VIKING TECH | CR-01JL6---10M
 |  |  |  |  |  | Panasonic-ECG | ERJ-1GEJ106C
 |  |  |  |  |  | Panasonic-ECG | ERJ1GEJ106C
 |  |  |  |  |  | KOA Speer Electronics | RK73B1HTTB106J
 |  |  |  |  |  | KOA Speer Electronics | RK73B1HTTC106J
 |  |  |  |  |  | CHILISIN | RTT01106JTP
 |  |  |  |  |  | Walsin | WR01X106JAL
3 | 500-90996-01 | 1 | R83 | RES,THK,0201,5.6K,5% |  | CYNTEC | RR0306S-562-JNH
 |  |  |  |  |  | VIKING TECH | CR-01JL6---5K6
 |  |  |  |  |  | Panasonic-ECG | ERJ-1GEJ562C
3 | CYW20719B1KUMLG | 1 | U1
3 |  | 1 | U4 | IC,SUP,4-USPN,1.6V,0.9uA | Y | TOREX | XC6119N16A7R-G
3 | 542-90097-01 | 1 | Y2 | XTL,FXD,SMT,32.768KHz,20PPM | Y | TXC | 9H03270073
3 | 542-90096-01 | 1 | Y3 | XTL,FXD,SMT,24.000MHz,10/10PPM,2x1.6mm | Y | TXC | 8Y24070015

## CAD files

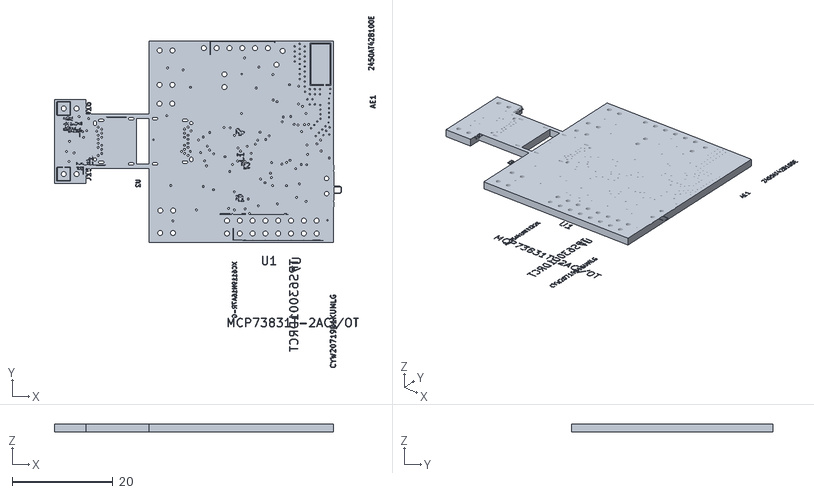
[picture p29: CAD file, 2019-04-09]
pcbFiles - PCB_Antenna/GolfGloveMainBoardV1.0.0.stl
63.6 x 69.7 x 1.70

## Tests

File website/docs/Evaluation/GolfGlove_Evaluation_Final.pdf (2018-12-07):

Golf Glove | 1
ECE 4532: Design I | December 5, 2018

LIST OF ABBREVIATIONS
ADC - Analog Digital Converter
EMR - Electromagnetic Radiation GATT - Generic Attribute
GUI - Graphical User Interface
I2C - Inter-Integrated Circuit
ICNIRP - International Commission on Non-Ionizing Radiation IEC - International Electrotechnical Commission
IMU - Inertial Measurement Unit
IP - Ingress Protection
RF - Radio Frequency
RoHS - Reduction of Hazardous Substances RSSI - Received Signal Strength Indication SAR - Specific Absorption Rate

### 4. EVALUATION

The following section contains the results of the individual subsystem tests as well as a test of the integrated system. Each design constraint was explicitly considered when designing the individual tests. Table 4.1 contains the technical constraints that were tested.
Table 4.1. Technical Design Constraints
Name | Description
Hand Orientation | The glove must determine the angles of wrist flexion, extension, and deviation within a ±3° margin of error. Also, the glove must measure wrist acceleration, hand orientation, and hand acceleration within a ±5% margin of error.
Wireless Communication | The wrist-mounted controller must communicate wirelessly with a range that will span the average width of a tee box: 9.15 m.
Data Display | The data is recorded and displayed at 120 Hz.
Unobtrusive | The user must not be obstructed while gripping the club with the glove on. The wrist-mounted controller must have a footprint smaller than the average sweat-band size of 7.62 cm. The sensor wires in the glove must not interfere with swing motion.
Portability | The minimum battery life of the system must exceed 5 hours of use.

Figure 4.1 displays the system overview.

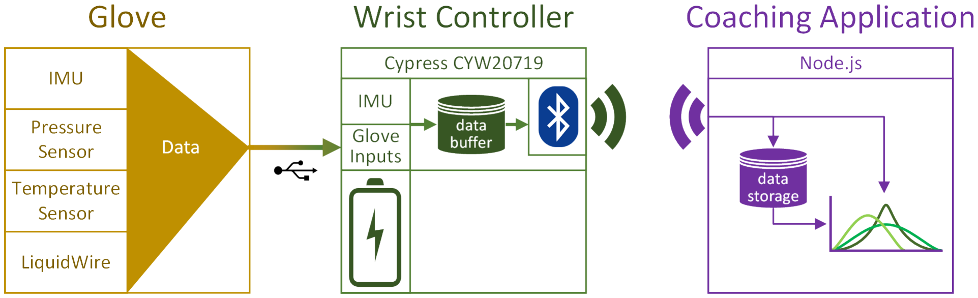
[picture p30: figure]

Figure 4.1. System Overview

### 4.1. Glove Subsystem 4.1.1. Accelerometer

The design is constrained to ±5% margin of error to ensure that the accelerometer records the user’s hand precisely. To test the accelerometer, it was placed on the inside of a 3D printed cube with flat sides on every axis. The cube was placed on each of its three orthogonal sides and the values for X, Y, and Z acceleration were recorded in Table 4.1 below. The percent error for the dimension being tested is listed alongside the measured value. As seen, each sensor reading percent error fell within the required design constraint. Table 4.1 Accelerometer Test
Test Axis | Expected (m/s² ) | Actual (m/s² ) | Error
X | 9.8 | 10.050 | 2.5%
Y | 9.8 | 9.786 | 0.14%
Z | 9.8 | 10.135 | 3.4%

### 4.1.2. Gyroscope

The operation of the gyroscope was tested by rotating the test apparatus on each axis at a rate of 90° per 840 ms. At this rate, the expected degrees per second (dps) is 104.65. Table 4.2 lists this expected value and the value that was measured during the tests for each dimension. Once again, the percent error for each axis satisfied the design constraint of ±5% margin of error.
Table 4.2 Gyroscope Test
Test Axis | Expected (dps) | Actual (dps) | Error
X | 104.65 | 102.417 | 2.13%
Y | 104.65 | 101.726 | 2.79%
Z | 104.65 | 103.129 | 1.45%

### 4.1.3. LiquidWire

The LiquidWire stretch sensors must meet the Hand Orientation technical constraint of measuring the user’s wrist flexion and deviation to within 3° of error. To test the LiquidWire stretch sensors, a sensor was placed on a testing apparatus that emulates the motion of a wrist. This apparatus is seen in Figure 4.2. The lever was moved from its 90° resting position to the final resting position at 0° in 3° increments. The measurements from these increments are graphed in Figure 4.3. This graph shows a linear relationship between angle and resistance while exhibiting a measurable change in resistance between every 3° increment.

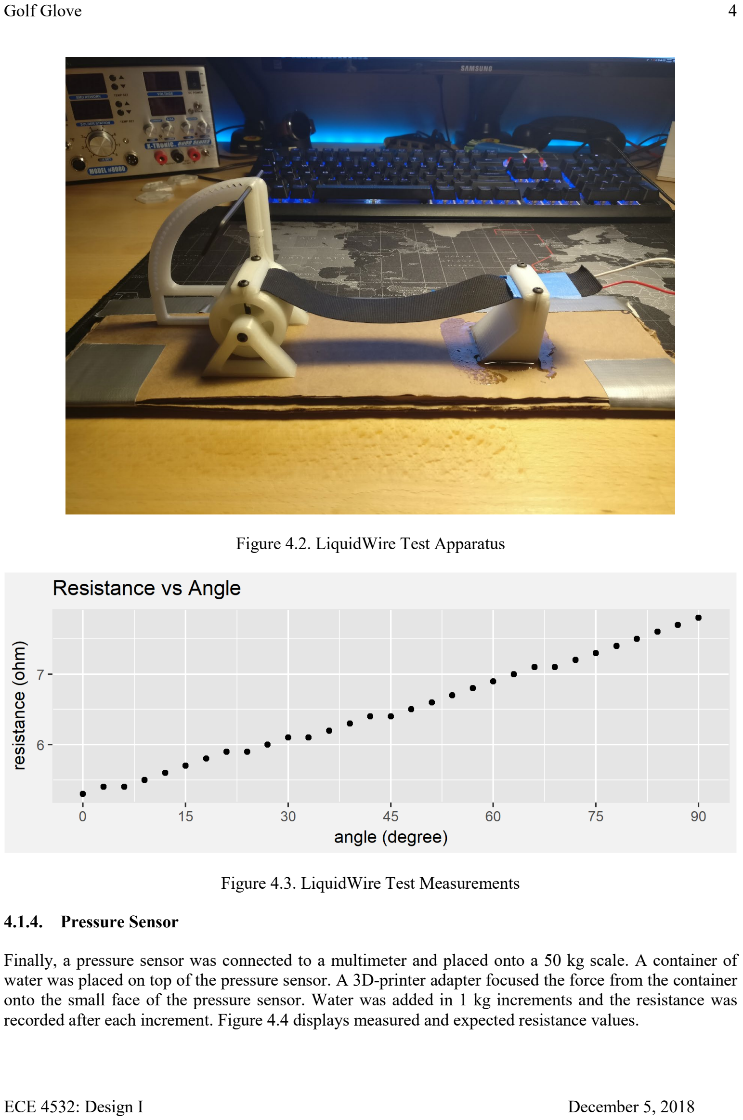
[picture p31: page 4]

Figure 4.2. LiquidWire Test Apparatus

Figure 4.3. LiquidWire Test Measurements

### 4.1.4. Pressure Sensor

Finally, a pressure sensor was connected to a multimeter and placed onto a 50 kg scale. A container of water was placed on top of the pressure sensor. A 3D-printer adapter focused the force from the container onto the small face of the pressure sensor. Water was added in 1 kg increments and the resistance was recorded after each increment. Figure 4.4 displays measured and expected resistance values.

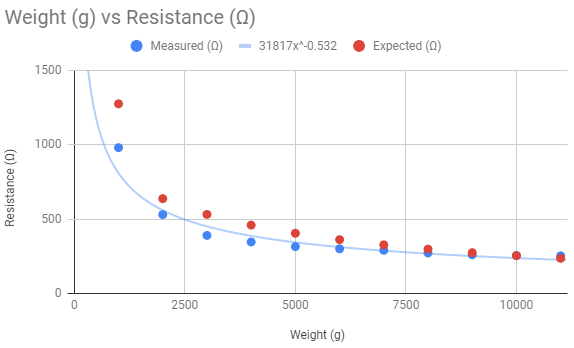
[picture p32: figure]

Figure 4.4. Pressure Sensor Test

### 4.2. Wrist-mounted Microcontroller Subsystem 4.2.1. Battery

The battery was tested using an Arduino, a voltage divider, and a 36 Ω resistor. The battery was fully charged to 4.2 V and connected across the voltage divider. The Arduino was programmed to measure, interpret, and display battery voltage values every 30 seconds. The 36 Ω resistor was attached to the leads of the battery to simulate an average current draw of 0.1 A. Once the battery was depleted, the values were stored and plotted in a Voltage vs. Time graph seen in Figure 4.5.

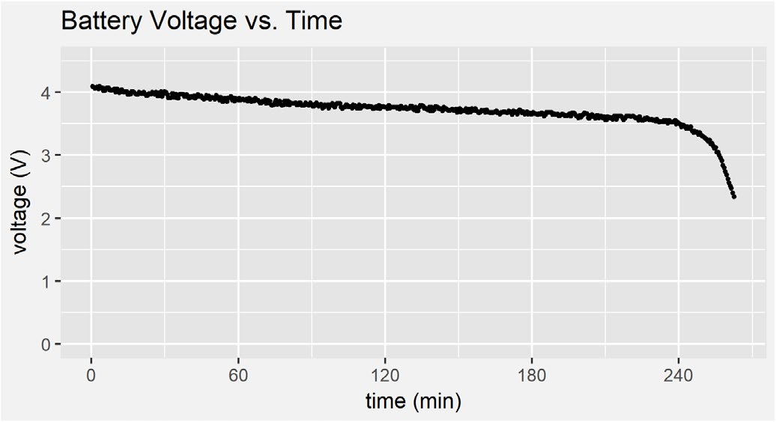
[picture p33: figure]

Figure 4.5. Battery Test
With an elapsed time of 4.375 hours and an average current draw of 0.103 A, the battery discharged 451.5 mAh over the duration of the test. Because the system will draw no more than 90 mA during peak usage, the battery is sufficient to meet the 5-hour runtime constraint.

### 4.2.2. Sensor Polling

To ensure proper operation of the I²
C bus, the first sensor test was to capture digital data transmission. The SDA and SCLK lines from the microcontroller were connected to the D0 and D1 inputs on a National Instruments Mixed Signal Oscilloscope. Next, a trigger was set for the oscilloscope output to trigger on the first data transfer. Figure 4.6 shows the oscilloscope output that depicts a write to the accelerometer with the appropriate read operation and response from the accelerometer.

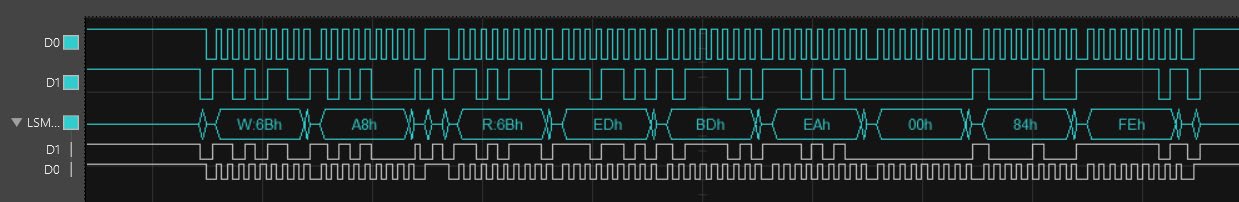
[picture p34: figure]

Figure 4.6. I²
C Sensor Data Transfer
Next, two tests were employed to verify that the Cypress CYW20719 microcontroller and the selected sensor packages were capable of satisfying the Data Display constraint. The first of these tests began reading information from the sensors as fast as the microcontroller would allow and counted the total number of complete sensor frames read during a three second period. The second test, in comparison, measured the period of time required to read a constant number of sensor frames. These two tests yielded similar results and are shown in Table 4.3.
Table 4.3. Sensor Polling Tests
Test | Minimum Required | Actual
Total # of Readings in 3 seconds | >= 360 frames (120 frames/sec) | 4470 frames (1490 frames/sec)
Time to read 10000 sensor frames | <= 83.3 sec (120 frames/sec) | 7 seconds (1428.6 frames/sec)

The slower measured polling rate, 1428.6 frames per second, is over 10 times faster than required by the Data Display constraint.

### 4.2.3. Bluetooth Broadcast

The data throughput capabilities of the Bluetooth communication system were also tested against the Data Display constraints. For this test, the Cypress CYW20719 microcontroller was configured to transmit one 56-byte frame every 8 ms (125 Hz) to the coaching application. Upon reception of the frame by the coaching application, the current time was recorded. The time differences were computed for a few seconds of data. Figure 4.7 shows data frames being received in bursts by the coaching application. These bursts are caused by context switching and Bluetooth buffering of the operating system. However, these bursts do not affect the expected average throughput, which exceeds the design constraint of 120 Hz.

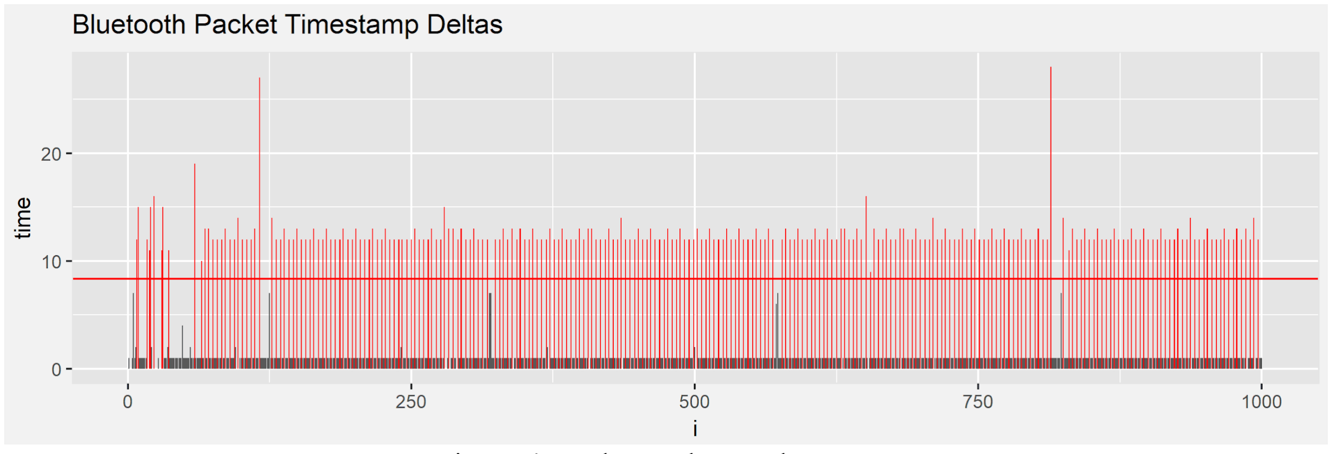
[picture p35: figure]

Figure 4.7. Bluetooth Broadcast Test

### 4.2.4. Hardware Footprint

The Golf Glove system main footprint consists of a Cypress CYW20719 microcontroller and four Analog to Digital Converters (ADC). These two components can be seen in Figure 4.8 and Figure 4.9. In Figure 4.8, the microcontroller and support circuitry are indicated by the red square, approximately 18 mm x 18 mm in size.

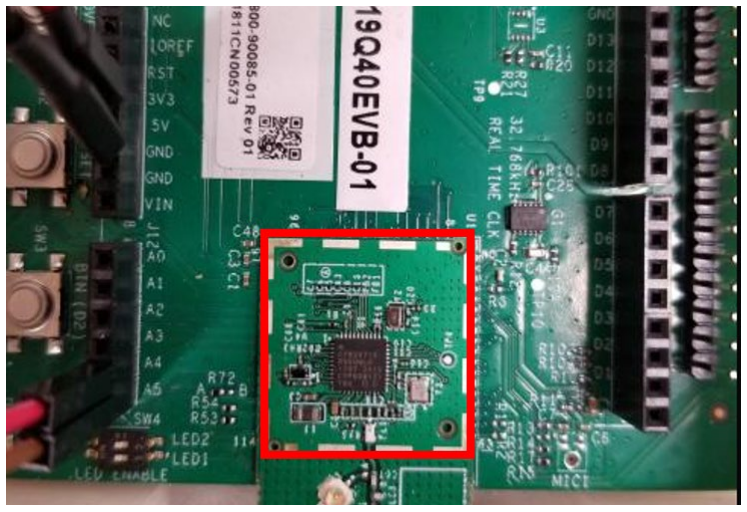
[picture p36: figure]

Figure 4.8. Microcontroller and Support Circuitry In Figure 4.9, the four ADCs are indicated by the red squares. Each ADC is 3 mm x 4 mm.

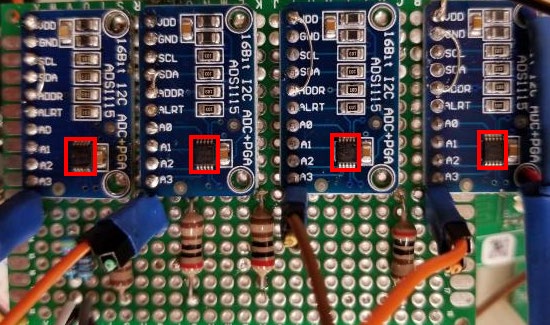
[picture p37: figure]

Figure 4.9
With a combined area of 372 mm²

, the main components are well within our design constraint of 1935.48 mm²

### 4.3. Coaching Application Subsystem 4.3.1. Bluetooth Reception

The Wireless Communication constraint requires that Golf Glove maintains Bluetooth communication at distances up to 9.15 meters. To test that the Golf Glove’s microcontroller satisfies this constraint, firmware that continuously broadcasts data was loaded onto the CYW20719 development board. Using Cypress’ CySmart application on a mobile phone, the RSSI of this broadcast was measured at 1 meter increments up to 15 meters. The graph of RSSI over distance is charted below in Figure 4.10. A signal strength of approximately -67 dBm was measured at 9.15 m.

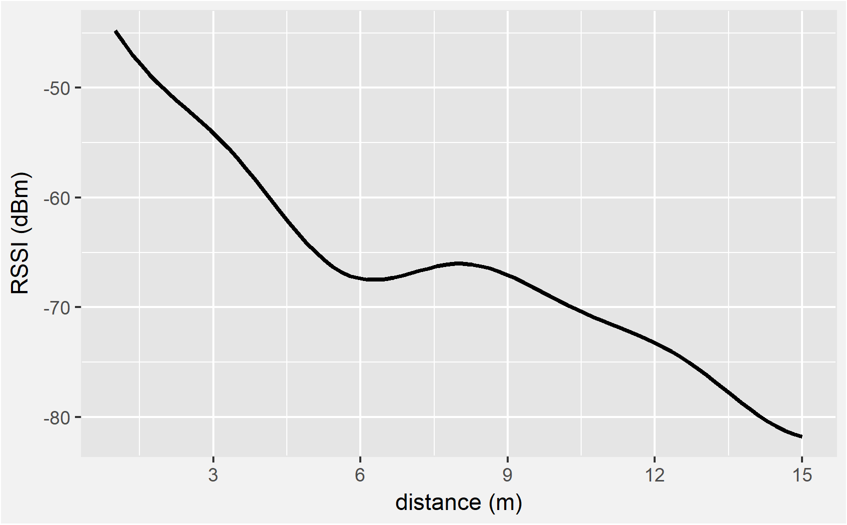
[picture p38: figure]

Figure 4.10. RSSI of Golf Glove Broadcast

### 4.3.2. Database

On the backend of the coaching application, the data must be stored as quickly as it is received to prevent a buffer overflow. Following the Data Display constraint, the write performance of the database must be at least 120 Hz. To test its performance, the coaching application backend wrote 500 data frames to the SQLite database and recorded the timestamp deltas between inserts. All timestamp deltas satisfied the design constraint with an average write performance over 1.3 kHz. Figure 4.11 shows the timestamp deltas for each frame.

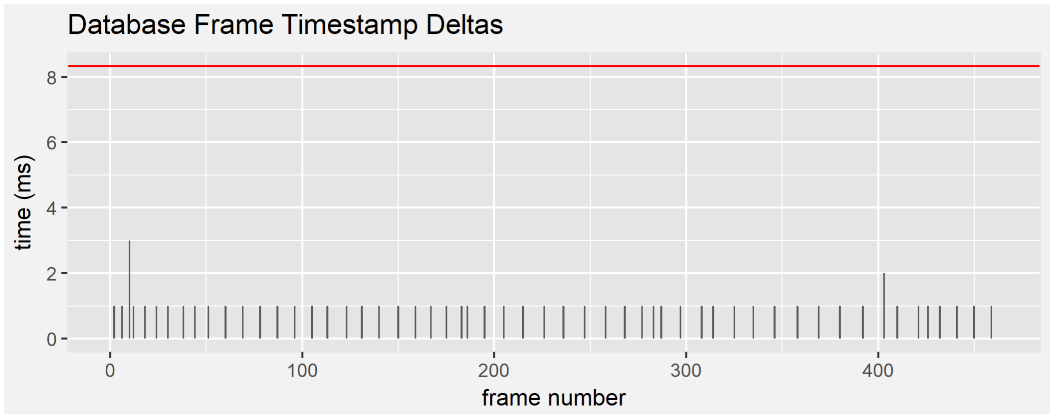
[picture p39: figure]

Figure 4.11. Frame-to-frame delay for 500 frames

### 4.3.3. WebSocket Bandwidth

Meanwhile, the coaching application is also sending sensor frames to the frontend for display. The backendto-frontend communication speed must exceed 120 Hz to support the Data Display constraint. To test the backend-to-frontend throughput, the backend sent 10,000 frames while the frontend recorded the time deltas upon reception of the frame. Figure 4.12 is a graph of the timestamp deltas. The values outlined in red do not meet the constraint delta. Similar to the Bluetooth Throughput test though, this is a consequence of protocol buffering. The application averages 0.6 ms (1.6 kHz) between each data frame, more than 10 times faster than the Data Display constraint.


Figure 4.12. Frame-to-frame delay for 10,000 frames

### 4.4. Integrated System

To complete the integrated system test, the wrist-mounted controller and the coaching application were first powered on. Next, the frontend instructed the backend to connect to the glove. The coaching application successfully connected to the Golf Glove at a distance of 10 m, satisfying the Wireless Communication constraint. Sensor data began streaming to the coaching application and the distance was increased to 48
m. During the test, the wrist-mounted controller remained connected and data was received on the frontend at a rate of at least 120 Hz, satisfying the Data Display constraint. Figure 4.13 and Figure 4.14 show the two components of the integrated system test.


Figure 4.13. The glove and wrist-mounted controller


Figure 4.14. The coaching application display Table 4.4 is a summary of the tests performed in Golf Glove’s evaluation. All tests passed and the system surpassed expectations.

Table 4.4: Summary of Tests
Technical Constraints | Test Results
Hand Orientation | LiquidWire measured to have linear relationship between resistance and stretch, and accuracy measured within 3°. Accelerometer and gyroscope measured to within 5% margin of error.
Wireless Communication | Wireless communication tested greater than 9.15 m.
Data Display | WebSockets tested to achieve greater than 120 Hz.
Unobtrusive | With a combined area of 3.72 cm² , the main components fit within an area of 19.35 cm² .
Portability | Battery was able to successfully supply enough capacity to power the device for a minimum of 5 hours.

### 5. SUMMARY AND FUTURE WORK

Throughout the design process, several problems were encountered. The problems that impacted the overall design are broken down by hardware, microcontroller, and coaching application sections. The current system records inertial, pressure, and stretch sensors. The design is currently limited by a cumbersome development board and by stretch sensor mounting difficulties. Future developments involving the Golf Glove system are discussed below.

### 5.1. Hardware

The design initially used the integrated ADCs on the Cypress CYW20719 chip to poll the LiquidWire and pressure sensors. Due to the low change in resistance between the resting and stretched states of LiquidWire sensors, programmable gain amplifiers are necessary. To mitigate this problem, a Texas Instruments ADS1115 16-bit ADC was selected, predicting that it would allow four LiquidWire sensor readings simultaneously. An issue arose from this solution: the ADS1115 contains only one internal ADC and switches between each analog input to complete conversions. This switching introduced a delay into the system that prevented the glove from reading all sensors simultaneously and was too slow to meet speed constraints. To solve this problem, three additional ADCs were added to the design.
More issues arose when upon mounting the stretch sensors on the wrist-mounted unit. LiquidWire’s stretch sensors must remain taut to output useful data to the glove. Any amount of slack in the sensors results in inaccurate and unusable resistance values. The initial design required attaching a strap on the wrist-mounted controller that could be tightened around the user’s wrist. When the user tightens the wrist unit such that the LiquidWire sensors are held taut, the tightened strap becomes uncomfortable and hinders the movement of the user. The design was modified to use a compression sleeve outfitted with internal rubber to provide adequate friction around the arm and keep the wrist-mounted controller stationary. Unfortunately, the sleeve did not prevent sliding of the wrist-mounted controller, loosened the LiquidWire, and compromised the data gathered from the sensors.

### 5.2. Microcontroller

The Cypress CYW20719 microcontroller also required specific initialization for system data types and functions such as threading, timers, and queues. Initially, the team was unfamiliar with the syntax of using these functions. Cypress BLE chips are a relatively new product for the company and thus the documentation was lacking. After contacting Cypress Customer Support, the team was provided with example code explaining the syntax and functionality of these resources in the Real-Time Operating System.
Also, in order to conserve memory and processing power, the microcontroller doesn’t support floatingpoint arithmetic. Originally, the firmware intended to handle data parsing such as converting I²
C reads from
unsigned 8-bit integers to float objects; however, due to the restriction on the microcontroller, data parsing and formatting code was moved to the backend server of the coaching application.

### 5.3. Coaching Application

During development, the team quickly found there were dependency issues preventing Bluetooth reception. The main issue occurred between noble (the Bluetooth framework chosen in the Approach) and Electron (the desktop environment used for rendering the GUI) were incompatible. To resolve this compatibility issue, the frontend GUI was changed to simply render the data in an internet browser. This change required creating an HTTP server to communicate the sensor frames from the backend to the frontend as this architecture requires two separate processes to run noble and the frontend rendering. WebSockets were chosen as the backend to frontend communication protocol to allow the backend to push data to the frontend without explicit requests for data from the frontend.

### 5.4. Future Features

The Golf Glove firmware currently exposes raw sensor values to the coaching application in real-time mode, allowing for any application that can interface with BLE to connect and read sensor values. One future application could add an RFID sensor to the glove to detect golf club type with special RFID tags embedded in the club handle. Swing detection characteristics could be modified based on the club type to enable detection of different swing types such as chipping or putting.
The Golf Glove could also pair with a golf scoring application to record swings and golf scores in a database. Once many swings across multiple rounds of golf are recorded, a machine learning algorithm could be used to identify common characteristics of successful golf swing technique as well as common swing mistakes.

### 6. ACKNOWLEDGEMENTS

The Golf Glove team would like to thank the following people:
Dr. John Ball, Assistant Professor in the Electrical and Computer Engineering Department at Mississippi State University, for providing initial introductions to the athletic department and his support of our project. Tony Luczak, Graduate Research Assistant in the Recreational Sports Department at Mississippi State University, for providing expert advice in golf technique and business modeling.
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

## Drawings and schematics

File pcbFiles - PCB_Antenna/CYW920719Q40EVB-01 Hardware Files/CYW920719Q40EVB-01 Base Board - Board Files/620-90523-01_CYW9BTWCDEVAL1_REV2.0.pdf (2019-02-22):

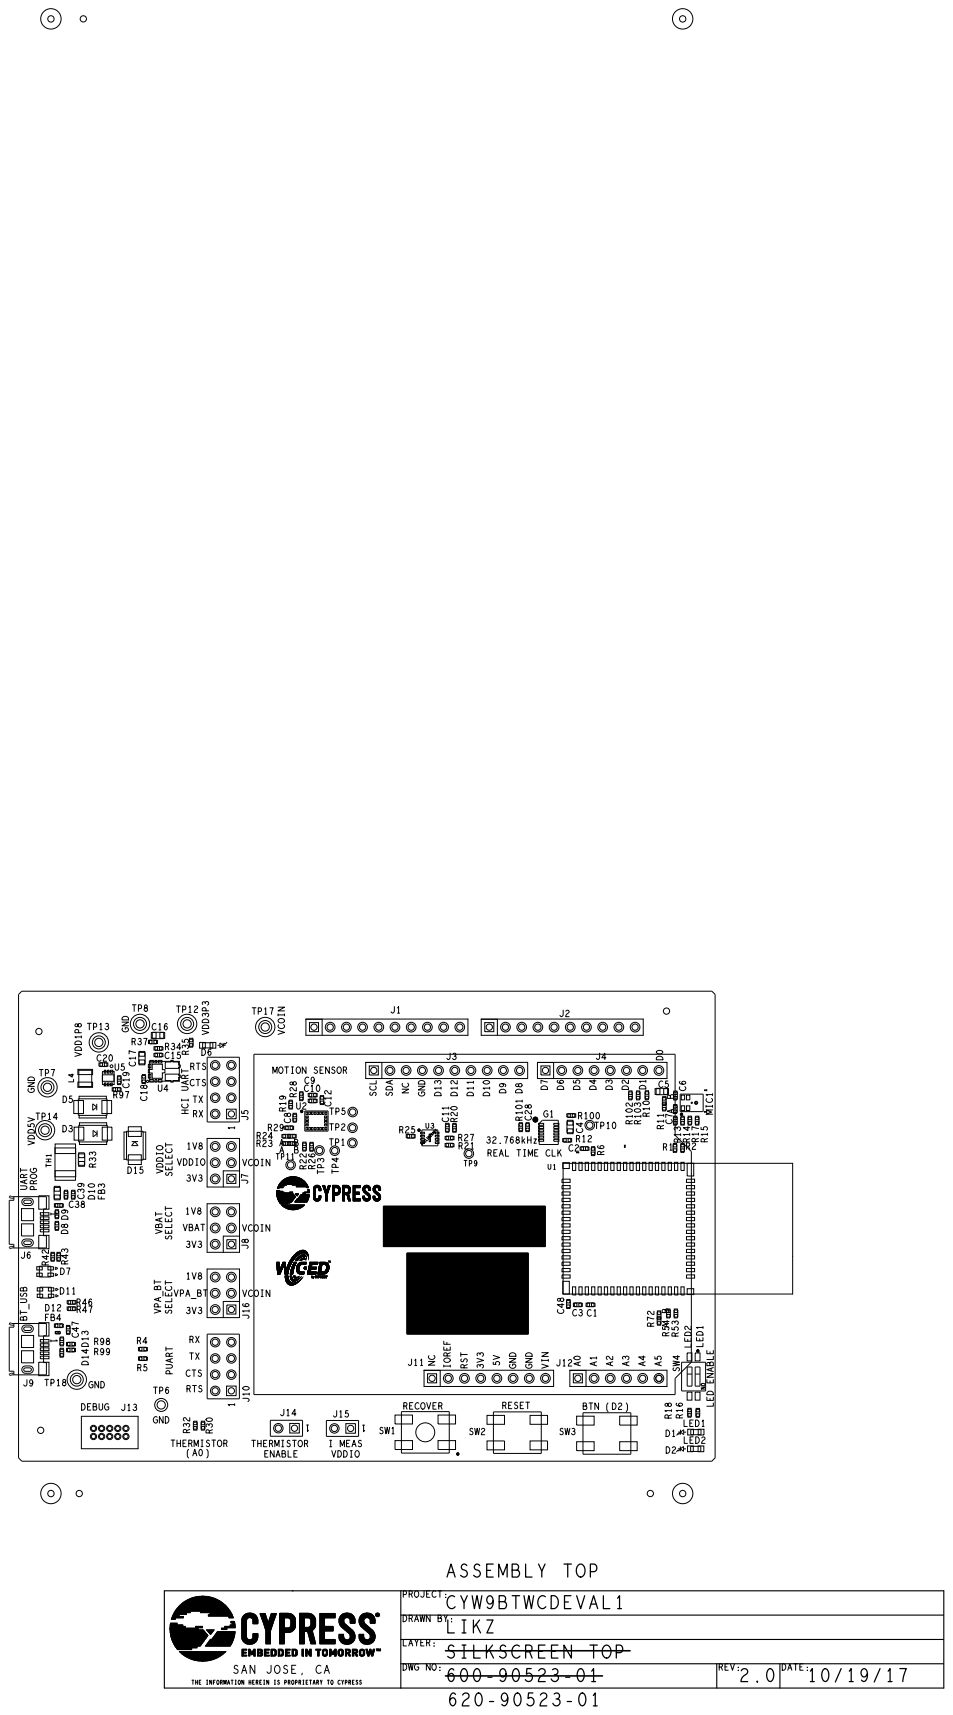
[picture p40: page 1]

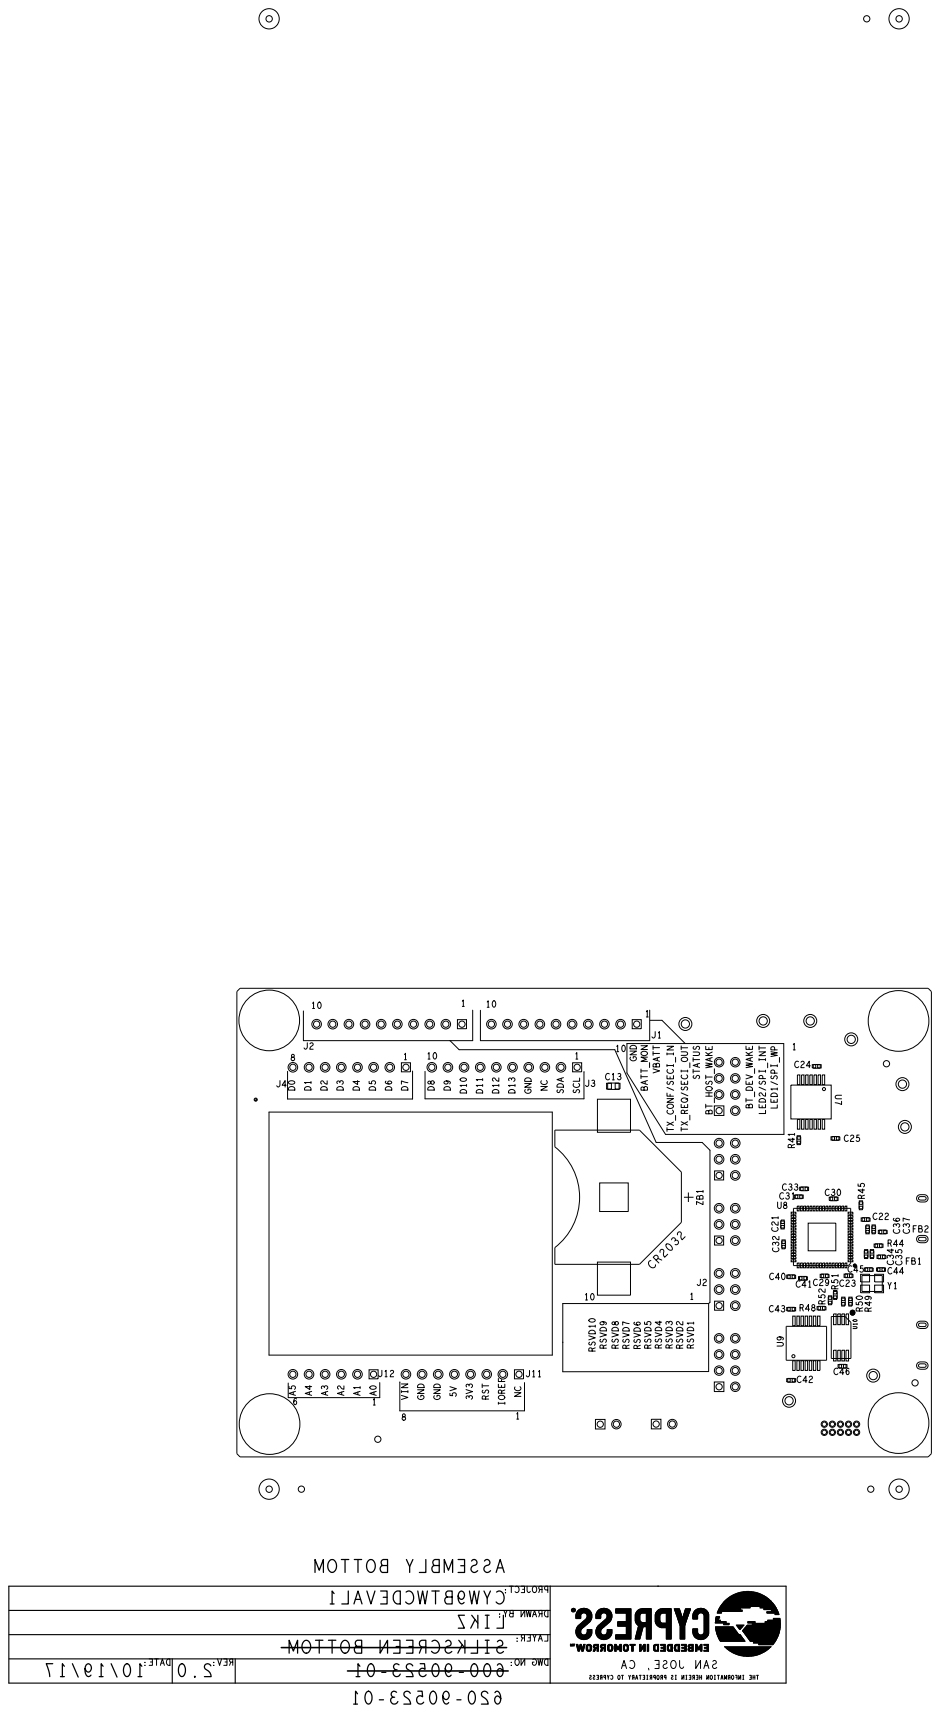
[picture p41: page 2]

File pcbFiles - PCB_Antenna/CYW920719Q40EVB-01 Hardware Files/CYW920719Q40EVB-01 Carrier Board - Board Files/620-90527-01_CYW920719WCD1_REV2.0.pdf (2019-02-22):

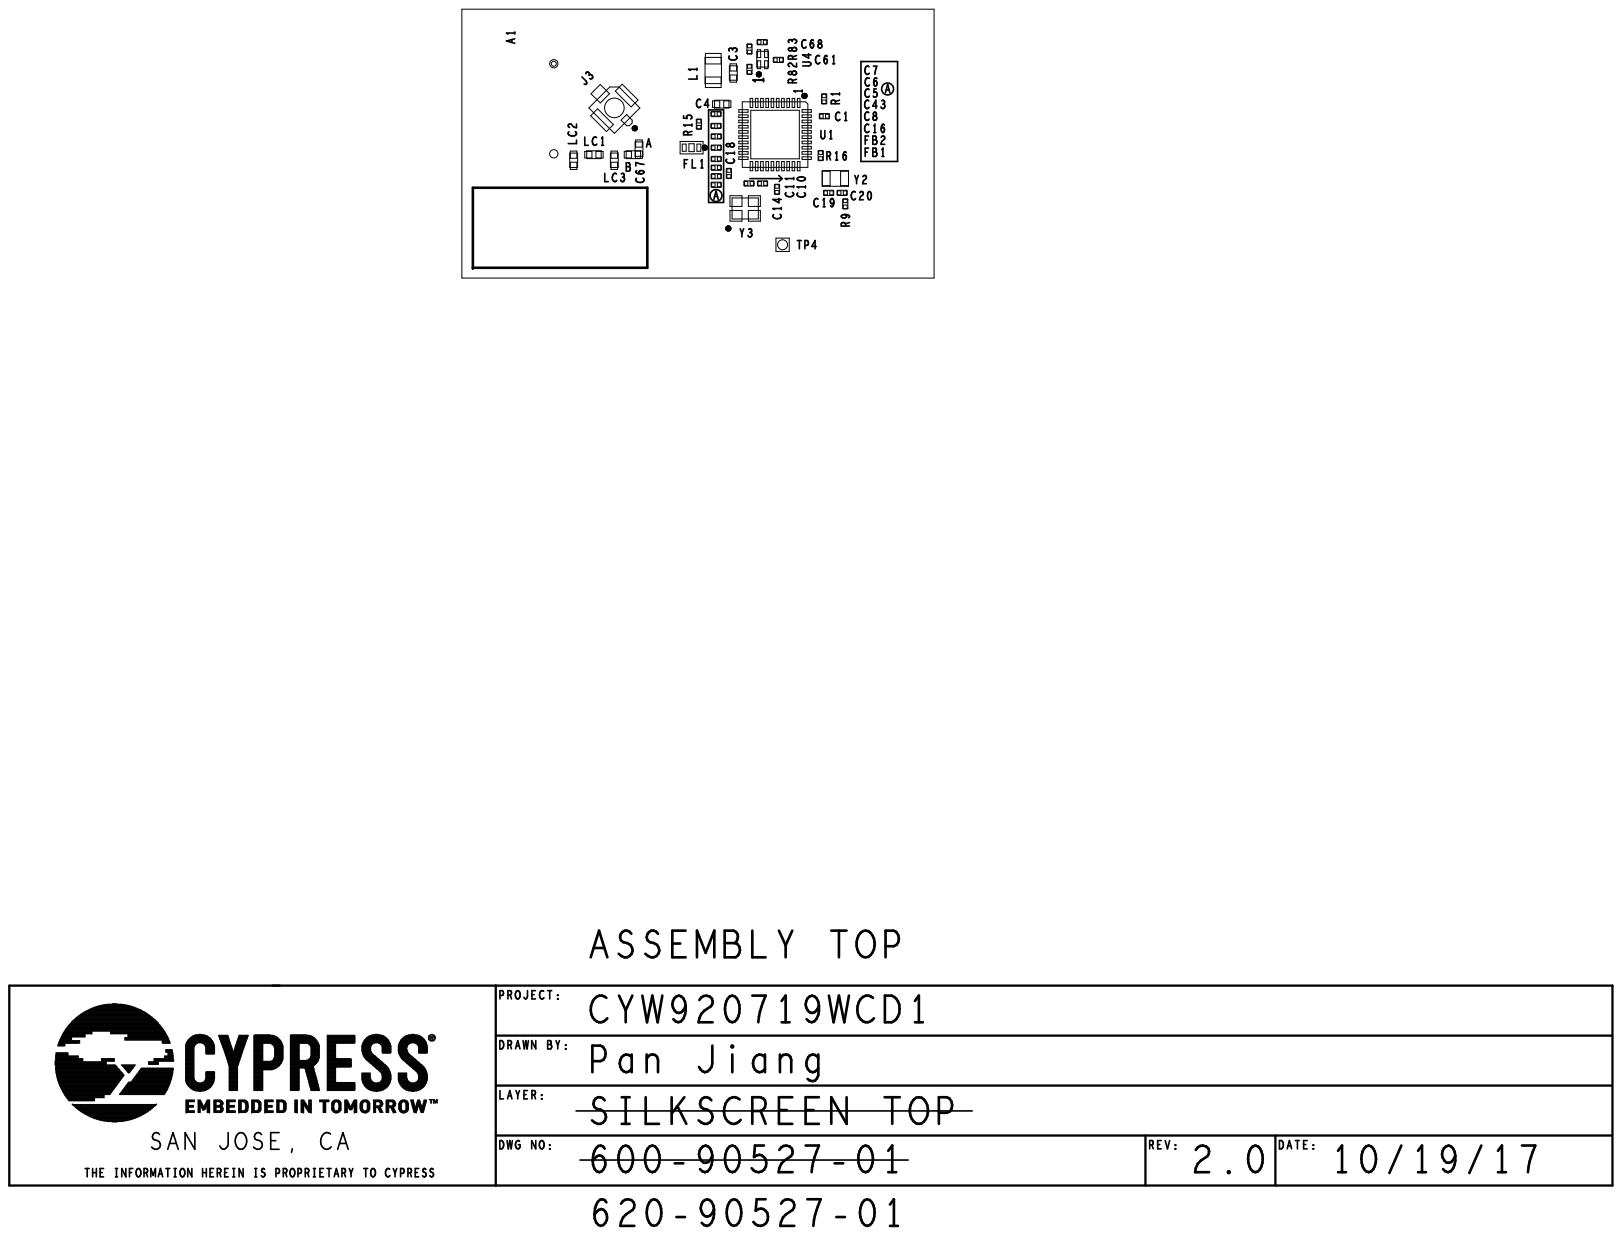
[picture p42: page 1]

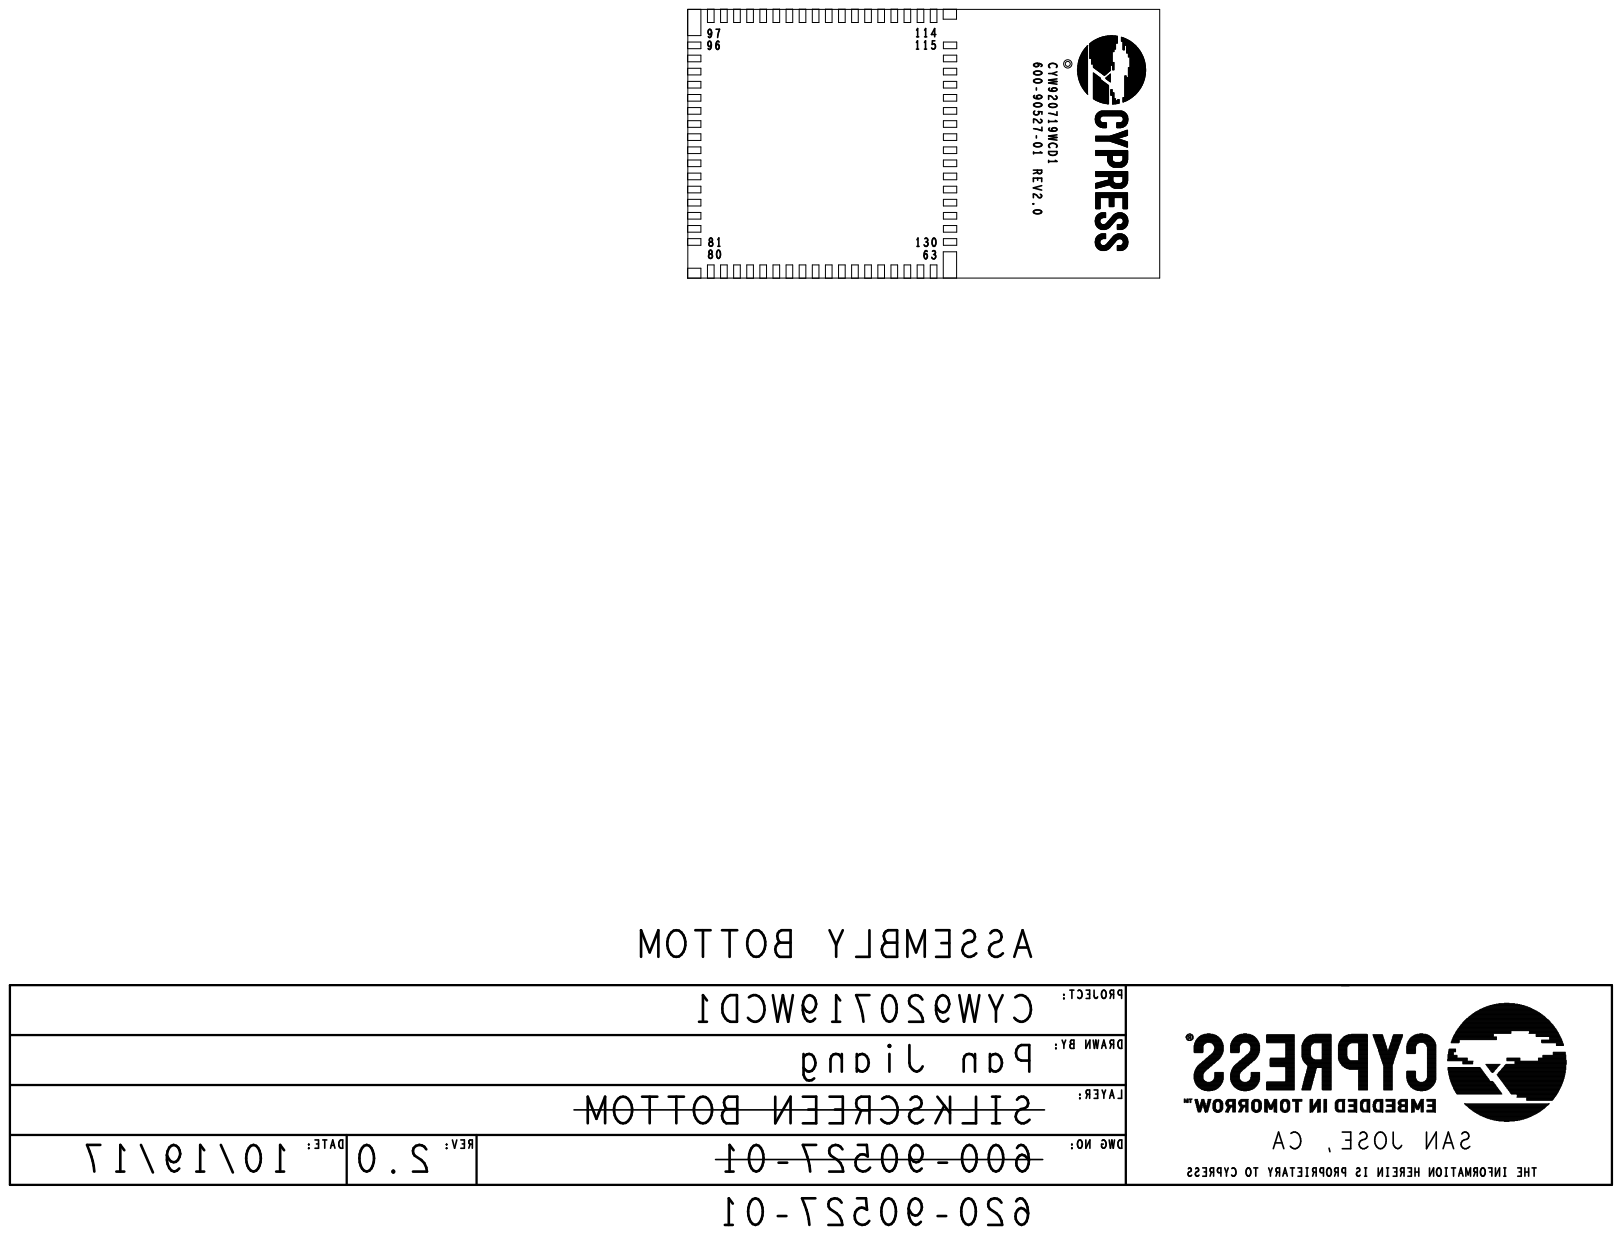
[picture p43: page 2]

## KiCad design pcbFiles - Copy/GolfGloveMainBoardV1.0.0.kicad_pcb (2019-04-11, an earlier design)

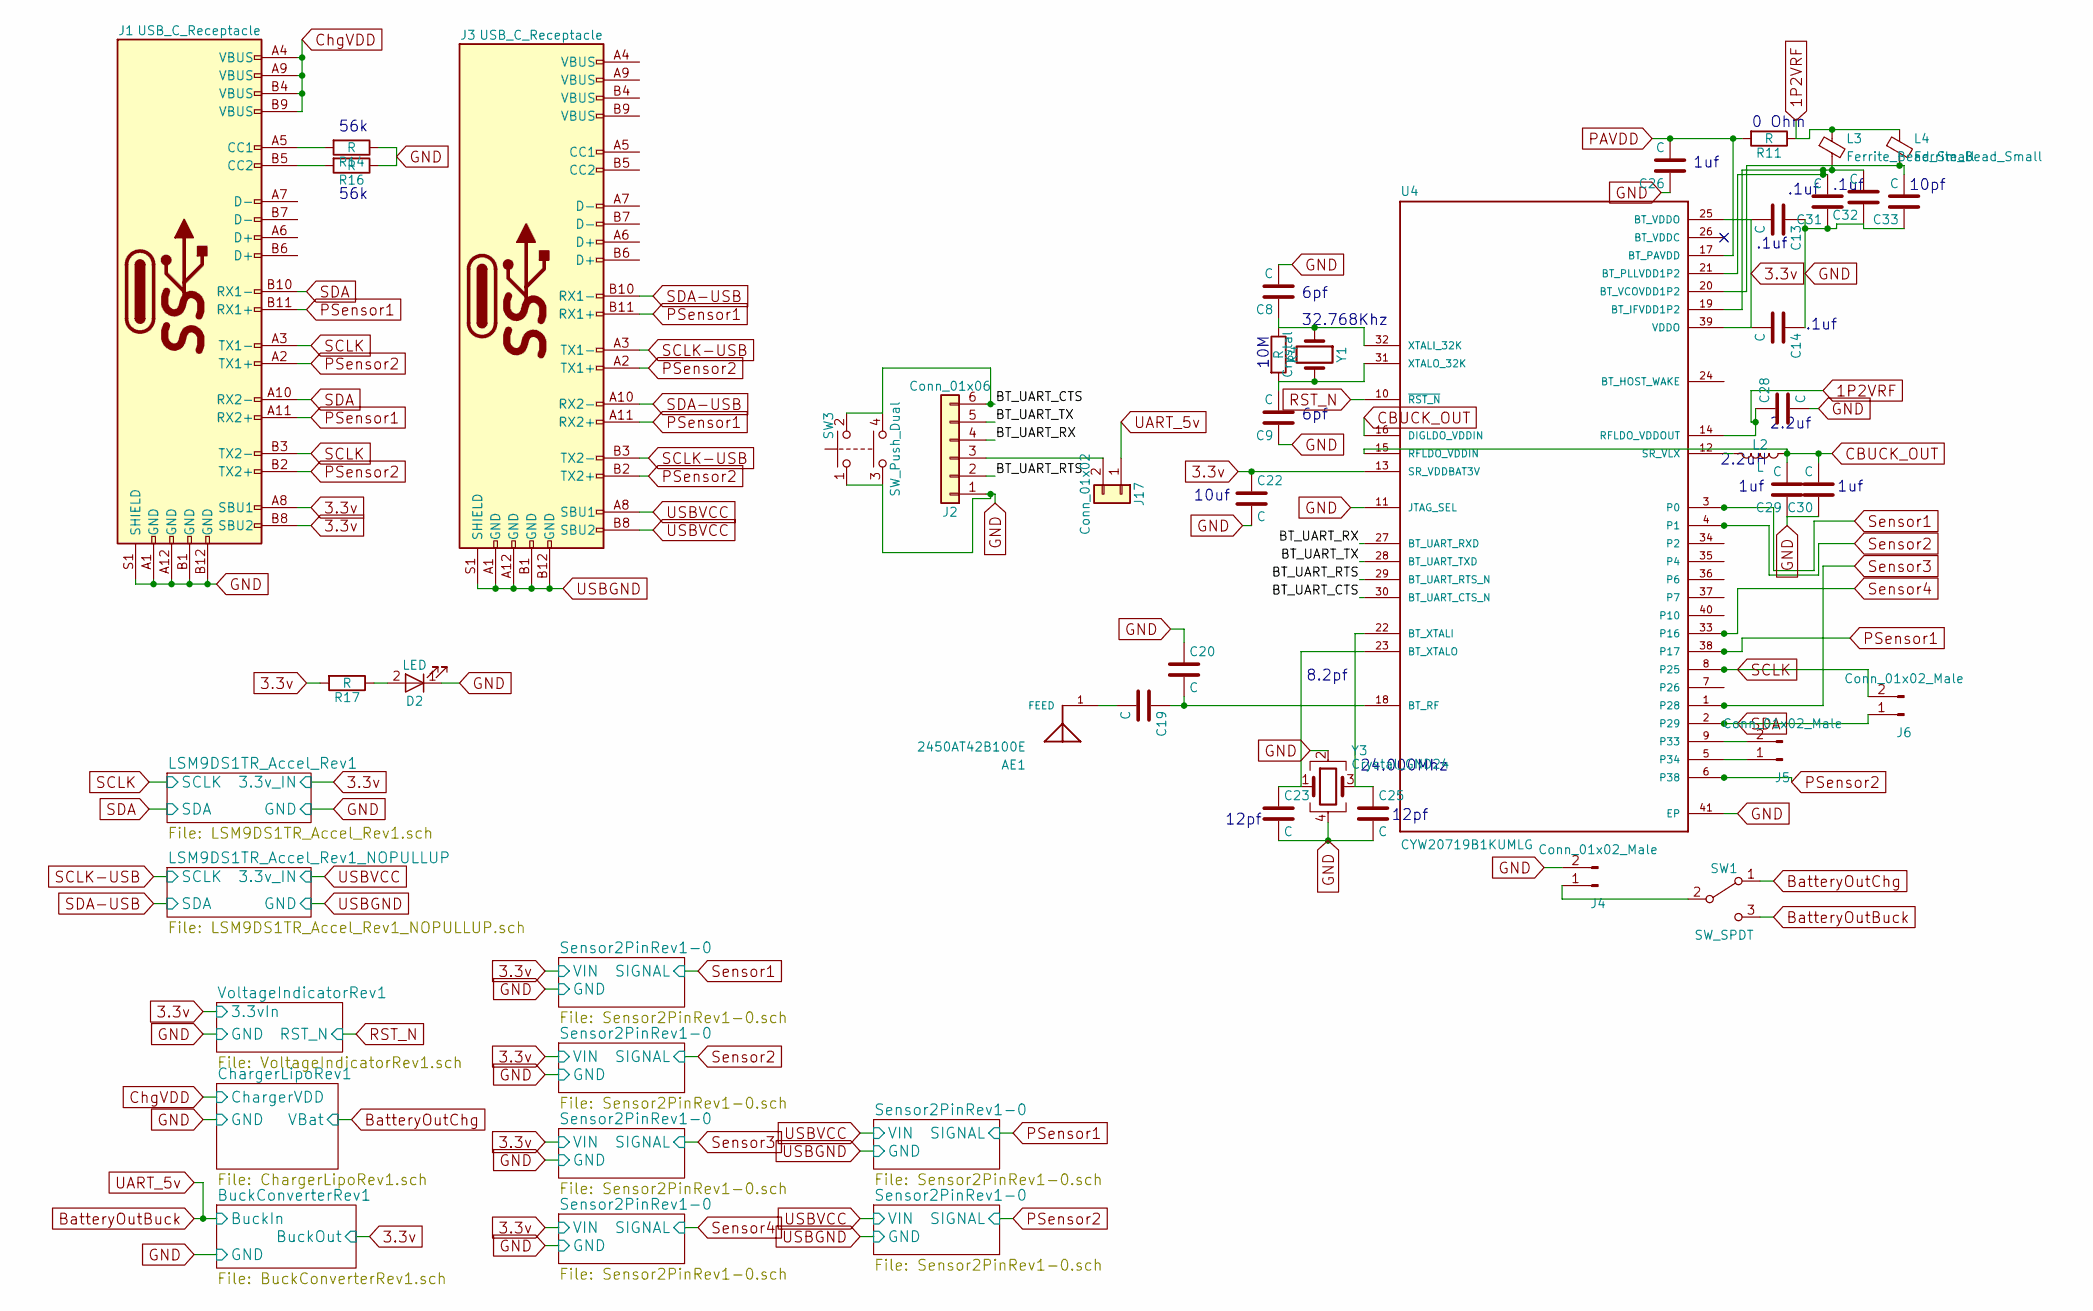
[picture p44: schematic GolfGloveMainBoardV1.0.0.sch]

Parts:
AE1: 2450AT42B100E; XCVR_2450AT42B100E
C8, C9, C13, C14, C19, C20, C22, C23, C25, C26, C28, C29, C30, C31, C32, C33: C; C_0402
D2: LED; C_0603
J1, J3: USB_C_Receptacle; USB_C_Receptacle_Amphenol_12401548E4-2A
J2: Conn_01x06; Pin_Header_Straight_1x06_Pitch2.54mm
J4, J5, J6: Conn_01x02_Male; Pin_Header_Straight_1x02_Pitch2.54mm
J17: Conn_01x02; Pin_Header_Straight_1x02_Pitch2.54mm
L2: L; L_0402
L3, L4: Ferrite_Bead_Small; R_0603
R4, R11, R14, R16, R17: R; R_0402
SW1: SW_SPDT; SW_SPDT_PCM12
SW3: SW_Push_Dual; SW_PUSH_6mm
U4: CYW20719B1KUMLG; QFN40P500X500X60-41N
Y1: Crystal; Crystal_SMD_3215-2pin_3.2x1.5mm
Y3: Crystal_GND24; Crystal_SMD_2016-4pin_2.0x1.6mm

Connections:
1P2VRF: C28.1, L3.1, L4.1, R11.1, U4.14 (RFLDO_VDDOUT)
3.3v: C13.2, C14.2, C22.1, J1.A8 (SBU1), J1.B8 (SBU2), R17.2, U4.13 (SR_VDDBAT3V), U4.25 (BT_VDDO), U4.39 (VDDO); also elsewhere on the board
/BT_UART_CTS: J2.6, SW3.2, SW3.4, U4.30 (BT_UART_CTS_N)
/BT_UART_RTS: J2.2, U4.29 (BT_UART_RTS_N)
/BT_UART_RX: J2.4, U4.27 (BT_UART_RXD)
/BT_UART_TX: J2.5, U4.28 (BT_UART_TXD)
BatteryOutBuck: J17.1, SW1.3 (C); also elsewhere on the board
BatteryOutChg: SW1.1 (A); also elsewhere on the board
CBUCK_OUT: C29.2, C30.2, L2.1, U4.15 (RFLDO_VDDIN), U4.16 (DIGLDO_VDDIN)
ChgVDD: J1.A4 (VBUS), J1.A9 (VBUS), J1.B4 (VBUS), J1.B9 (VBUS); also elsewhere on the board
GND: C8.2, C9.1, C13.1, C14.1, C20.1, C22.2, C23.2, C25.2, C26.1, C28.2, C29.1, C30.1, C31.1, C32.1, C33.1, D2.1 (K), J1.A1 (GND), J1.A12 (GND), J1.B1 (GND), J1.B12 (GND), J1.S1 (SHIELD), J2.1, J4.2, R14.1, R16.1, SW3.1, SW3.3, U4.11 (JTAG_SEL), U4.41 (EP), Y3.2, Y3.4; also elsewhere on the board
unnamed: AE1.1, C19.2
unnamed: C8.1, R4.1, U4.32 (XTALI_32K), Y1.1
unnamed: C9.2, R4.2, U4.31 (XTALO_32K), Y1.2
unnamed: C19.1, C20.2, U4.18 (BT_RF)
unnamed: C23.1, U4.23 (BT_XTALO), Y3.1
unnamed: C25.1, U4.22 (BT_XTALI), Y3.3
unnamed: C31.2, C32.2, L3.2, U4.19 (BT_IFVDD1P2), U4.21 (BT_PLLVDD1P2)
unnamed: C33.2, L4.2, U4.20 (BT_VCOVDD1P2)
unnamed: D2.2 (A), R17.1
unnamed: J1.A5 (CC1), R14.2
unnamed: J1.B5 (CC2), R16.2
unnamed: J4.1, SW1.2 (B)
unnamed: J5.1, U4.5 (P34)
unnamed: J5.2, U4.9 (P33)
unnamed: J2.3, J17.2
unnamed: L2.2, U4.12 (SR_VLX)
PAVDD: C26.2, R11.2, U4.17 (BT_PAVDD)
PSensor1: J1.A11 (RX2+), J1.B11 (RX1+), J3.A11 (RX2+), J3.B11 (RX1+), U4.38 (P17); also elsewhere on the board
PSensor2: J1.A2 (TX1+), J1.B2 (TX2+), J3.A2 (TX1+), J3.B2 (TX2+), U4.6 (P38); also elsewhere on the board
RST_N: U4.10 (~RST_N~); also elsewhere on the board
SCLK: J1.A3 (TX1-), J1.B3 (TX2-), J6.2, U4.8 (P25); also elsewhere on the board
SCLK-USB: J3.A3 (TX1-), J3.B3 (TX2-); also elsewhere on the board
SDA: J1.A10 (RX2-), J1.B10 (RX1-), J6.1, U4.2 (P29); also elsewhere on the board
SDA-USB: J3.A10 (RX2-), J3.B10 (RX1-); also elsewhere on the board
Sensor1: U4.3 (P0); also elsewhere on the board
Sensor2: U4.4 (P1); also elsewhere on the board
Sensor3: U4.1 (P28); also elsewhere on the board
Sensor4: U4.33 (P16); also elsewhere on the board
USBGND: J3.A1 (GND), J3.A12 (GND), J3.B1 (GND), J3.B12 (GND), J3.S1 (SHIELD); also elsewhere on the board
USBVCC: J3.A8 (SBU1), J3.B8 (SBU2); also elsewhere on the board

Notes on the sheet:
8.2pf
12pf
10uf
6pf
1uf
.1uf
10pf
2.2uf
2.2uH
0 Ohm
10M
32.768Khz
24.000Mhz
56k

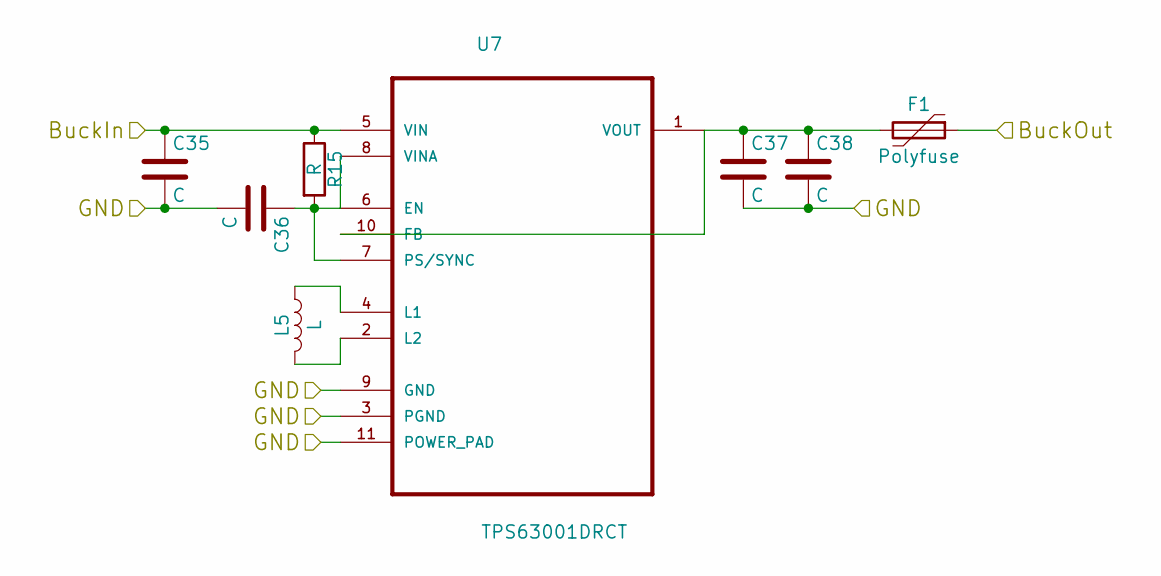
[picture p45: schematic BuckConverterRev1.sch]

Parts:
C35, C36, C37, C38: C; C_0402
F1: Polyfuse; R_0603_HandSoldering
L5: L; L_0603
R15: R; R_0402
U7: TPS63001DRCT; SON50P300X300X100-11N

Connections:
3.3v: F1.1; also elsewhere on the board
BatteryOutBuck: C35.1, R15.1, U7.5 (VIN); also elsewhere on the board
GND: C35.2, C36.2, C37.2, C38.2, U7.3 (PGND), U7.9 (GND), U7.11 (POWER_PAD); also elsewhere on the board
unnamed: C36.1, R15.2, U7.6 (EN), U7.7 (PS/SYNC), U7.8 (VINA)
unnamed: C37.1, C38.1, F1.2, U7.1 (VOUT), U7.10 (FB)
unnamed: L5.1, U7.4 (L1)
unnamed: L5.2, U7.2 (L2)

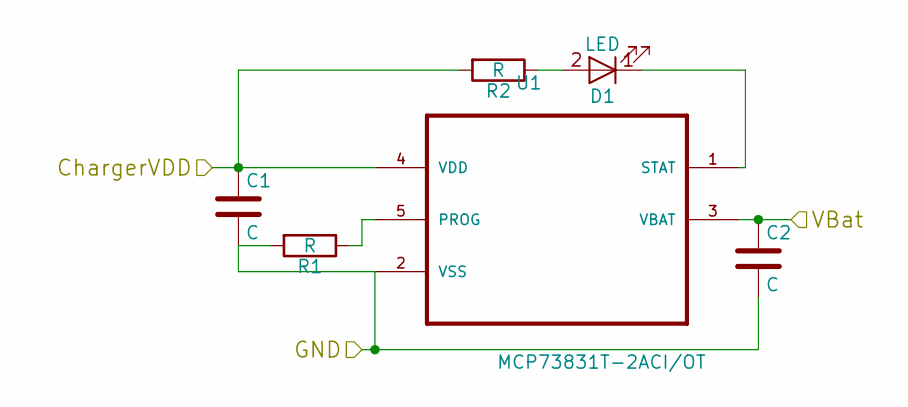
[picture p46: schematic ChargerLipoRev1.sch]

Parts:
C1, C2: C; C_0402
D1: LED; C_0603
R1, R2: R; R_0402
U1: MCP73831T-2ACI/OT; SOT95P280X145-5N

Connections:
BatteryOutChg: C2.1, U1.3 (VBAT); also elsewhere on the board
ChgVDD: C1.1, R2.2, U1.4 (VDD); also elsewhere on the board
GND: C1.2, C2.2, R1.2, U1.2 (VSS); also elsewhere on the board
unnamed: D1.1 (K), U1.1 (STAT)
unnamed: D1.2 (A), R2.1
unnamed: R1.1, U1.5 (PROG)

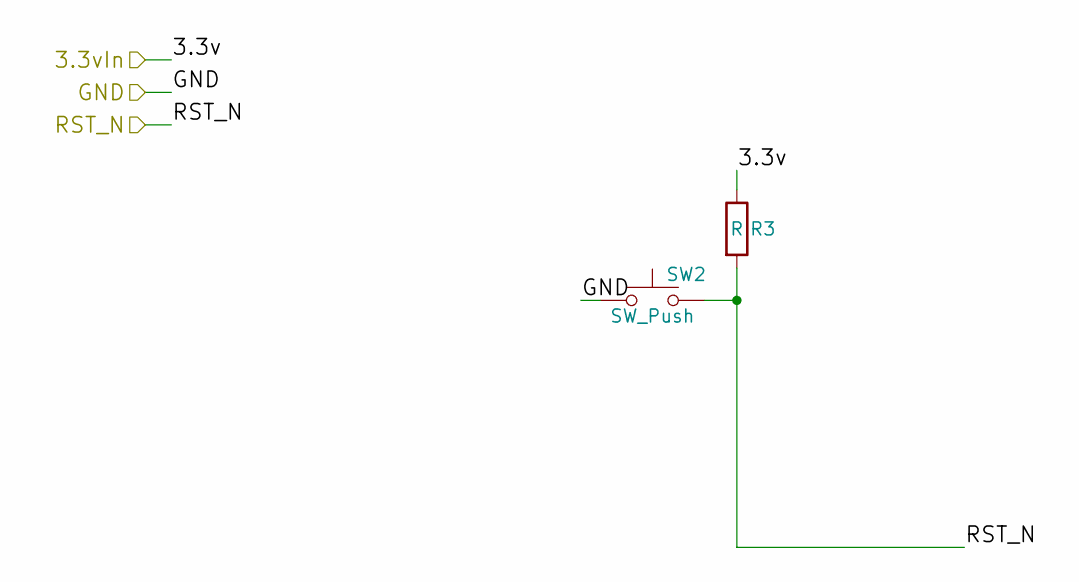
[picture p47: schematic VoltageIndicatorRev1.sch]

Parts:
R3: R; R_0402
SW2: SW_Push; SW_PUSH_6mm

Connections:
3.3v: R3.1; also elsewhere on the board
GND: SW2.1; also elsewhere on the board
RST_N: R3.2, SW2.2; also elsewhere on the board

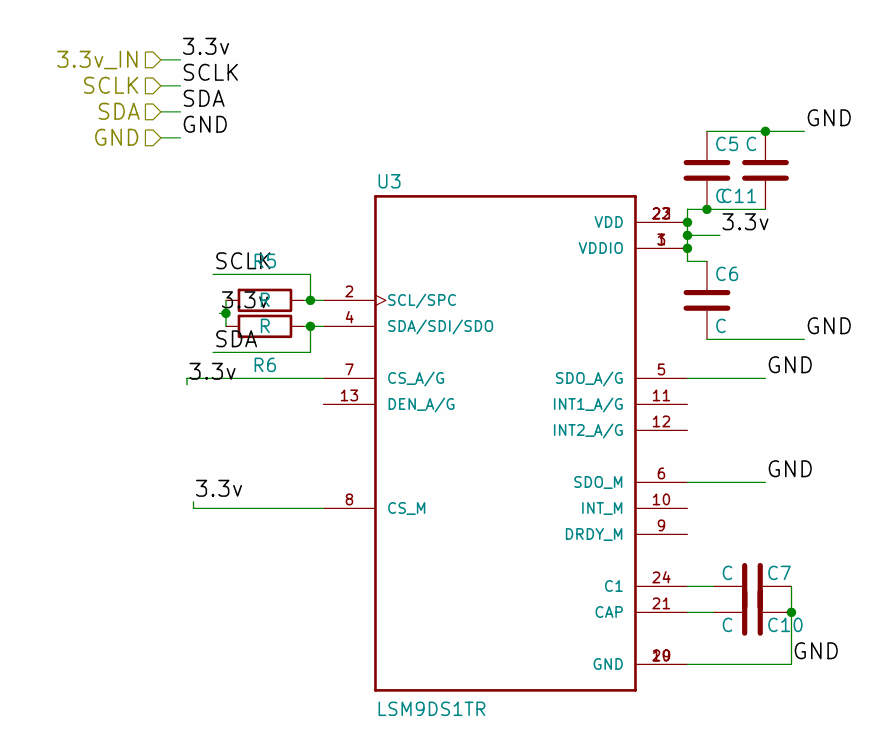
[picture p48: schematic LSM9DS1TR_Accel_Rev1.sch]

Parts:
C5, C6, C7, C10, C11: C; C_0402
R5, R6: R; R_0402
U3: LSM9DS1TR; PQFN43P300X350X102-24N

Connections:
3.3v: C5.2, C6.1, C11.1, R5.2, R6.2, U3.1 (VDDIO), U3.3 (VDDIO), U3.7 (CS_A/G), U3.8 (CS_M), U3.22 (VDD), U3.23 (VDD); also elsewhere on the board
GND: C5.1, C6.2, C7.1, C10.1, C11.2, U3.5 (SDO_A/G), U3.6 (SDO_M), U3.19 (GND), U3.20 (GND); also elsewhere on the board
unnamed: C7.2, U3.24 (C1)
unnamed: C10.2, U3.21 (CAP)
SCLK: R5.1, U3.2 (SCL/SPC); also elsewhere on the board
SDA: R6.1, U3.4 (SDA/SDI/SDO); also elsewhere on the board

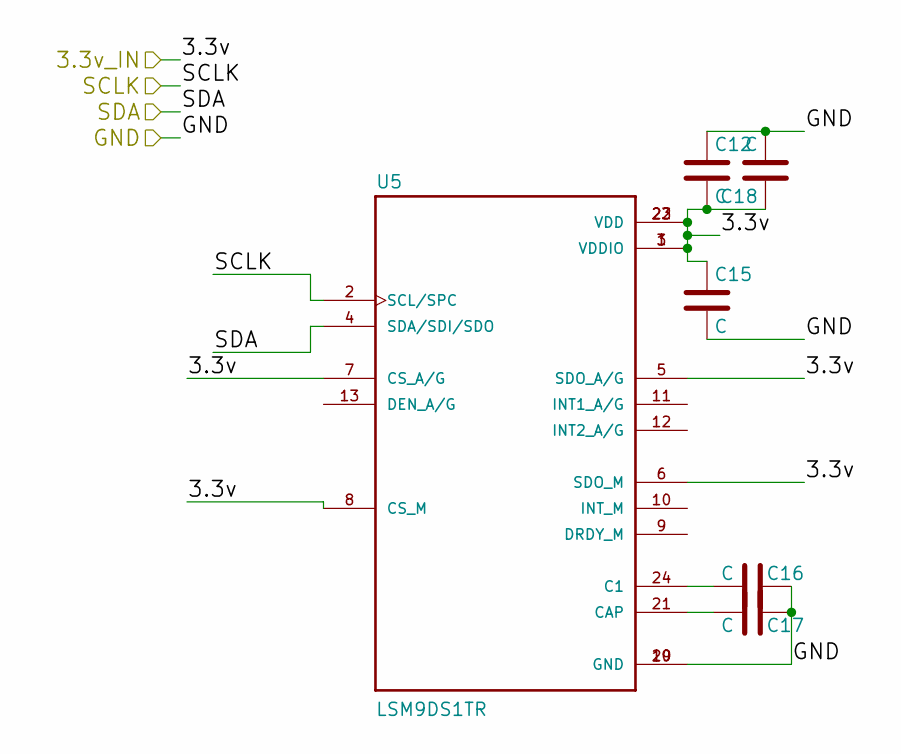
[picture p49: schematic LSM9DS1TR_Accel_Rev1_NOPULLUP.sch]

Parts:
C12, C15, C16, C17, C18: C; C_0402
U5: LSM9DS1TR; PQFN43P300X350X102-24N

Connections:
unnamed: C16.2, U5.24 (C1)
unnamed: C17.2, U5.21 (CAP)
SCLK-USB: U5.2 (SCL/SPC); also elsewhere on the board
SDA-USB: U5.4 (SDA/SDI/SDO); also elsewhere on the board
USBGND: C12.1, C15.2, C16.1, C17.1, C18.2, U5.19 (GND), U5.20 (GND); also elsewhere on the board
USBVCC: C12.2, C15.1, C18.1, U5.1 (VDDIO), U5.3 (VDDIO), U5.5 (SDO_A/G), U5.6 (SDO_M), U5.7 (CS_A/G), U5.8 (CS_M), U5.22 (VDD), U5.23 (VDD); also elsewhere on the board

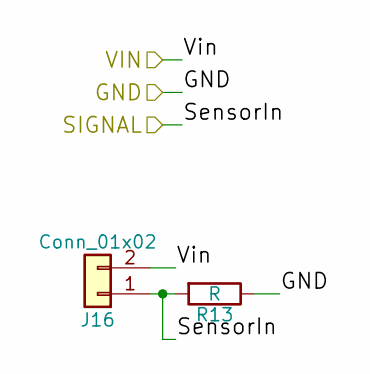
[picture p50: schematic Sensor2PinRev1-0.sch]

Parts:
J7: Conn_01x02; Pin_Header_Straight_1x02_Pitch2.54mm
R7: R; R_0402

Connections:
3.3v: J7.2; also elsewhere on the board
GND: R7.1; also elsewhere on the board
Sensor1: J7.1, R7.2; also elsewhere on the board

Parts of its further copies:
J8, J9, J14, J15, J16: Conn_01x02; Pin_Header_Straight_1x02_Pitch2.54mm
R8, R9, R10, R12, R13: R; R_0402

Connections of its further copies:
3.3v: J8.2, J9.2, J14.2; also elsewhere on the board
GND: R8.1, R9.1, R10.1; also elsewhere on the board
PSensor1: J15.1, R12.2; also elsewhere on the board
PSensor2: J16.1, R13.2; also elsewhere on the board
Sensor2: J8.1, R8.2; also elsewhere on the board
Sensor3: J9.1, R9.2; also elsewhere on the board
Sensor4: J14.1, R10.2; also elsewhere on the board
USBGND: R12.1, R13.1; also elsewhere on the board
USBVCC: J15.2, J16.2; also elsewhere on the board

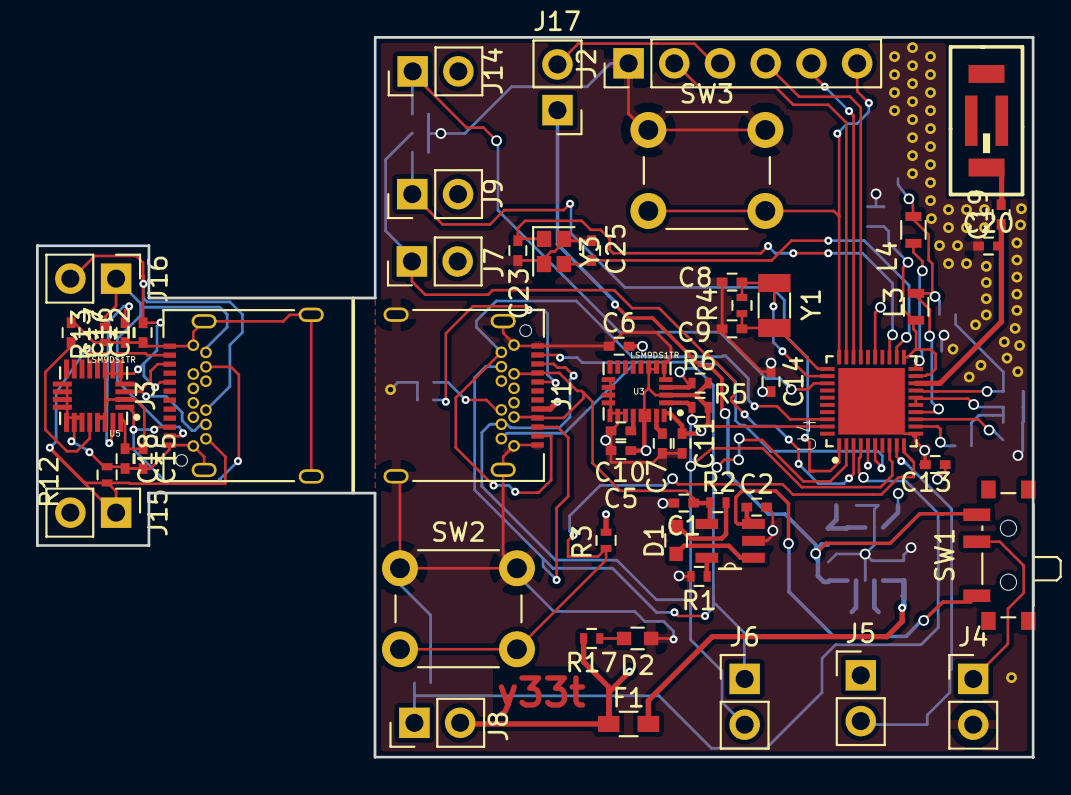
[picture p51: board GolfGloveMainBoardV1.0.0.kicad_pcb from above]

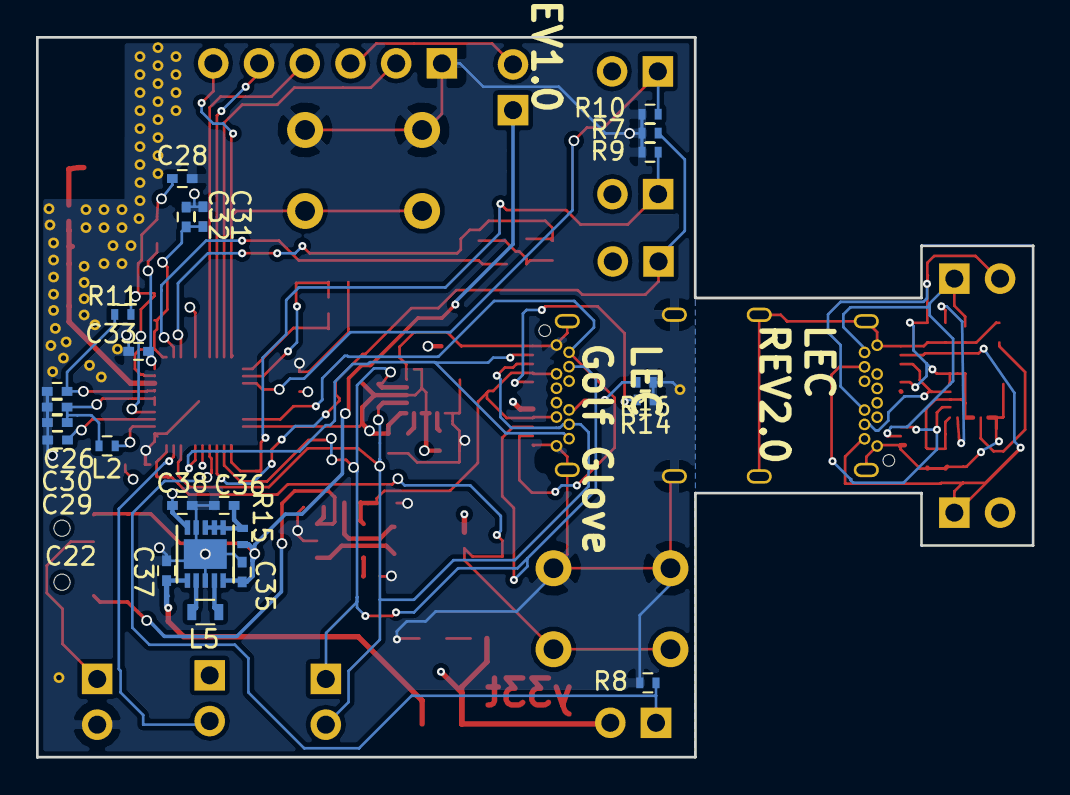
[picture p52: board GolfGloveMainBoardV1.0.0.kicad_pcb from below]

Board: 4 copper layers, 55.3 x 40.0 mm, 80 parts (23 on the bottom side), 52 nets.

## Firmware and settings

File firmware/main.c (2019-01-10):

/*
 * main.c
 *
 * Application startup procedures and event loop.
 */

#include "wiced_bt_trace.h"
#include "wiced_rtos.h"
#include "wiced_bt_gatt.h"
#include "wiced_timer.h"
#include "buffer/frame_buffer.h"
#include "gatt/golf_glove.h"
#include "sensor_polling.h"


wiced_thread_t* thread;
void do_thread(uint32_t arg);
void do_timer(uint32_t arg);

//static wiced_thread_t* sensor_loop_handle;

/**
 * Application entry point. Initializes BLE subsystem and application logic.
 */
void application_start(void) {
#if ((defined WICED_BT_TRACE_ENABLE) || (defined HCI_TRACE_OVER_TRANSPORT))
    /* Set the Debug UART as WICED_ROUTE_DEBUG_NONE to get rid of prints */
    //  wiced_set_debug_uart( WICED_ROUTE_DEBUG_NONE );

    /* Set Debug UART as WICED_ROUTE_DEBUG_TO_PUART to see debug traces on Peripheral UART (PUART) */
    wiced_set_debug_uart( WICED_ROUTE_DEBUG_TO_PUART );

    /* Set the Debug UART as WICED_ROUTE_DEBUG_TO_WICED_UART to send debug strings over the WICED debug interface */
    //  wiced_set_debug_uart( WICED_ROUTE_DEBUG_TO_WICED_UART );
#endif

    init_i2c();

    // Setup BLE stack/broadcasting
    gatt_application_start();

    // Init frame buffer
    //frame_buffer_init();

    //WICED_BT_TRACE("Main Sensor Loop\r\n");
    /*
    //new thread sensor_loop();
    sensor_loop_handle = wiced_rtos_create_thread();
    wiced_rtos_init_thread(sensor_loop_handle, THREAD_PRIORITY_MAX, "sensor_loop", sensor_loop, 512, NULL);
    */
    wiced_rtos_delay_milliseconds(3000, KEEP_THREAD_ACTIVE);

    thread = wiced_rtos_create_thread();
    wiced_rtos_init_thread(thread, 6, "Main Thread", do_thread, 256, NULL);
}

void do_thread(uint32_t arg) {
    wiced_timer_t timer;

    wiced_init_timer(&timer, do_timer, NULL, WICED_MILLI_SECONDS_PERIODIC_TIMER);
    wiced_start_timer(&timer, 1000);

    while (1) {
        wiced_rtos_delay_milliseconds(1000, ALLOW_THREAD_TO_SLEEP);
    }
}

void do_timer(uint32_t arg) {
    //WICED_BT_TRACE("AAAAAAAAAAAAAAAAA\r\n");
    wiced_bt_gatt_send_notification(1, 0x002A, 0, NULL);
}

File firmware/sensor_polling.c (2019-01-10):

#include "sensor_polling.h"

//need these for setup
#define LSM9DS1_INTERNAL_ADDRESS_ACCELGYRO (0x6A) /*Motion sensor slave address*/
#define LSM9DS1_INTERNAL_ADDRESS_MAG       (0x1C)
#define LSM9DS1_ADDRESS_ACCELGYRO          (0x6B)
#define LSM9DS1_ADDRESS_MAG                (0x1E)

// init
void init_i2c() {
    WICED_BT_TRACE("init_i2c()\r\n");
    wiced_hal_i2c_init();
    wiced_hal_i2c_set_speed(I2CM_SPEED_400KHZ);
    //sleep(1);
    lsm_begin(LSM9DS1_INTERNAL_ADDRESS_ACCELGYRO, LSM9DS1_INTERNAL_ADDRESS_MAG);
    lsm_begin(LSM9DS1_ADDRESS_ACCELGYRO, LSM9DS1_ADDRESS_MAG);
    ads_setup();
    ads_configureADC(ADS1015_1_ADDRESS, 3);
    ads_configureADC(ADS1015_2_ADDRESS, 3);
    ads_configureADC(ADS1015_3_ADDRESS, 3);
    ads_configureADC(ADS1015_4_ADDRESS, 3);
}

// Main Loop
void sensor_loop(uint32_t arg) {
    /*sensor_frame last;

     while (1) {
     sensor_frame current = get_sensor_frame();
     if (real_time) {
     sensor_frame swing[1] = {current};
     add_swing(swing);
     }
     if (detect_swing(current, last) == 1) frame_swing();
     // else sleep
     }*/
    while (1) {
        sensor_frame current = get_sensor_frame();
        frame_buffer_push_frame(&current);
        wiced_rtos_delay_milliseconds(8, KEEP_THREAD_ACTIVE);
    }
}

// Sensor polling logic
sensor_frame get_sensor_frame() {
    imu_frame imu1 = get_imu_frame_internal(); // Wrist
    imu_frame imu2 = get_imu_frame(); // Hand

    uint32_t timestamp = 0;
    UINT16 pres1 =          wiced_hal_adc_read_raw_sample(PRES1_PIN);
    UINT16 pres2 =          wiced_hal_adc_read_raw_sample(PRES2_PIN);
    UINT16 wrist1 =         ads_readADC_SingleEnded(ADS1015_1_ADDRESS);
    UINT16 wrist2 =         ads_readADC_SingleEnded(ADS1015_2_ADDRESS);
    UINT16 wrist3 =         ads_readADC_SingleEnded(ADS1015_3_ADDRESS);
    UINT16 wrist4 =         ads_readADC_SingleEnded(ADS1015_4_ADDRESS);
    uint8_t sync = 0;
    uint8_t avail = 0;

    sensor_frame rec = { timestamp, pres1, pres2, wrist1, wrist2, wrist3,
            wrist4, imu1, imu2, sync, avail };

    return rec;
}

void print_sensor_frame(sensor_frame rec) {
    /*
    WICED_BT_TRACE("timestamp %u\r\n", rec.timestamp);
    WICED_BT_TRACE("pres1     %u\r\n", rec.pres1);
    WICED_BT_TRACE("pres2     %u\r\n", rec.pres2);
    WICED_BT_TRACE("wrist1    %u\r\n", rec.wrist1);
    WICED_BT_TRACE("wrist2    %u\r\n", rec.wrist2);
    WICED_BT_TRACE("wrist3    %u\r\n", rec.wrist3);
    WICED_BT_TRACE("wrist4    %u\r\n", rec.wrist3);
    WICED_BT_TRACE("imu1        \r\n");
    WICED_BT_TRACE("    accX  %u\r\n", rec.imu1.accX);
    WICED_BT_TRACE("    accY  %u\r\n", rec.imu1.accY);
    WICED_BT_TRACE("    accZ  %u\r\n", rec.imu1.accZ);
    WICED_BT_TRACE("    magX  %u\r\n", rec.imu1.magX);
    WICED_BT_TRACE("    magY  %u\r\n", rec.imu1.magY);
    WICED_BT_TRACE("    magZ  %u\r\n", rec.imu1.magZ);
    WICED_BT_TRACE("    gyroX %u\r\n", rec.imu1.gyroX);
    WICED_BT_TRACE("    gyroY %u\r\n", rec.imu1.gyroY);
    WICED_BT_TRACE("    gyroZ %u\r\n", rec.imu1.gyroZ);
    WICED_BT_TRACE("imu2        \r\n");
    WICED_BT_TRACE("    accX  %u\r\n", rec.imu2.accX);
    WICED_BT_TRACE("    accY  %u\r\n", rec.imu2.accY);
    WICED_BT_TRACE("    accZ  %u\r\n", rec.imu2.accZ);
    WICED_BT_TRACE("    magX  %u\r\n", rec.imu2.magX);
    WICED_BT_TRACE("    magY  %u\r\n", rec.imu2.magY);
    WICED_BT_TRACE("    magZ  %u\r\n", rec.imu2.magZ);
    WICED_BT_TRACE("    gyroX %u\r\n", rec.imu2.gyroX);
    WICED_BT_TRACE("    gyroY %u\r\n", rec.imu2.gyroY);
    WICED_BT_TRACE("    gyroZ %u\r\n", rec.imu2.gyroZ);
    WICED_BT_TRACE("sync      %u\r\n", rec.sync);
    WICED_BT_TRACE("avail     %u\r\n", rec.avail);
    */

   WICED_BT_TRACE("{ %x %x %x %x %x %x }\r\n", rec.pres1, rec.pres2, rec.wrist1, rec.wrist2, rec.wrist3, rec.wrist4);
   WICED_BT_TRACE("{ %x %x %x %x %x %x %x %x %x }\r\n", rec.imu1.accX, rec.imu1.accY, rec.imu1.accZ, rec.imu1.magX, rec.imu1.magY, rec.imu1.magZ, rec.imu1.gyroX, rec.imu1.gyroY, rec.imu1.gyroZ);
   WICED_BT_TRACE("{ %x %x %x %x %x %x %x %x %x }\r\n\r\n", rec.imu2.accX, rec.imu2.accY, rec.imu2.accZ, rec.imu2.magX, rec.imu2.magY, rec.imu2.magZ, rec.imu2.gyroX, rec.imu2.gyroY, rec.imu2.gyroZ);

}

imu_frame get_imu_frame() {
    lsm_read();

    UINT16 accX = accelData.x;
    UINT16 accY = accelData.y;
    UINT16 accZ = accelData.z;
    UINT16 magX = magData.x;
    UINT16 magY = magData.y;
    UINT16 magZ = magData.z;
    UINT16 gyroX = gyroData.x;
    UINT16 gyroY = gyroData.y;
    UINT16 gyroZ = gyroData.z;

    imu_frame rec = { accX, accY, accZ, magX, magY, magZ, gyroX, gyroY, gyroZ }; //null data

    return rec;
}

imu_frame get_imu_frame_internal() {

    lsm_read_internal();

    UINT16 accX = accelData.x;
    UINT16 accY = accelData.y;
    UINT16 accZ = accelData.z;
    UINT16 magX = magData.x;
    UINT16 magY = magData.y;
    UINT16 magZ = magData.z;
    UINT16 gyroX = gyroData.x;
    UINT16 gyroY = gyroData.y;
    UINT16 gyroZ = gyroData.z;

    imu_frame rec = { accX, accY, accZ, magX, magY, magZ, gyroX, gyroY, gyroZ }; //null data

    return rec;
}

// Swing Detection/frameing
int detect_swing(sensor_frame current, sensor_frame last) {
    if (current.pres1 > last.pres2) {
        return 1;
    }
    return 0;
}

void frame_swing() {

    int i = 0;
    sensor_frame* swing = (sensor_frame*) malloc(
            sizeof(sensor_frame) * 3 * POLL_RATE); //max swing length 3 seconds
    while (1) {
        if (i == 3 * POLL_RATE)
            break;
        swing[i++] = get_sensor_frame();
        if (i > 0 && !detect_swing(swing[i], swing[i - 1]))
            break;
    }
}

// Data pushing/updating
void add_swing(sensor_frame* swing) {
    // TODO: Push swing data to coaching application maybe by updating a global array that the BT side of the program reads from?
}

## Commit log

2018-11-02 Added additional sensor traits to GATT
2018-11-07 Correct the implementation of websockets with socket.io
2018-11-10 Fix TestChart.js mounting issue
2018-11-11 implemented frame buffer data structure and functions (not yet tested)
2018-11-12 Initial code for communicating with accelerometer.
2018-11-13 More work to fix accelero errors
    [LSM9DS1.c, LSM9DS1.h, main.c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]
2018-11-14 made final changes to .wic file added temporary single frame frame buffer fixed advertisement bugs
    [main.c]
2018-11-14 Realtime Data flow from glove to computer.
2018-11-17 Fixed issues in sensor polling.
    [sensor_polling.c]
2018-11-19 fixed a couple disconnect bugs. Also set up constant reading, waiting on firmware update.
2018-11-19 Add NextFrame class for parsing frame data
2018-11-20 Add frontend routes for connect/disconnect device and start/stop data
2018-11-20 Updated firmware to include ADS adc, i2c operations, and updates to LSM9.
2018-11-20 Fixes to ads methods and misc.
    [ADS1015.c, sensor_polling.c]
2018-11-21 Change pin number for pressure sensor readouts
2018-11-21 Fix Typos, all sensors now read correctly
    [ADS1015.c, i2c_operations.c]
2018-11-26 Updates to sensor-polling to support multiple ADS modules
2018-11-26 finished writing imu parsing. needs testing
2018-11-26 tested and working imu parsing
2018-11-27 Updates to ADS, LSM, i2c, and main file.
2018-11-27 Fix frame message being sent to frontend
2018-12-04 fixed stop request crashing the backend when no device is connected
2019-01-23 Added PCB KiCad Files
    Files that are of the current PCB Designs
    [GolfGloveMainBoardV1.0.0.kicad_pcb, GolfGloveMainBoardV1.0.0.sch]
2019-01-24 Update circuit subsys with sheets
    Charging, IMU's, VoltageIndicator, Buck/Boost now have sheets with pinouts, awaiting review and connection in next commit by @willcarroll7
    [BuckConverterRev1.sch, ChargerLipoRev1.sch, GolfGloveMainBoardV1.0.0.kicad_pcb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]
2019-01-25 Update the circuit schematic
    [BuckConverterRev1.sch, ChargerLipoRev1.sch, GolfGloveMainBoardV1.0.0.sch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]
2019-02-05 updated uart comm lines
    [BuckConverterRev1.sch, ChargerLipoRev1.sch, GolfGloveMainBoardV1.0.0.sch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]
2019-02-05 Update Footprints and Board Layers
    Still need to get foorprint for x... device and the lpf may need to make them if I cannot find them @willcarroll7
    [BuckConverterRev1.sch, ChargerLipoRev1.sch, GolfGloveMainBoardV1.0.0.kicad_pcb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]
2019-02-05 Add Pin Header For 5v UART Connection
    Added a 1x2 2.54mm Pitch pin header for the 5v UART line. This line feeds directly into the pin of the buck converter and therefore we will need to be sure to NOT turn on the device when programming 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
    [BuckConverterRev1.sch, ChargerLipoRev1.sch, GolfGloveMainBoardV1.0.0.sch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]
2019-02-05 Update the Voltage Detector Footprint
    [ChargerLipoRev1.sch, GolfGloveMainBoardV1.0.0.kicad_pcb, GolfGloveMainBoardV1.0.0.sch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]
2019-02-05 Remove Antenna
    [GolfGloveMainBoardV1.0.0.sch]
2019-02-05 Add Antenna And Inductors
    Added Inductors and Antenna to the schematic based on the 2450AT42B100E Datasheet. @willcarroll7
    [BuckConverterRev1.sch, ChargerLipoRev1.sch, GolfGloveMainBoardV1.0.0.sch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]
2019-02-06 Update Circuit With Antenna
    This commit will update the pcb with a mock up of the antenna design without the vias, this commit will also update the pressure sensors to be attached to the top of hand unit to allow for USB-C Conn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
    [BuckConverterRev1.sch, ChargerLipoRev1.sch, GolfGloveMainBoardV1.0.0.kicad_pcb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]
2019-02-11 Update Board Files
    Updated schematic files, completed REV1.0 of the board design, waiting for review by @willcarroll7
    [BuckConverterRev1.sch, ChargerLipoRev1.sch, GolfGloveMainBoardV1.0.0.kicad_pcb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]
2019-02-11 Update Fills and Outlines
    [GolfGloveMainBoardV1.0.0.kicad_pcb]
2019-02-14 Fix Vias
    Updated to brand new vias and also fixed plane issue around antenna
    [GolfGloveMainBoardV1.0.0.kicad_pcb]
2019-02-20 Update Docs
    @willcarroll7
    [GolfGloveMainBoardV1.0.0-B.Cu.gbr, GolfGloveMainBoardV1.0.0-B.Mask.gbr, GolfGloveMainBoardV1.0.0-B.Paste.gbr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]
2019-02-23 Update Order Folder
    @cbb330
    [GolfGlovePartListRev1.xlsx]
2019-04-09 Remove Headers
    [GolfGloveMainBoardV1.0.0.sch]
2019-04-10 Ready For Review
    [BuckConverterRev1.sch, GolfGloveMainBoardV1.0.0.kicad_pcb, GolfGloveMainBoardV1.0.0.sch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]
2019-04-10 Add LED for Power Indication
    [GolfGloveMainBoardV1.0.0.kicad_pcb, GolfGloveMainBoardV1.0.0.sch, Sensor2PinRev1-0.sch]
2019-04-10 Removed Humorous Text
    [GolfGloveMainBoardV1.0.0.sch]
2019-04-10 Fix LSM footprints
    [GolfGloveMainBoardV1.0.0.kicad_pcb]
2019-06-29 Update To Rev3
    [2019-05-28T054210.xlsx, 600-90523-01_CYW9BTWCDEVAL1_REV2.0.brd, 600-90527-01_CYW920719WCD1_REV2.0.brd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]
